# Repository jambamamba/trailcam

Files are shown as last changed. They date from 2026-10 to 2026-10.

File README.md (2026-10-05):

# Wapiti Trail Camera

Wapiti is an open-hardware cellular trail camera built for the harshest hunts: a 4K-capable IMX415 (8.4 MP) sensor on an SSC377Q SoC, an EG915U LTE Cat-1bis modem with GNSS and eSIM, and an ESP32-C6 wake supervisor that owns the heartbeat, PIR/radar wakeups and cold-start power sequencing. It runs through −40 °C on drawer batteries plus solar (with a sub-zero charge interlock), backed by a 5 F supercap that rides through radio bursts. A mitten-friendly hi-vis battery drawer swaps packs in seconds, dual 940/850 nm IR illuminators cover day and night, and an LD2410 mmWave radar confirms presence before the main SoC ever wakes up. Tree straps and a ¼-20 tripod boss mount it to any tree; BLE-gated on-demand Wi-Fi pulls photos straight to a phone at the camera — no LTE data, no coverage needed. Every photo and clip is encrypted at rest with per-device keys, so a stolen camera or SD card yields hardware, never your media. Every artifact in this repo — schematics, footprints, PCB, chassis and renders — regenerates from Python scripts.

<p align="center">
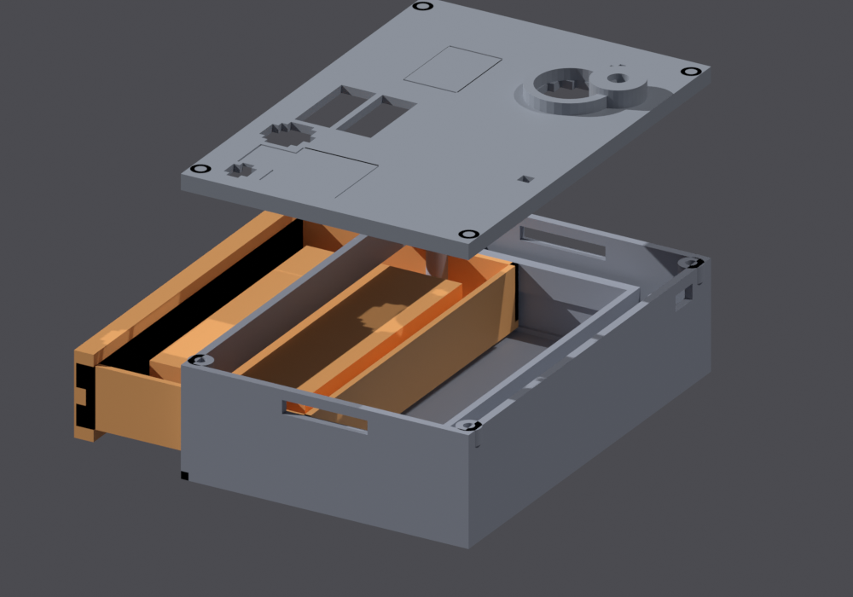
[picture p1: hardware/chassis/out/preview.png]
  
  <br><em>Exploded chassis view (lid, base, battery drawer). STLs, drawings and regeneration commands in the <a href="hardware/README.md">hardware guide</a>.</em>
</p>

## Documentation

| Document | What's inside |
| --- | --- |
| [Project plan](docs/project-plan.md) | Architecture, BOM & power budget (§4), Yocto firmware plan (meta-wapiti / yocto-cam) |
| [Test plan](docs/test-plan.md) | 301 test IDs across all subsystems, incl. YOCT-01…06 firmware bring-up |
| [Competitive analysis](docs/competitive-analysis.md) | Positioning vs Tactacam Reveal and peers; −40 °C power strategy (§4.2), mitten-swap chassis (§4.13) |
| [Tactacam Reveal research report](docs/tactacam-reveal-hunt-cameras-product-research-report.md) | Product research on the market-leading cellular trail camera |
| [Hardware guide](hardware/README.md) | Schematic/PCB/chassis artifacts, regeneration commands, PCB↔chassis mapping, Value SKU (wapiti-lite) |

## Quick facts

- **Product:** cellular trail camera, 4K / 8.4 MP, radar-confirmed instant wakeups.
- **Value SKU:** **wapiti-lite** — same board with the LD2410 radar assembled DNP.
- **Connectivity:** EG915U LTE Cat-1bis + GNSS, eSIM out of the box.
- **Power:** solar input with a <0 °C charge interlock, 5 F supercap ride-through for radio bursts.
- **Enclosure:** 108 × 74 × 33 mm chassis with 0.8 mm RF-window membranes; hi-vis mitten-swap battery drawer.
- **Firmware:** Yocto Linux — `meta-wapiti` BSP + `yocto-cam` image.
- **Reproducibility:** everything regenerates from the scripts in [`hardware/`](hardware/README.md) — no manual KiCad edits.

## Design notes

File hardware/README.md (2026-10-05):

# wapiti hardware — generated KiCad + 3D-printable chassis

Everything in this directory is **generated from Python** (no hand-edited CAD), using the same
approach as the `luggage-tracker` LT-1: emitters write KiCad s-expressions with symbols embedded
inline (lib prefix `wapiti:`), custom footprints go to `wapiti.pretty/`, and `kicad-cli` validates
the results. Hardware stays reviewable in diffs and regenerable from the BOM in
[project-plan §4–5](../docs/project-plan.md).

wapiti chassis — base, lid and hi-vis battery drawer

wapiti PCB — front copper, silkscreen, outline

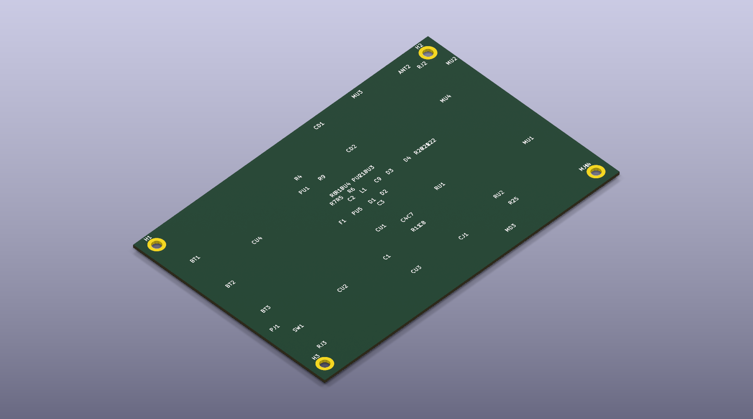
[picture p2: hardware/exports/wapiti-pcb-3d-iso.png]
wapiti PCB — 3D render (isometric)


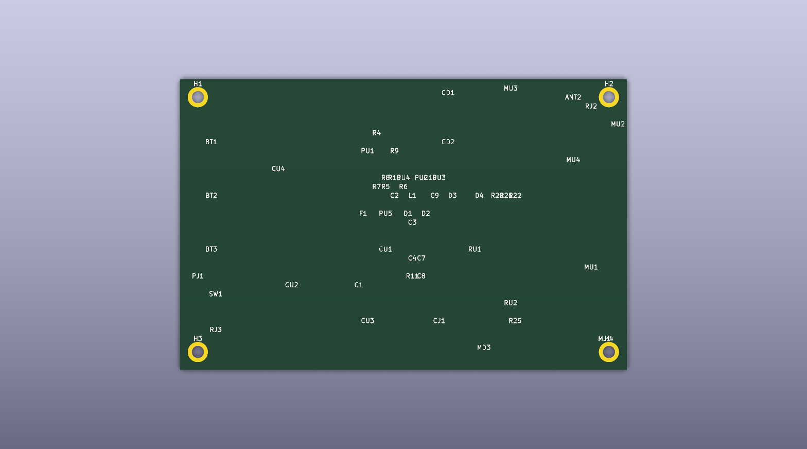
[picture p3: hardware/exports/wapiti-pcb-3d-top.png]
wapiti PCB — 3D render (top)


## Artifacts

| Artifact | Produced by | What it is |
|---|---|---|
| `wapiti.kicad_sch` | `gen_schematic.py` | Root sheet with 4 child sheets (power / radio / cam / mcu) |
| `power.kicad_sch` | `gen_schematic.py` | BT1 smart 2S pack (Pack_Conn_5p: pack-ID + BQ27441 + thermistor), BT2 12×AA Li-FeS₂ tray, BT3 CR2032 anti-theft reserve, C1 5 F supercap ride-through (mitten swap), F1/F2 PTCs, D1/D3/D4 SS54 OR-ing, D2 TVS, J1 solar + U4 interlock (SOLAR_OK < 0 °C = PWR-08), U1 buck → V_SYS 3.8 V, U2/U3 load switches (EN_CAM/EN_MODEM from the C6), U5 gauge |
| `radio.kicad_sch` | `gen_schematic.py` | U1 EG915U LTE Cat-1bis + GNSS, U2 eSIM, J2 user-replaceable SMA (CAM-14), ANT2 GNSS patch under the lid RF membrane, J3 USB-C service |
| `cam.kicad_sch` | `gen_schematic.py` | U1 SSC377Q SoC, U2 IMX415 8.4 MP module, U3 eMMC + J1 microSD overflow, U4 2.0″ SPI LCD, D1/D2 IR arrays (940 nm no-glow / 850 nm low-glow) on Q1/Q2 low-side MOSFETs with 100 k gate pulldowns (dark through boot) |
| `mcu.kicad_sch` | `gen_schematic.py` | U1 ESP32-C6-WROOM-1 wake supervisor (owns the heartbeat HB-01..08), U2 LIS2DW12 (ACCEL_INT tamper wake), U3 AS312 PIR, U4 LD2410 radar (**value-SKU DNP candidate**), R25 + D3 status LED, SW1, J1 2×03 factory-programming header, J2 USB-C |
| `verify_schematic.py` | — | Union-find net verifier over the generated sheets (headless, no KiCad needed) |
| `wapiti.pretty/*.kicad_mod` | `gen_footprints.py` | 30 footprints (Pack_Conn_5p, EG915U, ESP32-C6-WROOM-1, SSC377Q_QFN, IMX415_Module, eMMC_153, microSD_Push, LCD_2in_FPC, IR_Array_30x10, PIR_Dome, Radar_LD2410, Diode_SMA for the SS54s, …) |
| `wapiti.kicad_pcb` | `gen_pcb.py` | 100 × 65 mm board, 58 placed footprints + 4 mounting holes, F.Cu zone, F.Fab front-panel-optics + antenna keep-outs |
| `wapiti.kicad_pro`, `fp-lib-table` | `gen_pcb.py` | Project file + footprint-lib registration via `${KIPRJMOD}` |
| `exports/` | `validate.sh` | `wapiti-pcb.svg`, per-sheet PDFs, `wapiti.step` (PCB 3D) |
| `exports/wapiti-pcb-3d-{top,iso}.png` | `kicad-cli pcb render` | PCB 3D screenshot, top + isometric (quality `high`) |
| `chassis/out/wapiti-{base,lid,tray}.{stl,obj}` | `chassis/gen_chassis_stl.py` | 3D-printable chassis + battery drawer; side-wall strap slots + lid ¼-20 boss (constructive geometry, no booleans) |
| `chassis/out/preview.svg`, `preview-plan.svg` | `chassis/gen_preview_svg.py` | Isometric (lid +45 z, drawer pulled −Y) and top-down interior previews |
| `chassis/gen_chassis.py` | — | Blender batch **renderer**: imports the verified STLs → `out/preview.png` (exploded), `out/preview-assembled.png`, `out/preview-top.png` |

## Regenerate

```bash
cd hardware
python3 gen_schematic.py       # 5 schematic files (root + power/radio/cam/mcu)
python3 verify_schematic.py    # -> "All schematic net checks passed"
python3 gen_footprints.py      # wapiti.pretty/ (30 footprints)
python3 gen_pcb.py             # wapiti.kicad_pcb + .kicad_pro + fp-lib-table
bash validate.sh               # kicad-cli export -> exports/  (needs KiCad AppImage)
# PCB 3D screenshot (KiCad 10):
kicad-cli pcb render --output exports/wapiti-pcb-3d-top.png --side top \
  --background opaque --quality high wapiti.kicad_pcb
kicad-cli pcb render --output exports/wapiti-pcb-3d-iso.png --rotate "-45,0,45" \
  --background opaque --quality high wapiti.kicad_pcb

cd chassis
python3 gen_chassis_stl.py     # out/wapiti-{base,lid,tray}.{stl,obj}
python3 gen_preview_svg.py     # out/preview.svg out/preview-plan.svg
~/Downloads/blender-5.2.0-linux-x64/blender -b -P gen_chassis.py   # out/preview*.png
```

Current status: schematic net verification passes; `validate.sh` was run and `exports/` contains
the SVG/PDF/STEP outputs; the chassis STLs parse cleanly (binary STL, exactly `84 + 50·n` bytes)
and Blender 5.2 rendered all three PNG previews headlessly on CPU (~10–15 s/frame; never call
`cycles.preferences.get_devices()` — GPU enumeration segfaults inside libsycl on this machine).

## Value SKU (wapiti-lite)

The Pro reference generated here populates everything. The cost-down is a two-line edit, then
regenerate: set `DNP_REFS = {("U4", "RADAR")}` in `gen_schematic.py` and `DNP_REFS = {"MU4"}` in
`gen_pcb.py` — the LD2410 mmWave radar drops off the BOM and its lid window keeps its 0.8 mm
membrane (weathering is unchanged).

## PCB ↔ chassis coordinate mapping

The chassis is **centered on the board**: PCB coordinates from `gen_pcb.py` are `0..100 × 0..65`,
chassis coordinates are `x = px − 50`, `y = py − 32.5`, with `z = 0` at the floor bottom.
Outer chassis: 108 × 74 × 33 mm (2 mm walls; the paddle lever stands 3 mm proud of the −Y face).
Board bottom sits at z = 19.5 on 17.5 mm bosses, above the battery drawer bay.

| Feature | PCB (px, py) | Chassis | Notes |
|---|---|---|---|
| Battery drawer bay | BT1/BT2/BT3 area | bay x −48..48, y −35..21, z 2..18.8 | 2S smart-pack insert; slides out the **−Y wall** on side rails |
| Paddle lever (§4.13) | — | full drawer width, y −40..−35.5, z 3..18.5 | One-motion pull; grip groove 8.5..12.5 z; hi-vis interior (renders orange) |
| Drawer rails / guides | — | rails x ±47..48 (z 2..3.2), guides z 12..18.8 | Lead-in steps at the mouth self-align the drawer (wedge) |
| USB-C service (RJ3) | (8, 60) | (−42, 27.5), cutout in **+Y** wall | 7.5 × 4.0 mm at z 21..25 |
| Button (SW1) | (8, 52) | (−42, 19.5) | Ø4.6 mm hole through the lid |
| Status LED (MD3) | (68, 64) | (18, 31.5) | Light pipe through the lid |
| IMX415 lens (CU2) | (25, 50) | (−25, 17.5) | Ø16 mm lid port + 3 mm seat boss |
| IR arrays (CD1/CD2) | (60, 7), (60, 18) | (10, −25.5), (10, −14.5) | Lid windows x −4..17 |
| PIR dome (MU3) | (74, 6) | (24, −26.5) | Ø11.5 mm hole |
| Radar patch (MU4) | (88, 22) | (38, −10.5) | Under the lid 0.8 mm membrane (DNP on lite) |
| SMA LTE antenna (RJ2) | (96, 6) | (46, −26.5) | Ø7 mm bulkhead through the lid — user-replaceable (CAM-14) |
| GNSS patch (ANT2) | (88, 8) | (38, −24.5) | Under the lid **0.8 mm RF membrane**, x 32..42 |
| PCB bosses / lid posts | holes (4/96, 4/61) | bosses (±46, ±28.5), posts (±49.5, ±34.5) | M2.5-class self-tap drills |
| Strap slots (tree webbing) | — | both ±X walls, y −11..11, z 22..25.5 | 22 × 3.5 mm slot, 2 in webbing; wraps the tree vertically, PQT-08 |
| ¼-20 tripod boss | — | lid (−30, 27), Ø13 mm, 4.5 mm tall | Standard camera-screw mount for tripod arms/brackets (§5.3) |

### RF window rationale

The lid carries a **0.8 mm plastic-only membrane** over the GNSS patch (x 32..42, y −29..−20) and
the radar window (x 28..48, y −20..−1), directly above ANT2 and the LD2410 patch. Any thicker a
dielectric stack — or a metal fastener over either antenna — costs dB exactly where the
Cat-1bis/GNSS link budget has none to spare. The lid infill is a 1.5 mm grid **with holes** (not a
solid plate) so it cannot act as a ground plane over the antennas; keep-outs are also marked on
F.Fab in `wapiti.kicad_pcb`.

### Mitten-swap wedge (§4.13)

The battery drawer is the one-motion swap: pull the full-width hi-vis paddle (3 mm proud, grip
groove at mitten height) and the drawer rides out on side rails with lead-in steps that
self-align reinsertion. The 5 F supercap on V_SYS keeps the C6 heartbeat and RTC alive through
the swap (PWR-07), and the pack's ID/thermistor pins on `Pack_Conn_5p` are read before the buck
re-enables. ≥20 mm clear grip geometry, no tools, gloved hands (HT-xx cases in the test plan).
The 12×AA Li-FeS₂ tray and Arctic LTO wedge are alternate inserts for the same rails.

### Tree mount (strap + ¼-20)

Two horizontal **strap slots** pierce both side walls (y −11..11, z 22..25.5 — above the drawer
bay, below the lid), sized for 2 in (50 mm-class) webbing straps: the strap wraps the tree
vertically through both slots, cinches flat against the back, and the slot lips carry the load
(no hook hardware). The paddle's under-flange doubles as a hang hook on the strap. On the lid, a
**1/4-20 UNC tripod boss** (Ø13 mm × 4.5 mm, printed solid with a Ø5 pilot to drill/tap, or a
heat-set brass nut) takes any standard camera bracket. Pull/torque evidence: **PQT-08** in the
test plan.

### Schematic net discipline (for future edits)

`gen_schematic.py` emits every wire endpoint from a pin tip via `tip()` helpers — never hand-typed
coordinates — and uses net labels at pin tips for nets crossing symbol bodies. After any change
run `python3 verify_schematic.py` (union-find over pin positions): it fails loudly on floating
pins, with `ALLOWED_NC` whitelisting the deliberate no-connects (eSIM VPP, USB CC/VBUS pins).
Cross-sheet nets (UART_RX/TX, EN_CAM, PERST, SOLAR_OK, …) are label-matched by name.

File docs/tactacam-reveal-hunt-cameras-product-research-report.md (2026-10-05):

# Tactacam REVEAL Hunt Cameras — Product Research Report

**Company:** Tactacam LLC · Decorah, Iowa, USA · tactacam.com
**Report date:** October 3, 2026
**Scope:** Study of https://www.tactacam.com/hunt-cameras (the REVEAL cellular trail camera lineup): company context, deep-dive specs of the current models, pros/cons, third-party reputation, and a head-to-head comparison against the 2026 cellular trail camera field (price, data plans, trigger speed, flash, power, and anti-theft features).

---

## 1. Executive Summary

Tactacam (founded 2013, Decorah, Iowa) is a U.S.-based outdoor-tech maker that pivoted from point-of-view hunting cameras into **cellular trail cameras**, launching the **REVEAL** brand in 2020. The company has grown to **500+ employees**, **1.5 million customers** running **over 2 million cameras** (Inc. Regionals: Midwest #25, April 2025), and claims the **#1 trail camera app**. Its portfolio now spans REVEAL (cellular trail cams), **Defend** (4G security cams), and **FeatherSnap** (bird-feeder cams).

The page studied — **tactacam.com/hunt-cameras** — is the REVEAL storefront, currently listing 12 items built around the **July 2026 "4.0" generation** (X 4.0 at $129.99 and Pro 4.0 at $159.99, plus a Pro 4.0 Solar bundle at ~$200) with the older 3.0 models and the $199 REVEAL Ultra either sold out or being phased out. All REVEAL cameras are multi-carrier LTE devices with built-in GPS, 4K photo / 1080p video, 8 GB internal storage (SD optional), and a brand-new modular **FlexPack™ power system** (12×AA tray, or rechargeable R5 5,000 mAh / R10 10,000 mAh packs, plus solar). Service runs **$5–$13/month per camera** — among the cheapest plans in the industry — with Live View and on-demand video gated behind an add-on subscription.

**Verdict in one line:** REVEAL is the value-to-feature leader of the 2026 cellular trail camera market — Outdoor Life named the Pro 4.0 Solar **Best Overall** and Field & Stream named the Ultra **Best Overall of 2025** — with the industry's cheapest data plans, best-in-class anti-theft GPS (Ultra), and a genuinely modular power system; the trade-offs are short 1-year warranty, battery life that depends heavily on settings, feature paywalls, and a thin Trustpilot footprint (2.1/5, 9 reviews).

---

## 2. Company & Product Context (studied from tactacam.com)

### 2.1 The company
| Fact | Detail |
|---|---|
| Founded | 2013 (first product: Tactacam point-of-view hunting camera) |
| HQ | Decorah, Iowa, USA — 1668 Jordan West (footer of tactacam.com) |
| People | Jeff Peel, co-founder / CEO; 500+ employees (2025) |
| Scale | 1.5M customers; 2M+ cameras globally (Apr 2025); servers sized for 10M+ photos/day |
| Growth honors | Inc. 5000 (2024); Inc. Best in Business (2024); Inc. Regionals Midwest **#25** (2025); Fast Company "Top 100 Workplaces for Innovators" (Oct 2025) |
| Customer support | U.S.-based team, 1-year warranty from activation, "Tactacam Recaptured" refurb/recall program |
| Ecosystem | REVEAL app (iOS/Android) + web portal (account.revealcellcam.com); OTA firmware updates; machine-learning photo features |

### 2.2 Product family timeline & the current lineup
| Year | Release |
|---|---|
| 2013 | Original Tactacam POV hunting camera |
| 2020 | **REVEAL** cellular trail camera launched (flagship brand) |
| 2021 | REVEAL XB, SK |
| 2022 | REVEAL X 2.0, X Pro |
| 2023–24 | REVEAL X 3.0, Pro 3.0, X-Pro 3.0 |
| Jun 2025 | **REVEAL Ultra** ($199): live video streaming, Active-GPS anti-theft, switchable low/no-glow flash; Folding Solar Panel ($99.99) and Battery Belt ($119.99, 14,700 mAh) accessories |
| Jul 2026 | **4.0 generation**: X 4.0, Pro 4.0 (+ Solar bundle), FlexPack R5/R10 power system, R5 solar bundle; Pro 3.0/X 3.0/2-packs/REVEAL Ultra listed **out of stock** on the studied page |
| Other brands | **Defend** (4G security cameras), **FeatherSnap** (smart bird-feeder camera) |

> **Why REVEAL is "the" product line:** it is Tactacam's flagship and best-seller, it anchors the subscription business (the recurring-revenue engine), and the 4.0 refresh in July 2026 is the company's most significant hardware/platform update — dual image sensors, FlexPack modular power, side-facing LCD, and app-gated Live View.

---

## 3. Product Deep-Dive: The REVEAL Hunt Camera Lineup

### 3.1 What they are
> "Scout smarter, not harder. Tactacam REVEAL cellular trail cameras … deliver optimized real-time wildlife monitoring right to your phone." — tactacam.com/hunt-cameras

Cellular trail cameras: motion-triggered, weatherproof cameras that send photos (and, with subscriptions, video/live streams) over LTE to the REVEAL app from anywhere. The pitch replaces the "SD-card camera walk" — no more weekly trips to pull cards. All models: built-in GPS, multi-carrier auto-select LTE ("Major Cellular Networks"), integrated SIM, 8 GB internal storage + optional SD slot, 4K photo / 1080p video, 12×AA or FlexPack power, 12 V DC external input, 1-year warranty.

### 3.2 Model-by-model (current page + recent)

**REVEAL X 4.0 — $129.99** ("the reliable workhorse")
- 4K photo (UHD) / 2.5K (WQHD) / 1080p video; low-glow IR, 96′ flash range
- Simultaneous photo + video on one trigger; on-demand video* and Live View* (subscription add-ons)
- Built-in GPS, auto-carrier selection, wireless connectivity to REVEAL accessories
- FlexPack power: 12×AA tray or R5 (5,000 mAh) / R10 (10,000 mAh) rechargeable packs; DC 12 V-2A input
- No LCD screen (app-based setup)

**REVEAL Pro 4.0 — $159.99** ("our most advanced REVEAL ever") — 4.5★/198 on its Tactacam page
- Everything in X 4.0, plus: **dual image sensors** (silent capture, better day/night), **selectable no-glow (80′) or low-glow (96′) flash**, **side-facing 2″ LCD screen** for setup/aiming, burst mode 3 photos
- 4K (UHD) / 2.5K (WQHD) photos, 1080p video, built-in GPS, auto-carrier selection
- Same FlexPack power system; Solar bundle (~$200) adds R5 pack + solar panel

**REVEAL Ultra — $199 (Jun 2025; out of stock as of Oct 2026)**
- Everything in Pro 3.0 plus: **on-demand live video streaming** (up to 4 min of 1080p per session), **Active GPS anti-theft** (internal reserve battery keeps pinging coordinates every 6 h if moved >½ mile — even after main power dies; Tactacam says "weeks," GearJunkie assumes ~72 h), **switchable low-glow (96′)/no-glow (80′) flash**, proprietary camo pattern, LCD screen
- GearJunkie scored it **8.9/10** (setup 9.8, app 8.9, battery 7.5)

**Legacy 3.0 generation (studied page shows out of stock; still widely sold via retailers)**
- **X 3.0 (~$99.99):** 4K photo/1080p video, low-glow 96′, 3-shot burst, no LCD. Trailcampro scored it **84/100** (picture 89, detection 78, design 80): trigger 0.36 s / recovery 22.1 s, detection 60 ft @ 34.1°, 6.8 months battery on lithium AAs at 30 pics/day (much less in instant-send mode). Made in Vietnam.
- **Pro 3.0 (~$129.99):** X 3.0 + LCD screen, no-glow option, dual sensors; Popular Mechanics' preferred pick over X 3.0.
- **X-Pro 3.0 (~$149.99–$250):** higher-end variant; oneoutdoors.org ranked it Best Overall in its 2026 guide.

* ( asterisk per Tactacam: "Additional subscription required" )

### 3.3 Subscriptions & ecosystem (the real business model)

| Plan | Monthly | Yearly | Photos/mo | Notes |
|---|---|---|---|---|
| Starter | $5 | $55/yr | 250 | Photo pooling across cameras; overage $5/250 photos |
| Intermediate | $8 | $85/yr | 500 | Overage protection available |
| Pro | $13 | $120/yr | Unlimited | Unlimited HD photo & video requests |
| Additional cameras | $5–12/mo (yr 1) | $55–96/yr | — | Multi-camera discounts |
| **Xtra add-on** | $4 (1 cam) / $7 (2) / $9 (3+) | — | — | Unlimited HD photos, on-demand photo requests, enhanced mapping |
| Live View mode | ~$6/mo per camera (per Outdoor Life) | — | — | Live/on-demand video gating |

- **Photo pooling:** allowances are shared account-wide (3 cameras on Starter = 750-photo pool).
- **Accessories:** FlexPack R5 $59.99 / R10 $99.99; R5+Solar bundle $109.99; Folding Solar Panel $99.99 (7.2 W, 2.2 lb); Battery Belt $119.99 (14,700 mAh, IPX66); lockable security box $29.99; V2 solar panel; wind sensor; tree mount.
- **App:** Battery Center (usage summary, solar/external pack performance, battery-saver presets), live aiming via Wi-Fi during setup, OTA firmware, camera sharing, ML species filters.

### 3.4 How it works day-to-day
1. Scan QR code → REVEAL app walks through activation and plan selection ("dummy-proof" — GearJunkie).
2. Camera auto-connects to the strongest cellular network (multi-carrier); photos arrive in the app (standard definition by default; HD on request/Pro).
3. Photo+video simultaneous mode captures stills and clips on the same trigger; Live View (subscription) streams up to 4 min of 1080p on demand.
4. GPS + Battery Center manage camera location and power; solar/FlexPack extend deployments; Ultra continues anti-theft pings even when the main battery dies.

---

## 4. Pros and Cons

### Pros
1. **Cheapest data plans among the majors** — $5/mo Starter and $13/mo unlimited Pro undercut Moultrie ($9.99/$16.99), Spypoint premium tiers, and Spartan ($15.99); GearJunkie: "its subscriptions are among the cheapest on the market."
2. **"Industry's best battery life" claim backed by a real power system** — FlexPack R5/R10 rechargeable packs, solar panel, and Battery Belt (14,700 mAh) form the most complete modular power ecosystem in the category; Trailcampro measured 6.8 months on lithium AAs (moderate settings) for X 3.0.
3. **Best-in-class anti-theft (Ultra)** — the only camera that keeps GPS-pinging after power loss (internal reserve battery, 6-h updates after >½-mile movement). GearJunkie: "the most significant leap in trail camera technology in a decade."
4. **Strong press validation** — Outdoor Life **Best Overall 2026** (Pro 4.0 Solar); Field & Stream **Best Overall Cellular Trail Camera 2025** (Ultra); TechGearLab "best cellular trail camera for most people" (X 3.0); 100% trigger reliability at 10/60 ft in Outdoor Life's walkthrough test (day and night).
5. **Simultaneous photo + video** — zero-delay stills and clips on one trigger; a genuine scouting differentiator in timber.
6. **Selectable no-glow/low-glow flash from the app** (Pro/Ultra) — rare remote-switchable stealth control; rivals force a fixed flash type.
7. **Excellent UX** — LCD screens (Pro/Ultra) for aim-and-verify without Bluetooth fiddling, QR-code onboarding, live aiming, OTA updates, Battery Center, photo pooling, plan pausing in the offseason.
8. **Scale + US-based support** — 2M+ cameras in the field, #1-rated trail camera app, U.S. customer service and warranty operation.

### Cons
1. **Everything premium is behind subscription add-ons** — Live View, on-demand video, HD photos (beyond Pro plan) all cost extra; Xtra adds $4–9/mo more. GearJunkie: "have to pay extra to unlock all features."
2. **1-year warranty from activation** — the category's floor; Trailcampro (which adds its own second year) and Spypoint/Moultrie (2–3 yr on some models) beat it.
3. **Battery life is settings-dependent** — instant-send mode drains fast (Trailcampro: "In Instant mode, battery life is poor"); GearJunkie's weakest score for Ultra (7.5/10); solar/FlexPack are additional purchases.
4. **Product-line churn and availability gaps** — the studied page shows most SKUs out of stock (3.0s, Ultra, 2-packs); TrailCamLab reports the Ultra 3.0 was discontinued alongside the 4.0 launch; Ultra's Active-GPS battery-life docs are inconsistent ("weeks" vs 72 h).
5. **Legacy-model quirks** — X 3.0: sporadic cellular transmission, 22 s photo recovery, no settings from web portal, near-irreplaceable antenna, 16–32 GB U3 SD only, cellular-only use (Trailcampro).
6. **Thin/uneven review footprint** — Trustpilot **2.1/5 (9 reviews)**; older XB failure anecdote (DFW Urban Wildlife); app Store reviews wish for shared-camera notifications; website store ratings are curated (4.5–4.8★, small n).
7. **No free plan** — Spypoint's free 100-photos tier is the entry point Tactacam lacks; the "as low as $5/mo" floor is real but not free.
8. **Compatibility breaks** — Outdoor Life: Pro 4.0 is "not compatible with previous lithium cartridge models" (new FlexPack system); accessory investment resets with each generation.

---

## 5. Reputation & Customer Feedback (third-party sources)

| Source | Signal |
|---|---|
| **Outdoor Life (Sep 2026 test)** | **Best Overall: REVEAL Pro 4.0 Solar** — "$290 package for $200," 100% trigger reliability at 10/60 ft day+night, even IR flash that doesn't blow out close-ups, R5 lasting ~1 month with instant-send + hundreds of photos/week |
| **Field & Stream (Sep 2025)** | **REVEAL Ultra = Best Overall Cellular Trail Camera of 2025** |
| **GearJunkie (Jan 2026)** | Ultra **8.9/10** — "most significant leap in a decade" for anti-theft; cons: battery life, price, feature paywalls, app behind Moultrie's |
| **Popular Mechanics (2026)** | Pro 4.0 tested at $160 (4K photo/1080p video/LTE/12 AA); Pro 3.0 review liked the screen ("if you want to save $30, the X 3.0 ditches the display") |
| **TechGearLab (Aug 2026)** | X 3.0: "the best cellular trail camera for most people" — easy to use, high-quality photos |
| **Trailcampro (lab data)** | X 3.0 **84/100**; 0.36 s trigger; 60 ft/34.1° detection; 6.8 months battery (hybrid, lithium); sporadic transmission; instant-mode battery drain |
| **Tactacam's own store ratings** | Pro 4.0 **4.5★ (198)**; X 3.0 **4.8★ (125)** — curated first-party data |
| **Retail** | Tractor Supply X 3.0 4.5★ (66); Walmart Ultra-variant 4.2★ (45); Amazon X 3.0 ~4.4–4.6★ (100–300 ratings across US/UK/AU/jp marketplaces); "1K+ bought in past month" on Amazon US X 3.0 |
| **Trustpilot** | **2.1/5, 9 reviews** ("Poor") — small sample, but the worst footprint among majors in this study |
| **Forums (Reddit r/trailcam, Rokslide, Crossbow Nation, Facebook groups)** | Generally positive on image quality/signal; recurring themes: durability over multi-year ownership ("Reveal X Pro still working going on year three"), but complaints about battery in instant mode and customer-service wait times; ArcheryTalk positions Tactacam as "a good middle ground between a SpyPoint and a Reconyx" |
| **Press/company honors** | Inc. 5000 + Best in Business (2024), Midwest Regionals #25 (2025), Fast Company Top 100 Workplaces for Innovators (2025) |

**Takeaway:** Professional reviewers are emphatically positive (two consecutive "Best Overall" titles from major outlets, strong lab scores), retail ratings are solid 4.2–4.8★, and the installed base is huge; the negative signals cluster in the subscription-paywall experience, instant-mode battery drain, warranty length, and a small but poor Trustpilot sample.

---

## 6. Competitor Comparison

### 6.1 Like-for-like: cellular trail cameras (2026)

| Product | Hardware price | Plans from | Trigger | Night flash | Power | Notable |
|---|---|---|---|---|---|---|
| **Tactacam REVEAL Pro 4.0 / Solar** | **$159.99** (Solar bundle ~$200 w/ R5+panel) | **$5/mo** ($13 unlimited) | 0.4 s | Low-glow or **no-glow (app-selectable)** | 12×AA / **FlexPack R5/R10** / solar; DC 12 V | Dual sensors, LCD, GPS, Live View*, Outdoor Life **Best Overall 2026** |
| **Tactacam REVEAL X 4.0** | **$129.99** | $5/mo | 0.4 s | Low-glow 96′ | 12×AA / FlexPack / solar | No LCD; value workhorse |
| **Tactacam REVEAL Ultra** | $199 | $5/mo | 0.4 s | Switchable low/no-glow | 12×AA / FlexPack / solar; **anti-theft GPS w/ reserve battery** | Live streaming*; F&S Best Overall 2025; now OOS |
| **Stealth Cam Fusion Max 3** | $150/2-pack ($80 each) | $5/mo (Standard: 600 photos!) | <0.4 s | Low-glow | 16×AA or lithium cartridge | Outdoor Life **Best Value 2026**; species-filter app |
| **Stealth Cam Deceptor Max 3** | $120 | $5/mo | **<0.3 s** (best tested) | No-glow | 16×AA / lithium / solar | Triggered at 110 ft in walkthrough test |
| **Moultrie Edge 4 Solar** | $170 | $9.99/mo ($12.99 unlimited) | 0.4 s | Low-glow | **Built-in solar + rechargeable pack** | 40 MP, all-HD delivery, best-in-class app; battery-latch QC gripe |
| **Spypoint Flex-M2** | $100/2-pack ($50–80 each) | **Free (100 photos)**; $5–15/mo | 0.4 s | Low-glow | 8×AA or pack | Only true free tier; 2-yr warranty; transmit delays, mediocre battery |
| **Spartan GoLive 2** | $190 | $15.99/mo | 0.4 s | No-glow | 12×AA / 12 V / solar; internal Li | True 30 FPS live stream; exposure/blur issues; 2-yr warranty |
| **Browning Defender Pro Scout** | ~$300 | n/a | — | — | — | Premium image quality pick (oneoutdoors.org) |
| **Reconyx (cellular)** | $$$ (premium) | carrier-dependent | class-leading | — | — | The "overbuilt" benchmark ArcheryTalk measures everyone against |

### 6.2 Data-plan economics (per-camera, monthly)

| Brand | Cheapest | Mid | Unlimited |
|---|---|---|---|
| **Tactacam REVEAL** | **$5** (250 photos) | $8 (500) | **$13** (+ Xtra $4–9; Live View ~$6) |
| Spypoint | **Free** (100) | $10 (1,000; Insider $8) | $15 (Insider $12) |
| Stealth Cam | $5 (600) | $8 (1,200) | $20 (multi-cam discounts to $8) |
| Moultrie | $9.99 (1,000 + 10 videos) | — | $16.99 (unlimited + 50 videos); Pro Series $34.99 first cam then $7.99 each |
| Spartan | $15.99 shared (up to 3 cams) | prepaid $64.99–199.99 | — |

**Read-through:** Tactacam wins the low end ($5) and is near the top for unlimited value ($13 with unlimited HD/VD requests on Pro, vs Moultrie $16.99 with video caps and Stealth Cam $20). Spypoint's free tier is the only $0 entry. Multi-camera economics favor Stealth Cam's deep discounts; Moultrie's Pro Series flips cheap for 4+ camera camps.

### 6.3 Where REVEAL wins and loses head-to-head
- **Wins:** price-per-feature (Outdoor Life: "$290 package for $200"), subscription pricing, power-accessory ecosystem, simultaneous photo+video, app-switchable flash, anti-theft GPS (Ultra, unique).
- **Loses:** Stealth Cam on trigger speed and included-plan generosity ($5 = 600 photos vs Tactacam's 250); Spypoint on free-tier entry, 2-yr warranty, and per-unit price; Moultrie on app depth and integrated-solar simplicity; Spartan on true-live-stream quality; Reconyx on overkill durability.

---

## 7. Comparison Verdicts

- **Best overall for most hunters (2026):** **REVEAL Pro 4.0 Solar** — the bundle math (camera + R5 + solar at $200) plus $5–13 plans make it the default recommendation; Outdoor Life and TechGearLab agree with the calculus.
- **Best budget cell cam:** **Stealth Cam Fusion Max 3** 2-pack ($75/camera, 600 photos on $5) or **Spypoint Flex-M2** ($50/camera in bulk, free tier).
- **Best for public-land/theft-prone spots:** **REVEAL Ultra** — the reserve-battery Active GPS is unmatched; buy while stock lasts (it's being superseded).
- **Best app/night-image package:** **Moultrie Edge 4 Solar** — pay $4–5/mo more per camera for HD-everything and the deepest app.
- **Best live-video streamer:** **Spartan GoLive 2** — but $16/mo plans and exposure quirks; Tactacam's Live View add-on is the value alternative.
- **Premium/no-compromise:** Reconyx — when "buy once, cry once" outweighs the plan math.

---

## 8. Key Sources

- **Tactacam.com (primary, Oct 3, 2026):** /hunt-cameras (lineup page + comparison chart), /reveal-pro-4-0, /reveal-x-4-0, /our-story (company highlights/vision), /newsroom/post/reveal-ultra-cellular-trail-camera-launch (Jun 12, 2025 — Ultra specs, solar panel, battery belt), /newsroom/post/inc-story (Apr 1, 2025 — 500 employees, 1.5M customers, 2M+ cameras), homepage (Pro 4.0 price), /reveal-x-3 (X 3.0 rating)
- **Tactacam help center:** "Understanding REVEAL Cellular Data Plans and Xtra Add-Ons" — plan tables, pooling, overage, Xtra pricing
- **Outdoor Life — "The Best Cellular Trail Cameras" (Sep 25, 2026):** 2026 test, walkthrough data, plans comparison table, Pro 4.0 Solar Best Overall
- **GearJunkie — Tactacam Reveal Ultra review (Jan 14, 2026):** 8.9/10, Active GPS mechanics (½-mile trigger, 6-h updates, 72 h–weeks), setup score 9.8
- **Trailcampro — Reveal X 3.0 lab review:** 84/100, 0.36 s trigger, 60 ft detection, 6.8-month battery math, power consumption, cons list; Pro 4.0 Solar combo review
- **Field & Stream (Sep 10, 2025 / Pro 3.0 review):** Ultra Best Overall 2025; Pro 3.0 verdict
- **Popular Mechanics (Aug 11, 2026 / May 1, 2026):** Pro 4.0 and Pro 3.0 test summaries
- **TechGearLab (Aug 18, 2026):** X 3.0 "best for most people"; 2026 trail camera rankings
- **Press/wire:** Bowhunter.com and Game&Fish (Jul 16, 2026, 4.0 launch + FlexPack R5 $59.99/R10 $99.99 MSRPs), OutdoorWire (Sep 3, 2026, Pro 4.0 Solar availability)
- **TrailCamLab (Aug 25, 2026):** REVEAL Ultra 3.0 discontinued with 4.0 launch
- **Retail ratings:** Tractor Supply (4.5★/66, X 3.0), Walmart (4.2★/45, Ultra variant), Amazon US/UK/AU/JP (4.4–4.6★, 134–312 ratings, X 3.0)
- **Trustpilot:** tactacam.com 2.1/5 (9 reviews); community: Reddit r/trailcam, Rokslide, Crossbow Nation, ArcheryTalk, Facebook REVEAL groups
- **oneoutdoors.org (2026 guide):** X-Pro 3 Best Overall ($250), Spypoint Flex M Best Value, Browning premium pick

*Note on numbers: Tactacam's own store ratings (4.5–4.8★) are first-party and curated; third-party retail ratings (4.2–4.6★, larger n) and Trustpilot (2.1/5, n=9) are included for balance. The Ultra's Active-GPS reserve-battery duration is inconsistently documented by Tactacam itself ("weeks" on one page, 72 h elsewhere — GearJunkie flagged this); both figures are reported. 3.0-generation prices (~$99.99/$129.99) reflect retailer listings since the studied page shows them out of stock without prices.*

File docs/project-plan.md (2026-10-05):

# PROJECT.md — Trail Camera

Working name: **wapiti** (repo: `trailcam`). A cellular trail camera product built around a **4K low-power camera SoC + LTE Cat-1bis + BLE/Wi-Fi co-processor**, a **−40 °C-rated, mitten-swappable power system**, a **Laravel + MongoDB** web application with **WebAuthn passkey** login, an **MCP server** exposing cameras to AI agents, and **iOS/Android apps (Expo React Native)** + PWA. The product wedge is **verifiable reliability**: heartbeat + dead-camera detection, honest battery math, delivery-latency honesty, and support as a feature (`competitive-analysis.md` §4).

Modeled on:
- The five-sprint program shape, work-item numbering, domain-model conventions, and MCP layer of **luggage-tracker** (`/repos/www/luggage-tracker/docs/project-plan.md`) — our closest sibling (battery-powered LTE device + Laravel cloud + MCP).
- The camera-hardware lessons of **wificam** (`/repos/www/wificam/docs/project-plan.md`): ESP32-CAM class hardware caps at 2 MP/OV2640 — a 4K parity product needs a real camera SoC.
- The **Yocto platform pattern** of **wificam §2.2** (`meta-wificam` product layer on a hardened substrate, SWUpdate A/B, read-only rootfs): reused here via a `meta-wapiti` layer. The Jetson substrate itself is not reusable (L4T/CUDA-specific), so the trailcam gets its own machine-agnostic `yocto-cam` substrate + BSP layer.
- The Laravel/MongoDB + nginx + WebAuthn + Docker service-group stack of **blip.io / wificam / luggage-tracker**.

**Product basis.** `tactacam-reveal-hunt-cameras-product-research-report.md` (parity spec + competitor pricing) and `competitive-analysis.md` Rev B (pain points → solutions; −40 °C power system §4.2; mitten-swap chassis §4.13).

---

## Table of Contents

1. [Goals & non-goals](#1-goals--non-goals)
2. [Competitive feature matrix — copy, match, and leapfrog](#2-competitive-feature-matrix)
3. [High-level architecture](#3-high-level-architecture)
4. [Hardware inventory & bill of materials](#4-hardware-inventory--bill-of-materials)
5. [Power architecture (−40 °C) & chassis design](#5-power-architecture--40-c--chassis-design) — incl. §5.4 BLE-gated local download
6. [Domain model & first-class objects](#6-domain-model--first-class-objects)
7. [Tiers, RBAC & sharing](#7-tiers-rbac--sharing)
8. [Data & control flows](#8-data--control-flows)
9. [Server stack (Laravel + MongoDB + nginx)](#9-server-stack)
10. [Authentication (WebAuthn)](#10-authentication-webauthn)
11. [AI & MCP layer — the differentiator](#11-ai--mcp-layer)
12. [Sprint plan (S1 → S5)](#12-sprint-plan)
13. [Certifications & compliance](#13-certifications--compliance)
14. [API surface](#14-api-surface)
15. [Security posture](#15-security-posture)
16. [Testing plan (summary)](#16-testing-plan-summary)
17. [Deployment & operations](#17-deployment--operations)
18. [Directory layout](#18-directory-layout)
19. [Risks & open questions](#19-risks--open-questions)

---

## Implementation Status

Not started; planning docs complete. Status legend: `[x]` done · `[~]` in progress · `[ ]` not started.

| Component | Status | Notes |
|---|---|---|
| Research + competitive analysis | `[x]` Done | `tactacam-reveal-…-report.md`, `competitive-analysis.md` (Rev B) |
| project-plan / test-plan | `[x]` Done | This file + `test-plan.md` |
| Device firmware (camera SoC + C6) | `[ ]` | Yocto Linux (`meta-wapiti` on `yocto-cam` substrate) + Zephyr on C6; bring-up S2 |
| Device simulator (`sim/`) | `[ ]` | Photo/report simulator for cloud work without hardware |
| Laravel scaffold + WebAuthn (AUTH) | `[ ]` | Reuse wificam/lugtrax WebAuthn contract verbatim |
| MongoDB schema + migrations | `[ ]` | 13 collections (§6) |
| nginx site + service group | `[ ]` | `trailcam-server` case, port **4440** |
| Ingest API (`/device/v1/*`) | `[ ]` | Device bearer auth, config/commands piggyback |
| Heartbeat + dead-camera engine (the wedge) | `[ ]` | S3 — firmware critical path |
| MCP server (`/mcp`) | `[ ]` | Official Laravel MCP package, S3 |
| OTA campaigns | `[ ]` | Signed A/B firmware, staged rollout |
| Mobile apps (Expo) | `[ ]` | S4; PWA ships first (S3) |
| Certification program (§13) | `[ ]` | Kick off S1 — radio lead times 6–9 months |

---

## 1. Goals & non-goals

### Goals
- **Parity or better on the 2026 spec floor** (`competitive-analysis.md` §2): 4K photos / 1080p video, simultaneous photo+video on one trigger, app-selectable no-glow (80′)/low-glow (96′) IR, multi-carrier LTE with auto-carrier selection, 8 GB internal + microSD, GPS, LCD aiming screen, QR onboarding ≤ 5 min.
- **−40 °C operation, published and tested.** Full function (boot, PIR wake, capture, upload) at −40 °C; battery forecast derates on weather. Charging interlocks below 0 °C. Nobody in the category publishes a tested minimum (§2, "Cold rating" row).
- **Mitten-swappable battery** (`competitive-analysis.md` §4.13): one-motion slide rail + full-width paddle ejection; bench gate = **one-hand gloved swap < 20 s at −40 °C**, printed on the box. Supercap ride-through preserves RTC/settings/heartbeat during swap.
- **The wedge — heartbeat + dead-camera detection:** every camera checks in on schedule (daily minimum, hourly default); a missed check-in pushes an app/email alert the same day with battery + last-photo context; camera status `healthy / at-risk / silent`.
- **Honest battery:** weather-adjusted weeks-remaining forecast in the app; instant-send trade shown live; chemistry auto-detect via smart-pack ID (NiMH warns, alkaline advises).
- **False-trigger discipline:** PIR + radar fusion and on-device AI classify (deer/turkey/human/vehicle/empty) *before* upload; empty frames never consume plan photos.
- **Honest delivery:** store-and-forward with per-camera latency status ("usually < 60 s; degraded — tower congestion"); median delivery SLA displayed in the app.
- **Honest economics:** Free-forever tier (1 check-in/day + 50 photos/mo, never bricks), one clean paid tier $7.99/mo with **all** camera features included (Live View, on-demand video, HD — no add-on ladder), pause anytime, opt-in capped overage.
- **Support as a feature:** 3-year warranty, advance replacement, published SLAs, diagnostics auto-attached to support chats.
- **AI-native:** MCP server at `/mcp` so agents can ask *"which cameras are at-risk and what walked past Camera 3 last night?"* and *act* (arm, reconfigure cadence). No trail-cam competitor ships this.
- **Accessory stability:** one connector standard; 5-year cross-generation compatibility pledge, published.

### Non-goals (v1)
- **No ESP32 as the camera.** ESP32-CAM-class silicon is 2 MP (OV2640) and cannot meet the 4K parity floor (wificam §3 lesson). ESP32-C6 is our **co-processor** (BLE + Wi-Fi), never the imager.
- **No continuous 30 FPS live streaming** (Spartan-class); Live View = Ultra-style on-demand bursts (≤ 4 min of 1080p).
- **No Wi-Fi-only or 5G SKU.** The buyer is rural; cellular is the product. 5G costs watts we don't have.
- **No megapixel marketing games.** Honest 4K (8.4 MP sensor); no "50 MP interpolated" copy.
- **No multi-brand sprawl** (defend/feeder cams); one excellent camera and one app.
- **No crowdsourced finding network, no two-way audio, no PTZ.**
- **No proprietary lock-in tricks:** no abandoned battery form factors, no carrier-locked SKUs, no features gated behind a second app.

---

## 2. Competitive feature matrix — copy, match, and leapfrog

Condensed from `competitive-analysis.md`; legend ✅ v1 · 🟡 stretch · ❌ not in v1.

| # | Feature (source) | Competitor state | Our plan | Status |
|---|---|---|---|---|
| 1 | 4K photo + 1080p video + simultaneous capture (REVEAL 4.0) | Table stakes | 8.4 MP sensor, real 4K stills + 1080p60, photo+video one trigger | ✅ |
| 2 | App-selectable no-glow/low-glow IR (Pro/Ultra) | Pro-tier only | Both LED arrays, switchable in app | ✅ |
| 3 | Multi-carrier LTE, auto-select (all majors) | Standard | Cat-1bis module, multi-IMSI eSIM bundled, no carrier lock | ✅ |
| 4 | Built-in GPS + move alert (X 4.0/Ultra) | Standard; reserve-battery GPS = Ultra only | GNSS + move alert; **reserve-battery anti-theft GPS** (½-mile trigger, 6 h pings after power loss) | ✅ |
| 5 | Modular power (FlexPack R5/R10) | Tactacam-only, cartridge reset per generation | Smart pack + AA tray + solar, one connector, 5-yr pledge | ✅ |
| 6 | Tested cold rating | **Nobody publishes one** (users ask for −20 °C) | **−40 °C tested, published on box** | ✅ |
| 7 | Glove-operable swap | Nobody designs for it (zip-tie stories) | Paddle-lever slide rail; < 20 s gloved swap gate | ✅ |
| 8 | Heartbeat / dead-camera alert | Nobody (manual "last connection date" policing) | **Our headline feature** | ✅ |
| 9 | Weather-adjusted battery forecast | Nobody (trailcampro publishes lab data, vendors don't) | Forecast + chemistry auto-detect | ✅ |
| 10 | Delivery-latency honesty | Nobody | Per-camera latency status + store-and-forward | ✅ |
| 11 | On-device AI discard of false triggers | Cloud-only filters (Moultrie/Spypoint "Buck Tracker") | Edge classify before upload; empties don't bill | 🟡 (rules S3, ML S4) |
| 12 | Free tier | Spypoint only (100 photos) | Free-forever: 1 check-in/day + 50 photos/mo | ✅ |
| 13 | All-features-included plan | Nobody (Tactacam: 3 tiers + 2 add-ons + Live View fee) | One $7.99 tier, everything on | ✅ |
| 14 | 3-year warranty + advance replacement | Category floor is 1 year | On the box; loaner program for outfitters | ✅ |
| 15 | Signal diagnostics (RSRP, towers, latency) | Nobody (weather shows the *phone's* location) | Diagnostics page + placement coach | ✅ |
| 16 | Replaceable antenna | Nobody (Trailcampro: "about impossible") | SMA external | ✅ |
| 17 | MCP / AI-agent access | Fleet SaaS only, no trail cam | First-class `/mcp` | ✅ |
| 18 | Live video streaming (Ultra 4-min, Spartan 30 FPS) | Pro-tier features | On-demand 1080p bursts ≤ 4 min in base plan | ✅ |
| 19 | Compliance map / public-land mode | Nobody | Legal-layer roadmap item | 🟡 (S6) |
| 20 | Solar SKU (Folding Solar $99.99, Edge 4 built-in) | Standard accessory | 7 W folding panel + charge-temp interlock | ✅ |
| 21 | Crowdsourced/AirTag-style finding | Out of category | — | ❌ |
| 22 | 5G / continuous streaming | Spartan-class | Bandwidth/battery-hostile | ❌ |
| 23 | **Local download to a nearby phone (BLE-gated on-demand AP)** | **Nobody** — media path is LTE-only or card-pull | §5.4: on-demand session, per-session WPA2 key, works with zero coverage, doesn't touch plan data | 🟡 (S4) |
| 24 | **Encrypted-at-rest media (stolen camera ≠ stolen photos)** | **Nobody** — any $12 card reader reads every competitor card | §15.1: per-device AES-256 at rest (eMMC + microSD), theft-revocable keys, paired phone decrypts offline | 🟡 (S3/S4) |

**One-line strategy** (from `competitive-analysis.md`): *everyone sells cameras; nobody sells reliability you can verify — heartbeat, honest battery, −40 °C, mitten swap, one clean plan, 3-year warranty.*

---

## 3. High-level architecture

```mermaid
flowchart LR
    subgraph DEV["Device — wapiti cam"]
        direction TB
        SoC["Camera SoC<br/>Linux · Yocto<br/>capture + AI + upload"]
        Sensor["8.4 MP sensor<br/>+ IR LED arrays"]
        Modem["LTE Cat-1bis<br/>+ GNSS"]
        Coproc["ESP32-C6<br/>BLE + Wi-Fi 2.4G"]
        Pir["PIR + mmWave radar"]
        BAT["Smart pack or<br/>12xAA Li-FeS2"]
    end

    subgraph CLD["Cloud — Laravel + MongoDB"]
        direction TB
        Nginx["nginx<br/>trailcam-server :4440"]
        Laravel["Laravel app"]
        Mongo[("MongoDB<br/>cameras, photos,<br/>detections, alerts")]
        Jobs["Queue workers<br/>heartbeat, alerts, forecast"]
        Mcp["MCP server /mcp"]
        Ota[/"OTA artifacts<br/>signed A-B"/]
    end

    subgraph CLI["Clients"]
        direction TB
        PWA["Browser PWA<br/>React + WebAuthn"]
        App["iOS / Android<br/>Expo RN"]
        Agent["AI agents<br/>MCP clients"]
    end

    Pir -->|"wake"| SoC
    SoC --> Sensor
    SoC --> Coproc
    SoC --> Modem
    BAT --> SoC
    SoC -->|"HTTPS photo + telemetry"| Nginx
    Nginx --> Laravel
    Laravel --> Mongo
    Laravel --> Jobs
    Nginx --> Mcp
    Mcp --> Laravel
    Ota -->|"staged rollout"| Modem
    PWA --> Nginx
    App -->|"BLE pairing + Wi-Fi live aim"| Coproc
    App --> Nginx
    Agent --> Mcp

    classDef device fill:#1b4332,stroke:#40916c,color:#b7e4c7
    classDef power fill:#5c470a,stroke:#d4a017,color:#ffe066
    classDef cloud fill:#0f2a43,stroke:#4d94d0,color:#a8d5ff
    classDef clients fill:#4a2c0f,stroke:#d98e32,color:#ffd9a0
    classDef security fill:#3b1f4e,stroke:#9b59b6,color:#e0c3fc

    class SoC,Sensor,Modem,Coproc,Pir device
    class BAT power
    class Nginx,Laravel,Mongo,Jobs cloud
    class Mcp,Ota security
    class PWA,App,Agent clients

    style DEV fill:#12291a,stroke:#40916c,color:#d8f3dc
    style CLD fill:#0d1f30,stroke:#4d94d0,color:#d0e7ff
    style CLI fill:#2b1c0d,stroke:#d98e32,color:#ffe3c2
```

*Color key: green = device plane · yellow = power · blue = cloud · purple = security surfaces (MCP, OTA) · amber = clients.*

Three planes, lugtrax conventions:
- **Device → cloud:** HTTPS POST of photos + telemetry on PIR trigger, schedule, or check-in; modem in PSM between events; no persistent socket. **The server never wakes the camera** — commands piggyback on the next report response; SMS reserved for urgent anti-theft.
- **Cloud → device:** config deltas, command acks, OTA manifests on report responses; staged OTA pulls.
- **Clients → cloud:** PWA/App via HTTPS sessions (WebAuthn); agents via MCP (streamable HTTP, scoped API keys).

### 3.1 Containerized builds (no compilation on the host)

| Container | Image | Ports | Purpose |
|---|---|---|---|
| `trailcam-server` | `nginx:v5` | **4440** | Laravel + nginx + MCP |
| `trailcam-builder` | `trailcam-builder:v1` | — | One-shot builds; Yocto image build in CI (kas/bitbake → `wapiti-image.swu`) + Zephyr SDK for the C6 |
| `trailcam-test` | `trailcam-test:v1` | — | One-shot Python API suite |
| `trailcam-sim` | `trailcam-sim:v1` | — | Fleet of simulated cameras posting photos/telemetry (test only) |

---

## 4. Hardware inventory & bill of materials

### 4.1 Compute / imaging decision

| Option | Verdict | Why |
|---|---|---|
| **SigmaStar SSC377Q + Sony IMX415 (8.4 MP)** | **Chosen** | 4K@30 H.265 encode, ISP with strong low-light, sub-second wake-to-capture, industry-standard in battery 4K cams; Linux via **Yocto** (`meta-wapiti` on the house platform pattern — §19 R9 covers the vendor-BSP wrap); ~$6–8 SoC + ~$9–12 sensor |
| Ingenic T41 + IMX415 | Alternate | Comparable; Ingenic night ISP is excellent; second-source candidate — **design the carrier so either drops in** |
| Ambarella CV25/S6LM | Rejected v1 | Best AI-ISP class but ~$25–40 and long lead; overkill for v1 edge AI (radar+PIR rules first) |
| ESP32-S3 + OV5640 | **Rejected** | 2 MP-class ceiling — fails 4K parity (wificam evidence); keep ESP32 as co-processor only |

### 4.2 BOM (target ≤ $65 @ 10k units)

| Item | Model / spec | Qty | Est. @10k | Notes |
|---|---|---|---|---|
| Camera SoC | SigmaStar SSC377Q (Ingenic T41 second source) | 1 | $7 | Linux, H.265, fast boot |
| Image sensor | Sony IMX415 (8.4 MP, 4K30, STARVIS low-light) | 1 | $11 | Real 4K (3840×2160) |
| Lens | 6 mm F1.6 IR-corrected, dual IR-cut filter switch | 1 | $3.5 | Day/night true color |
| IR illumination | 940 nm no-glow array (80′) + 850 nm low-glow array (96′), independently switched | 2 | $2.5 | App-selectable = parity + §2 row 2 |
| PIR + Fresnel | AS312-class digital PIR, dual element | 1 | $0.9 | Wake source |
| mmWave radar | 24 GHz motion radar (LD2410-class), optional populate | 1 | $3 | PIR+radar fusion kills false triggers (P5); DNP on cost-down SKUs |
| Co-processor | ESP32-C6 (BLE 5 + Wi-Fi 6 2.4 GHz) | 1 | $2 | BLE pairing, Wi-Fi live-aim/preview, AP-scan diagnostics, watchdog |
| Cellular | Quectel **EG915U** LTE Cat-1bis **+ GNSS combo** (or SimCom A7672SA) | 1 | $11 | Photo-class uplink (5 M UL) vs LTE-M's 375 k; multi-carrier; GNSS on-module saves BOM |
| eSIM | Multi-IMSI consumer eSIM, carrier profiles staged by us | 1 | $2 | Bundled connectivity (lugtrax §6.1.1 pattern) |
| Accel | LIS2DW12 ultra-low-power 3-axis | 1 | $1 | Move alert / theft GPS trigger |
| Fuel gauge + pack ID | BQ27441-class gauge; SHT3x temp/humidity; pack-ID EEPROM | 1 | $2 | Smart-pack telemetry, chemistry auto-detect |
| RTC + supercaps | Low-power RTC + supercap ride-through bank | 1 | $2.5 | Swap without losing time/settings/heartbeat |
| Storage | 8 GB eMMC + microSD slot (UHS-I, no U3-only quirk) | 1 | $4.5 | Internal-first, SD optional |
| PMIC / power tree | Buck/boost, camera rail switches, solar input with **< 0 °C charge interlock** | 1 | $4 | §5 |
| Reserve battery | Small Li primary cell on secondary rail (GPS + RTC only) | 1 | $1.5 | Ultra-style anti-theft ping after main power loss |
| PCB + passives | 4-layer main board + antenna keep-outs | 1 | $8 | SMA antenna connector (§2 row 16) |
| Enclosure | IP67 ABS-PC + TPE overmold, gasket, slide-rail bay, paddle latch, insulated battery bay, hi-vis interior | 1 | $9 | §5 chassis spec |
| Display | 2.0″ side-facing LCD (aim/preview) | 1 | $4 | Parity row |
| Assembly/test/pack | ICT + calibration + box | — | $8 | QR onboarding card, strap, mount |

**BOM ≈ $62–65 @ 10k** → supports **$149 camera** retail; **$199 solar bundle** (camera + 7 W folding panel + standard pack). Accessories: smart pack $49 (5 Ah NMC), Arctic pack $89 (LTO), AA tray $19, security box $29, tree mount $19.

### 4.3 Bench/dev hardware

| Item | Qty | Purpose |
|---|---|---|
| SSC377Q + IMX415 EVK, EG915U EVB, ESP32-C6 devkit | 1 ea | Firmware bring-up before PCBs |
| Cold chamber (or rental slot) + mitten rig | 1 | §5/§13 gates; PQT-COLD suite |
| Power analyzer (µA-class, e.g. Otii/Joulescope) | 1 | Power-budget validation (PWR suite) |
| PIR/radar test rig + range course | 1 | PIR false-trigger regression |

---

## 5. Power architecture (−40 °C) & chassis design

Grounded in `competitive-analysis.md` §4.2/§4.13 (hard requirement: **−40 °C operation; mitten-operable swap**).

### 5.1 Power family

| Option | Role | −40 °C behavior | Notes |
|---|---|---|---|
| **12×AA tray, Li-FeS₂ primary** | Universal fallback, zero-charger | Natively **−40 °C**, 10-yr shelf | Guaranteed-cold path; Trailcampro's 6.8-month basis |
| **Smart pack — standard (low-temp NMC 5 Ah)** | Primary ecosystem pack | Discharge to **−40 °C** (published ~60–70% derate); **charge-locked < 0 °C** with in-app advisory | Fuel-gauge + pack-ID on-pack; USB-C on the pack (camera stays sealed); solar interlock |
| **Smart pack — Arctic (LTO)** | Outfitters / far-north / always-solar | Charges −30 °C, discharges −40 °C flat, 10k+ cycles | ~2× weight for same Wh — sold as a choice |
| NiMH AA | Supported, warned | Voltage sag → early shutoff | Pack-ID/profile derates forecast + warns |
| Alkaline | Discouraged | Cold cliff + leak risk | Advisory on install |
| Sealed built-in · LiFePO₄ · LiSoCl₂ main | Rejected | — | Disposable camera; cold-charge limits; venting |

### 5.2 Power budget (targets, validated by PWR suite)

| State | Target |
|---|---|
| Sleep (PIR + RTC + accel armed) | ≤ 120 µA average |
| Wake-to-capture | ≤ 1.5 s (suspend-to-RAM resume; cold boot is not the hot path) |
| Energy per standard cycle (capture 2.5K JPEG + telemetry + upload) | ≤ 1.1 Wh |
| Energy per 4K cycle (4K still + 1080p10 clip + upload) | ≤ 2.2 Wh |
| Runtime on 12×AA Li-FeS₂ (54 Wh) | ≥ 6 months @ 30 photos/day hybrid; instant-send trade shown in app |
| Runtime on standard 5 Ah pack | ≥ 4 months same profile; solar rig = indefinite |

Heavy-usage planning (per-event Ah, profile table, chemistry prices, Blink/Energizer field findings) lives in `competitive-analysis.md` §4.2; **BAT-01..06 field trials** (test-plan §21.6) replace those estimates with measured burn-down once prototypes run.

### 5.3 Chassis spec (the §4.13 hardware wedge)

- **One-motion slide rail, gravity-assisted:** chamfered lead-in rails, positive click on insert; ejection = **full-width paddle lever** pushable with mitten palm/elbow/numb fingers. No pinch-tabs, no screws, no door-fully-open extraction.
- **Glove geometry:** ≥ 20 mm finger clearance, full-width recessed pull tab, TPE overmold. **Bench gate before design freeze: one-hand gloved swap < 20 s at −40 °C.**
- **Anti-ice:** silicone gasket (won't freeze shut), drip channel, latch breaks ice seal on open, frost-proof chamfered rails, hi-vis orange interior + tactile ridges.
- **Swap survival:** supercap ride-through keeps RTC/settings/heartbeat alive across the ~25 mm slide-out.
- **Spec'd, not hoped:** 500-cycle cold-chamber latch test at −40 °C with simulated mittens; Moultrie's zip-tie story never happens here.
- **Serviceability:** SMA antenna, security-box + python-lock provisions, tree mount ¼-20 + strap.
- **Tree mount as shipped (Rev C):** two strap slots in both side walls (2 in webbing wraps the tree vertically; slot lips carry the load) + a 1/4-20 UNC tripod boss on the lid. Pull/torque evidence: **PQT-08**. Geometry in `hardware/chassis/gen_chassis_stl.py`; see `hardware/README.md` → "Tree mount".
- **Local media download — BLE-gated on-demand AP mode (Rev C, §5.4):** pull 4K photos/clips straight to a phone at the camera — no LTE data, no subscription metering. Detailed plan below.

### 5.4 Local media download — BLE-gated on-demand AP mode

The C6 already carries Wi-Fi 6 for pairing and live-aim; this feature reuses it as a **secure, on-demand file bridge** so a user standing at the camera can pull full-resolution media to their phone in minutes — no LTE data burned, no plan photos consumed, works with zero cellular coverage (deep-canyon sites, plane mode for the flight home).

**Why AP mode, and why it is safe here.** Project posture says "no LAN services on the camera" (§15). AP mode does not violate that if the network **exists only on demand**: never advertises by default, requires BLE proximity to enable, shuts down automatically, and serves one authenticated purpose. The attack surface is a radio that is off 99.9 % of the time and is gated by physical presence.

**Flow (mirrors §8.3 pairing):**
1. User opens the app at the camera → **"Download media"** → app scans BLE → C6 advertises `WAPITI-DL-<device_id>` only while the session window is open.
2. App ↔ C6 BLE handshake: session token `DLT-xxxx-xxxx` (10 min TTL, single use) + media filter request (`from/until/class`).
3. C6 instructs the SoC to start the download service, then enables the AP: SSID derived per session (`wapiti-dl-<short-id>`), **WPA2-PSK key generated per session** (delivered over the encrypted BLE channel — never displayed, never static).
4. Phone joins the AP; the app talks HTTPS to `https://192.168.77.1` with the session token (device-local TLS: the SoC's self-signed cert is pinned via the session token transcript — MITM-safe without a CA).
5. Media streams via `/device/v1/local/media` manifest + chunked range GETs from eMMC/microSD; thumbnails first, then full res on demand.
6. Session ends on completion, user cancel, BLE disconnect + 60 s, or **hard 10-minute cap** — whichever comes first. AP off, service off, radio back to PSM.

**Security gates (all mandatory):** BLE gate (session only creatable over authenticated BLE, which requires the pairing bond from §8.3) · per-session SSID + WPA2 key · TLS with token-pinned self-signed cert · scope = media only (no config writes, no cloud creds on that service) · audit row `local_download` written and synced with the next check-in · rate limit 1 session / 5 min · AP never starts outside a session.

**Power profile:** the C6 AP + SoC file service cost ≈ 1.5–2.5 W for the session; a 5 Ah pack sustains ~10 h of aggregate session time per month — budgeted as `local_dl_s` telemetry and shown honestly in the battery forecast (PWR family).

**Range reality (honesty is the brand):** 2.4 GHz on a sealed box ≈ 15–30 m line-of-sight — this is a "standing next to the camera" feature, not a village-wide file server. Use it at the truck or at the tree.

**Implementation slices:**
- C6 (Zephyr): `dl_session` service — BLE characteristic pair, AP bring-up/teardown, watchdog enforce (hard cap regardless of host state).
- SoC (Yocto): `wapiti-local-dl` systemd socket service — TLS listener on 192.168.77.1:443 (fixed service subnet, never routes to LTE), manifest + range GET handlers, eMMC/SD file access through the normal media store, audit + telemetry emission.
- App: BLE-proximity entry point, progress UI, photo picker filter, post-download gallery import.
- Server: ingest `local_download` audit events + telemetry field; no other cloud dependency (feature works fully offline).

- **Encryption interplay:** the AP serves media as ciphertext only; the paired phone decrypts locally with the cached per-device media key (§15.1) — zero-coverage decrypt works because the phone holds the key, not because the camera exposes one.

**Verification:** `LDL-01..12` in `test-plan.md` §11bis; security review item in §15 checklist; battery accounting covered by PWR telemetry tests.

---

## 6. Domain model & first-class objects

MongoDB, collection per class, ObjectId refs (house convention).

```mermaid
erDiagram
    USERS ||--o{ CREDENTIALS : "has passkeys"
    USERS ||--o{ CAMERAS : "owns"
    USERS ||--o{ SITES : "owns"
    SITES ||--o{ CAMERAS : "groups"
    CAMERAS ||--o{ PHOTOS : "captures"
    CAMERAS ||--o{ HEARTBEATS : "checks in"
    CAMERAS ||--o{ DETECTIONS : "produces"
    CAMERAS ||--o{ ALERT_RULES : "configured by"
    ALERT_RULES ||--o{ ALERTS : "fires"
    CAMERAS ||--o{ SHARE_LINKS : "shared via"
    CAMERAS ||--o{ PAIR_TOKENS : "claimed via"
```

### 6.1 Collections

**`users`** — `{_id, handle, email, role: admin|user, tier: free|pro|outfitter, push_tokens[], created_at, last_seen_at}`

**`credentials`** — WebAuthn; verbatim wificam/lugtrax shape (`credential_id, public_key, sign_count, aaguid, nickname, transports, timestamps`).

**`sites`** (the property/hunting land — lugtrax "item" analog)
| Field | Type | Notes |
|---|---|---|
| `_id, owner_id` | ObjectId | |
| `name` | string | "North 40" |
| `location` | `{lat, lon}` | Weather lookup anchor (battery forecast, forecast derates) |
| `notes` | string | Markdown |

**`cameras`** (the device)
| Field | Type | Notes |
|---|---|---|
| `_id, owner_id, site_id?` | ObjectId | |
| `device_id` | string | Factory-provisioned, QR-printed, immutable |
| `claimed_at` | datetime? | Null = stock |
| `fw_version / hw_version` | string | Every report |
| `power` | object | `{source: aa_tray|smart_pack|arctic_pack, chemistry, gauge_pct, voltage_mv, temp_c, forecast_days, pack_id}` |
| `signal` | object | `{rsrp_dbm, rsrq_dbm, band, carrier, latency_ms_p50, last_towers[]}` |
| `mode` | enum | `normal | theft | suspended` |
| `status` | enum | `healthy | at_risk | silent` — **the wedge state** |
| `capture_config` | object | `{photo_res: 4k|2.5k, video: off|1080p10, simultaneous: bool, ir: no_glow|low_glow|auto, interval_s, quiet_hours, instant_send: bool}` |
| `last_seen_at / last_photo_at` | datetime | |
| `created_at` | datetime | |

**`photos`** — `{_id, camera_id, owner_id, site_id, kind: photo|video|live_burst, res, bytes, storage_key, thumb_key, ai_class, ai_confidence, transmitted: bool, capture_at, created_at}` (indexed `{owner_id, capture_at}`, `{camera_id, capture_at}`)

**`detections`** — `{_id, camera_id, owner_id, class: deer|turkey|human|vehicle|empty|other, confidence, photo_id, on_device_decided: bool, billed: bool, capture_at}` — `empty` rows keep the audit trail without billing.

**`heartbeats`** — `{_id, camera_id, at, battery_snapshot, signal_snapshot, expected_next_at, transport}` — TTL-indexed rolling window; the engine evaluates `status`.

**`pair_tokens`** — `{token: PRT-xxxx-xxxx, device_id, issued_by, expires_at (15 min, TTL), consumed_at}`.

**`alert_rules` / `alerts`** — rules: `{camera_id, class: silent|battery_low|move_alert|human|vehicle|delivery_slow, min_confidence, quiet_hours, channels[]}`; alerts: `{rule_id, camera_id, payload, notified, created_at}` — SSE feed `/api/alerts/stream`.

**`share_links`** — `{token, camera_id, scope: live|recent_24h, expires_at (≤ 7 d), revoked_at, created_by}` — public staff-viewer page, rate-limited, audited (lugtrax partner-mode pattern).

**`subscriptions`, `ota_campaigns`, `audit_log`** — lugtrax §5.10 shapes verbatim.

---

## 7. Tiers, RBAC & sharing

### 7.1 Plans (published, no contracts; connectivity bundled)

| Tier | Cameras | Check-in floor | Photos/mo | History | Members | Price |
|---|---|---|---|---|---|---|
| **Free** | 1 | 1/day | 50 | 7 days | 1 | **$0 forever** |
| **Pro** | 10 | 1/hour | Unlimited | 1 year | 5 | **$7.99/mo** ($79/yr) — **all camera features included** |
| **Outfitter** | 50 | 1/hour | Unlimited | 2 years | Unlimited + API + MCP | **$24.99/mo** |

- **No add-on ladder:** Live View, on-demand video, HD requests, species filters — all in Pro (anti-Tactacam posture; `competitive-analysis.md` §4.3).
- **Pause anytime** in-app (offseason = $0); **opt-in capped overage only**; lapsed → Free tier (never a brick).
- Hardware: **$149** camera; **$199** solar bundle; packs $49/$89.

### 7.2 RBAC

| Role | Rights |
|---|---|
| **admin** | Users, tiers, OTA campaigns, settings |
| **owner** | Full camera control (config, theft arm, sharing, delete) |
| **member** | Live view + history per site; cannot arm/config |
| **link** | Anonymous share-link: scoped, expiring, read-only |

---

## 8. Data & control flows

### 8.1 Heartbeat + dead-camera detection (the wedge)

```mermaid
sequenceDiagram
    autonumber
    participant C as Camera
    participant L as Laravel API
    participant H as Heartbeat worker
    participant U as User app

    rect rgb(215, 226, 213)
        C->>L: report — photo / telemetry / check-in
        L->>H: append heartbeats — expected_next_at = now + interval
        H->>H: missed expected_next_at + grace → retry cadence
    end
    rect rgb(230, 224, 205)
        H->>U: at_risk — Camera 3 missed its check-in — battery 61%, last photo 11:04
    end
    rect rgb(232, 214, 211)
        H->>U: silent — Camera 3 is SILENT, plan a visit
    end
    Note over C,U: server never wakes the camera —<br/>reconnect backfills status transition
```

*Color key: green = ingest path · amber = at-risk push · red = silent-death push.*

### 8.2 Capture → classify → deliver

```mermaid
flowchart TD
    W["PIR / radar / timer wake"] --> B["SoC boot ≤1.5 s"]
    B --> P{"Edge classify<br/>PIR + radar + AI v0"}
    P -->|"empty"| S["Store on camera, count, no upload<br/>does not bill"]
    P -->|"animal / human / vehicle"| C["Capture 2.5K / 4K + optional 1080p10"]
    C --> U["LTE upload, instant-send"]
    U -->|"ok"| D["Delivered; latency recorded"]
    U -->|"fail"| Q["Store-and-forward ring buffer<br/>retry with backoff"]
    Q -->|"coverage"| D
    D --> A["Alerts: human / vehicle push<br/>species digest"]

    classDef wake fill:#1b4332,stroke:#40916c,color:#b7e4c7
    classDef decide fill:#4a2c0f,stroke:#d98e32,color:#ffd9a0
    classDef local fill:#5c470a,stroke:#d4a017,color:#ffe066
    classDef net fill:#0f2a43,stroke:#4d94d0,color:#a8d5ff
    classDef retry fill:#4a1414,stroke:#e57373,color:#ffc9c9
    classDef alert fill:#3b1f4e,stroke:#9b59b6,color:#e0c3fc

    class W,B wake
    class P decide
    class S local
    class C,U net
    class Q retry
    class D,A alert
```

### 8.3 Pairing (lugtrax §7.2 pattern, BLE via C6)

Scan QR → app scans BLE → `PRT-xxxx-xxxx` pair token (15 min) → camera posts `/device/v1/pair` with factory secret → `device_token` issued → Wi-Fi credentials optionally handed to C6 for live-aim/preview at setup.

### 8.4 Theft mode + anti-theft GPS

Move-alert (accel) or human/vehicle detection arms theft mode (auto-rule or manual/MCP): burst telemetry + photos at 3–10 s cadence, GPS breadcrumbs, reserve-battery pings every 6 h after main power loss/removal (½-mile trigger), SMS fallback for urgent commands, audit-logged arm/disarm. Media captured before the theft stays unreadable to whoever takes it — per-device encryption at rest with theft-revocable keys (§15.1).

### 8.5 OTA

Signed A/B firmware (ECDSA P-256), staged `canary → 10% → 100%`, boot-failure rollback counters; `rollback_of` audit linkage. Camera SoC (Linux rootfs) and C6 firmware are separate artifacts.

### 8.6 Cellular link discipline — retries, idempotency, fleet protection

Method note distilled from `interview-questions/interview_cellular_retries_qa.md` (cellular retry-engineering briefing): software must behave correctly when the radio lies — tower handoffs eat acks, coverage holes are normal, and a naive retry loop that works in the lab hammers the backend in the field and burns the pack.

**Per-class retry policy** (configurable, never a fixed count):

| Message class | Attempts | Backoff | Deadline / budget |
|---|---|---|---|
| Photo/telemetry upload (trigger-driven) | 6 | `min(cap 120 s, base 2 s · 2^n)` + **full jitter** (`random(0, window)`) | then store-and-forward (§8.2) |
| Heartbeat check-in | 3 | base 30 s, cap 10 min, full jitter | miss → HB engine handles (§8.1) |
| OTA pull | 5 | base 60 s, cap 1 h | battery-gated: abort below 20% (BMS rule) |
| SMS fallback | 1 | — | never retried (cost); next report carries state |

- **Transient vs permanent:** retry 5xx, timeouts, connection resets; **never retry 4xx** (400/401/422 will never succeed — retrying burns battery and poisons metrics).
- **Idempotency:** every device POST carries a stable `Idempotency-Key` (UUID per report / photo batch, persisted before first TX). At-least-once delivery over the radio is the only realistic default; exactly-once *effects* come from ingest-side dedup (unique index → replay original response). A lost ack in a tower handoff must never produce a duplicate photo row or double-counted heartbeat.
- **Outbox durability:** the §8.2 ring buffer is an outbox — rows written to eMMC before TX, marked synced only on server ack, drained in order after reboot. Work never lives only in RAM; the OS will not be alive when the network returns.
- **Modem circuit breaker:** N consecutive transport failures → modem cooldown (PSM until next scheduled wake). The battery is the breaker: no self-imposed TX storms.
- **Signal gating:** read RSRP/SINR before deciding *now vs defer*. Collapsing signal → defer to next wake, never accelerate. Retrying while the modem is between RRC states forces an expensive ACTIVE transition — "should I even send this now" is a modem-state question.
- **Fleet retry budget:** ingest caps fleet-wide retries (~10% of request volume); over budget → `429` + jittered `Retry-After`, which clients honor. A degraded backend stops being amplified by the fleet.
- **Staggered reconnect:** after a long outage, reconnect windows are spread over several minutes, seeded by `device_id` (server directive piggybacked on reports). Devices that all lost service at 02:00 must not all return at 02:01.
- **Instrumentation:** DNS failures counted separately from TCP failures (resolver faults masquerade as network down); correlation IDs + client/server timestamps on every attempt; modem state, RSRP and RTT captured **at failure time**, not just in aggregates.

---

## 9. Server stack

| Layer | Tech | Notes |
|---|---|---|
| Reverse proxy | nginx (`nginx:v5`) | `trailcam-server` case, host port **4440** |
| App | Laravel 12 (PHP 8.5-fpm) | House stack |
| DB | MongoDB (shared `database-server`, db `wapiti`) | 13 collections |
| Cache/queue | Redis (predis) | SSE fanout, queues, rate limits |
| AuthN | `web-auth/webauthn-lib` | Contract reused verbatim |
| MCP | Official Laravel MCP package at `/mcp` | §11 |
| Push | VAPID web push; FCM/APNs via Expo | |
| SMS | Provider HTTP API (theft urgent path) | |
| Object storage | Local `objects/` v1 → S3-compatible later | Photos, thumbs |
| Frontend | React + Bootstrap 5 PWA | House style |

nginx site `default.wapiti.cam`: `/api/`, `/auth/`, `/device/`, `/admin/api/`, `/mcp` → Laravel :8003; `client_max_body_size 25M` (4K photos + video bursts); block `.env`, `storage/`, `vendor/`.

---

## 10. Authentication (WebAuthn)

- The proven 10-endpoint contract from wificam/lugtrax (`register/begin|complete`, `add-passkey/*`, `login/begin|complete`, `logout`, `status`, `DELETE /auth/passkeys/{id}`, `POST /auth/recovery`).
- RP_ID per environment (`wapiti.cam` prod, `localhost` dev); never from Host header.
- Admin bootstrap: `php artisan wapiti:bootstrap-admin` (one-time enrollment URL).
- **Device auth separate:** per-camera `device_token` (32-byte random, rotate-able, hashed) as Bearer on `/device/v1/*`; SMS ingest authenticated by SMSC origin checks.

---

## 11. AI & MCP layer — the differentiator

### 11.1 MCP server (S3)

| Tool | Input | Effect |
|---|---|---|
| `list_cameras` | site_id? | Cameras + status (`healthy/at_risk/silent`) + battery + signal |
| `get_camera` | camera_id | Config, power forecast, last photos |
| `get_photos` | camera_id, from, to, class? | Filtered detections/photos |
| `get_status` | camera_id | Heartbeat state, latency, forecast, signal diagnostics |
| `set_capture_config` | camera_id, config | Tier-checked config update |
| `arm_theft` / `disarm_theft` | camera_id | High-risk: `theft:write` scope, audited, rate-limited |
| `get_alerts` | camera_id?, since | Recent alerts |
| `set_ir_mode` | camera_id, no_glow\|low_glow | Remote stealth switch |

Non-negotiables (lugtrax §10.1.1 hardened list): session cookies rejected at `/mcp`; revoked keys fail clean JSON-RPC; no scope minting; no LLM recursion; every call audited with secrets redacted; row caps enforced.

### 11.2 Edge + backend intelligence

- **Edge v0 (S3):** PIR + radar fusion rules + simple frame heuristics (empty-frame discard, day/night exposure sanity) — no billing on empties.
- **Edge v1 (S4):** lightweight NN classifier (deer/turkey/human/vehicle/empty) on SoC NPU — feasibility spike first (`competitive-analysis.md` §7 #7).
- **Backend (S4):** per-site species/activity digests; battery-forecast model (usage × weather); delivery-latency baselines per camera.

---

## 12. Sprint plan (S1 → S5)

2-week sprints, ~10 weeks + buffer; certification (§13) parallel 6–9 months, submissions start S1/S2.

```mermaid
gantt
    title wapiti trail camera — 5-sprint plan + certification track
    dateFormat YYYY-MM-DD
    axisFormat %m-%d

    section S1 Foundations
    Server scaffold + WebAuthn       :s1a, 2026-10-06, 6d
    Mongo schema + migrations        :s1b, 2026-10-06, 5d
    Ingest API + camera simulator    :s1c, after s1b, 6d
    EVK orders + cert kickoff        :s1d, 2026-10-06, 8d

    section S2 Device
    SoC bring-up + capture pipeline  :s2a, 2026-10-20, 8d
    PIR/radar wake + power budget    :s2b, after s2a, 6d
    LTE upload + pairing BLE/WiFi   :s2c, after s2b, 6d
    Battery telemetry + ring buffer  :s2d, after s2b, 4d

    section S3 Value features
    Heartbeat + dead-camera engine   :s3a, 2026-11-03, 6d
    Signal + battery forecast        :s3b, after s3a, 5d
    Edge v0 discard + alerts         :s3c, after s3a, 6d
    MCP server + PWA                 :s3d, 2026-11-03, 7d
    OTA pipeline                     :s3e, after s2d, 5d

    section S4 Apps + commerce
    Expo apps + push                 :s4a, 2026-11-17, 8d
    Subscriptions + sharing          :s4b, after s4a, 5d
    Edge v1 classifier spike→impl   :s4c, after s3c, 8d
    Solar rig + accessory SKUs       :s4d, after s4b, 5d

    section S5 Hardening + launch
    PQT incl -40C mitten-swap gate   :s5a, 2026-12-01, 10d
    Cert closures FCC/PTCRB/RED     :s5b, after s1d, 20d
    Store + quotas + docs            :s5c, 2026-12-01, 6d
    30-day field soak + E2E green    :s5d, after s5a, 6d
```

| Sprint | Must satisfy test IDs |
|---|---|
| S1 — Foundations | `AUTH-01..18`, `SRV/SVC/PHP/MIG/BLD`, `SIM-01..06`, `ING-01..10` |
| S2 — Device | `CAM-DEV-01..14`, `YOCT-01..03`, `PIR-01..04`, `PWR-01..05`, `NET-01..05`, `PR-01..08` |
| S3 — Value | `HB-01..08`, `YOCT-04..06`, `PIR-05..08`, `PWR-06..10`, `NET-06..14`, `IMG-01..08`, `ALR-01..10`, `MCP-01..20`, `OTA-01..08`, `BROWSER-01..04`, `ENC-01..08` |
| S4 — Apps + commerce | `SUB-01..08`, `SHR-01..06`, `ADM-01..08`, E2E chains |
| S5 — Hardening | `COLD-01..08`, `PQT-01..14`, `GAP-01..20`, `BAT-01..06`, `NET-15..18`, full E2E, security review |

### Work items

**S1 — Foundations (WI-101 → WI-107)** `[ ]`
- **WI-101** Laravel + WebAuthn scaffold (reuse contract; Pest `AUTH-01..18`).
- **WI-102** Mongo schema + migrations (13 collections, indexes; `MIG-01..05`).
- **WI-103** nginx site + service group (:4440; builder/test/sim one-shots; `SVC-01..04`).
- **WI-104** Device ingest API (`/device/v1/*`): bearer auth, photo multipart, config piggyback, rate limits (`ING-01..10`).
- **WI-105** Camera simulator: N cameras, cadence/offline/latency/photo-inject profiles (`SIM-01..06`).
- **WI-106** Procurement + cert kickoff: SoC/sensor/modem EVKs, cold-chamber slot, PTCRB lab, Bluetooth SIG QDL, UN 38.3 booking.
- **WI-107** IP gate: external **FTO search on the reserve-battery GPS** (§13.1) commissioned, 1-day internal prior-art skim of §5.4 AP download, §4.11 wording discipline (capability, not competitor implementation); findings due before the S2-exit decision gate.

**S2 — Device (WI-201 → WI-206)** `[ ]`
- **WI-201** SSC377Q bring-up: Yocto BSP layer (`meta-sigmastar` wrapping the vendor kernel/u-boot/ISP blobs), sensor driver, ISP tuning baseline; first 4K still on bench; `YOCT-01..03` green.
- **WI-202** Capture pipeline: photo+video simultaneous, IR array switching, LCD aim preview, microSD.
- **WI-203** Wake chain: PIR + radar fusion, ≤ 1.5 s wake-to-capture, µA sleep budget (power analyzer evidence).
- **WI-204** LTE: EG915U bring-up, multi-IMSI eSIM attach, instant-send upload, PSM between events (`NET-01..10`).
- **WI-205** C6 co-processor: BLE pairing, Wi-Fi live aim, AP-scan diagnostics, watchdog.
- **WI-206** Power telemetry: fuel gauge, pack-ID detect, temp sensors, ring buffer + store-and-forward.

**S3 — Value features (WI-301 → WI-308)** `[ ]`
- **WI-301** Heartbeat + dead-camera engine: expected-next tracking, grace/retry, status transitions, push+email (`HB-01..08`) — **the wedge, firmware critical path**.
- **WI-302** Battery forecast service (weather-adjusted) + signal diagnostics page (`PWR-09..10`, `IMG-07..08`).
- **WI-303** Edge v0 discard + alert rules + SSE (`PIR-05..08`, `ALR-01..10`).
- **WI-304** MCP server (8 tools, auth, audit; `MCP-01..20`).
- **WI-305** PWA (gallery, live status grid, settings, WebAuthn; `BROWSER-01..04`).
- **WI-306** OTA pipeline (signed A/B for SoC rootfs + C6 fw; `OTA-01..08`).
- **WI-307** Theft mode + reserve-battery GPS + SMS fallback.
- **WI-308** Encrypted-at-rest media: per-device KEK (C6 eFuse wrap), fscrypt media store (eMMC + microSD), cloud escrow with WebAuthn-gated release, phone keystore cache, theft-revocation hook (§15.1; `ENC-01..08`).

**S4 — Apps + commerce (WI-401 → WI-405)** `[ ]`
- **WI-401** Expo apps + push (BLE proximity + setup flow; UWB-free parity) + **local-download UI (§5.4, `LDL-01..12`)**.
- **WI-402** Subscriptions + tier enforcement + pause/caps (`SUB-01..08`).
- **WI-403** Share links + member RBAC (`SHR-01..06`).
- **WI-404** Edge v1 classifier (feasibility → train → deploy; `IMG-05..06`).
- **WI-405** Solar rig + accessory SKUs + packaging (compatibility pledge printed).

**S5 — Hardening + launch (WI-501 → WI-506)** `[ ]`
- **WI-501** PQT at lab: `PQT-01..14` **including COLD-05 (gloved swap < 20 s @ −40 °C) and COLD-06 (500-cycle latch)**.
- **WI-502** Certification closures (§13).
- **WI-503** Store, quotas, GDPR export/erase, docs.
- **WI-504** 30-day field soak, 20 cameras mixed sites; burn-down vs forecast ±15%; carries the **BAT-01..06 battery trials** (incl. heavy-usage profile) and files measured Ah/day into the test-plan §21.6 results log.
- **WI-505** Security review (threat model, ETSI EN 303 645 / UK PSTI / EU CRA checklist, Trivy).
- **WI-506** Launch checklist: full `E2E-01..16` + `GAP-01..20` green on staging.

---

## 13. Certifications & compliance

Strategy identical to lugtrax §12: buy pre-certified silicon (EG915U module grants; eSIM), certify the final product for the remainder. Budget $200–400k, 6–9 months, parallel from S1. Owner named per row before S2 exits.

| Area | Items | When |
|---|---|---|
| **Radio/telecom** | FCC Part 15B/15C (TCB), ISED Canada, **PTCRB + carrier acceptance** (Verizon Open Dev / AT&T IoT / T-Mobile), CE RED (Notified Body), UKCA, GCF (optional), Bluetooth SIG QDL | S1 kickoff; filings S2–S4 |
| **Safety/EMC** | IEC/EN 62368-1 + CISPR 32/35 (bundled w/ RED), UL 62368-1 for US retail | S3–S4 |
| **Battery/transport** | UN 38.3 (device-level + packs), IEC 62133-2 cells, IATA PI 967 program, UL 2054 for rechargeable packs | S1 cell sourcing → S5 |
| **Environmental** | RoHS, REACH, EU Battery Regulation 2023/1542 (removability — our design already complies), WEEE, Prop 65 | S4–S5 |
| **Cyber/data** | ETSI EN 303 645, UK PSTI, EU CRA readiness, GDPR (EU SKU) | S4–S5 |
| **Open-source / IP** | SPDX manifest per build (`YOCTO-06`), license texts + corresponding-source offer shipped with OTA artifacts (GPL-2.0 kernel/busybox, Apache-2.0 Zephyr, MIT Yocto layers); **FTO gate per §13.1** | FTO finding S1; license compliance S2 → S5 |
| **Ingress/mech** | IP67 (IEC 60529), −40 °C operation claims backed by lab reports (PQT/COLD evidence files) | S5 |

### 13.1 Intellectual property — findings (Oct 5, 2026) & FTO gate

Engineering-level IP screen of the wapiti design and docs; **not legal advice** — the final call sits with IP counsel.

**Patents.**
- **Primary exposure — reserve-battery anti-theft GPS** (§2 matrix row 4, BOM "Reserve battery", theft mode, WI-307): the design deliberately mirrors REVEAL Ultra's marketed Active GPS (½-mile trigger, 6 h pings after main-power loss on an internal reserve). The *capability* has deep prior art in asset tracking (our own lugtrax program proves it), but patents cover claim scope, not concepts. Public record shows Tactacam does file (e.g., a "Trail Camera with Modular Fresnel Lenses" assignment), and NPEs litigate this category (SurvMatic LLC v. Spypoint, wireless camera surveillance). **This is the one item needing a formal freedom-to-operate search before launch.**
- **Low risk:** BLE-gated AP download (§5.4) — plain AP mode + WPA2 + HTTPS + BLE provisioning, ubiquitous prior art (phone hotspots, Wi-Fi file transfer, card readers); PIR + mmWave fusion, mitten-swap drawer, strap slots, ¼-20 boss — sensor/mechanical commons.
- **Trademark hygiene:** REVEAL / FlexPack™ / Spypoint / Moultrie names stay inside research docs (nominative fair use); never in product names, app strings, or marketing.

**Copyright.**
- All generated artifacts (docs, `gen_*.py`, STL/OBJ, PCB, renders) are our own work; KiCad/Blender/Python tool outputs carry no back-license.
- Research docs quote short verbatim complaint excerpts with named sources and a method note (`competitive-analysis.md` §8) — ordinary internal research quotation. **Rules:** (1) those quotes and the Tactacam research report must never be reused in marketing, site, or app copy — paraphrase there; (2) never reuse competitor photos or spec-sheet tables. Root README verified clean (doc links only).

**Open-source (the real compliance workstream).**
- Shipped firmware binaries trigger GPL-2.0 obligations (Linux kernel, busybox) plus Apache-2.0/MIT attribution (Zephyr, Yocto layers): license texts + corresponding-source offer must ship with OTA artifacts. Tracked per build by **YOCTO-06** (SPDX manifest); row added to the §13 table.
- Cloud stack (Laravel MIT, Expo MIT, self-hosted MongoDB) poses no copyleft infection. Bluetooth SIG QDL already in the table (required to market "Bluetooth").

**Gate — the FTO search comes first.**
- The external **freedom-to-operate search on the reserve-battery GPS implementation is the blocking IP item: commissioned in S1 (WI-107), findings in hand before the S2-exit decision gate** (hardware freeze). Design-around room exists — reserve cell on the RTC rail, alternate trigger/ping architecture — so match / design-around / license is decided with counsel before tooling commits.
- **Wording discipline:** `competitive-analysis.md` §4.11 currently reads "Match REVEAL Ultra's … Active GPS" — reword to the user-visible capability ("anti-theft location that survives power loss") with our own implementation details; internal docs naming a competitor's implementation as the copy target feed a willfulness narrative.
- A 1-day internal prior-art skim of §5.4 AP download runs in parallel (expected clear).

---

## 14. API surface

**Auth (WebAuthn)** — `/auth/register/begin|complete`, `/auth/add-passkey/*`, `/auth/login/begin|complete`, `/auth/logout`, `/auth/status`, `/auth/recovery`, `DELETE /auth/passkeys/{id}`.

**User app** — `/api/sites`, `/api/cameras` (CRUD, claim, config `PATCH`), `/api/cameras/{id}/photos` (paginated, class filter), `/api/cameras/{id}/status` (heartbeat/forecast/signal), `/api/cameras/{id}/theft-mode`, `/api/cameras/{id}/share-links`, `/api/alerts` + `/api/alerts/stream` (SSE), `/api/subscription/*`, `/admin/api/*`.

**Device** — `/device/v1/pair`, `/device/v1/reports` (telemetry + heartbeat), `/device/v1/photos` (multipart, batch manifests), `/device/v1/events` (move alert, door open, tamper), `/device/v1/ota/ack`. Config/commands piggyback on responses. All device POSTs carry an `Idempotency-Key` header; ingest dedups on a unique index and replays the original response (§8.6). Fleet retry budget enforced with `429` + jittered `Retry-After`.

---

## 15. Security posture

- WebAuthn-only human auth; HttpOnly/Secure/Strict session cookies; RP_ID fixed per env.
- Device bearer tokens hashed at rest, rotate-able, revocable on unbind; factory secrets per-unit at CM provisioning.
- Photos: signed, expiring object URLs; owner-scoped queries everywhere (`CAMERA-16`-style isolation tests; `GAP-16` analog).
- `/mcp`: scoped API keys (`read`/`write`/`theft:write`), session-cookie rejection, full audit incl. reads, secrets redaction, row caps.
- OTA: signed artifacts, staged rollout, rollback; anti-downgrade version policy.
- Anti-stalking posture page + support reporting path (competitive-analysis §5.7 analog).
- Transport TLS everywhere; no LAN services on the camera; C6/SoC split keeps BLE surface minimal (pairing only).
- Media encrypted at rest (§15.1): a stolen camera or microSD yields hardware, not photos.

### 15.1 Encrypted-at-rest media — stolen camera ≠ stolen photos (§2 row 24)

Threat: the camera or microSD is stolen — the most common way sensitive media (property locations, game movement, outbuildings) walks off. Every competitor card is plain files readable in any $12 reader.

- **Per-file CEK:** every photo/video is encrypted with a random AES-256-GCM content key; headers/EXIF never stored in clear.
- **Per-device KEK:** minted at CM provisioning; the device copy is wrapped under **C6 eFuse key material** (read-protected HMAC/flash-encryption peripheral), the escrow copy under the **owner account's KMS key** (released only to WebAuthn-authenticated sessions of the bound account).
- **Storage:** eMMC media store + microSD volumes use `fscrypt` with the device KEK. A card moved to another camera is refused, not read (`ENC-03`).
- **Paired phone:** caches the KEK in the OS hardware keystore at pairing → offline decrypt for §5.4 local download and gallery import even with zero coverage; a non-paired phone on the same AP session sees only ciphertext.
- **Theft revocation:** arming theft mode (§8.4) revokes escrowed-key release; a flagged serial's re-claim cannot obtain keys (`ENC-06`) — a factory-reset stolen camera decrypts nothing it captured.
- **Cloud copies:** uploaded ciphertext is decrypted at the ingest boundary into a storage-side-encrypted object store — cloud features (§11 AI, share links, web gallery) keep working. **Deliberate non-goal: full end-to-end encryption** would kill the cloud-AI differentiator; we say so on the security page rather than pretend.
- **Honest limits (published):** a lab-grade attacker can extract eFuse key material; in-RAM preview buffers exist during capture; cloud-side media is readable by the operator (trust boundary documented, not hidden).
- **Cost:** no BOM change; crypto offload via the SoC crypto engine / Linux crypto API; budget < 1% of a capture burst (`ENC-08` verifies).

**Verification:** `ENC-01..08` in `test-plan.md` §11ter.

---

## 16. Testing plan (summary)

Full catalog in `test-plan.md` (**0 passed / 301 pending** at planning time), same methodology as lugtrax: Python `requests`+pytest primary suite with prefixed IDs, Pest, Playwright, infra regression runner, device suites over SSH, faraday/cold-chamber lab suites, coverage matrix, regression log with Mermaid.

| Suite | Prefix | Covers |
|---|---|---|
| Auth / pairing / ingest / simulator | AUTH, PR, ING, SIM | Cloud foundations |
| Device / platform / PIR / power / cold / net | CAM, CAM-DEV, YOCT, IMG, PIR, PWR, COLD, NET | Hardware + platform behavior incl. −40 °C gates |
| Heartbeat / alerts / photos / MCP / OTA | HB, ALR, MCP, OTA | The wedge + value features |
| Media encryption | ENC | Stolen-camera data protection (§15.1) |
| Subscriptions / sharing / admin | SUB, SHR, ADM | Commerce + RBAC |
| E2E chains / gap coverage | E2E, GAP | Product loops + review gaps |
| Infra | SRV, SVC, PHP, MIG, BLD | House conventions |
| Product qualification | PQT | Lab evidence for cert + marketing claims |

---

## 17. Deployment & operations

- Single-host Docker (house pattern) → managed k8s later; object storage abstracted for S3 move.
- Observability: ingest latency, upload success %, per-camera delivery p50/p95, heartbeat SLA burn-down — **the reliability metrics are the product**; they get dashboards first.
- Support ops: diagnostics auto-attach, advance-replacement RMA flow, loaner inventory for Outfitter tier.
- Seasonality: plan-pause campaigns in off-season; capacity sized for fall ramp (Oct–Dec peak).

---

## 18. Directory layout

```
trailcam/
  docs/                     # this plan, test-plan, research, competitive-analysis
  device/
    yocto/                  # meta-wapiti (product services) + meta-sigmastar BSP layer
    yocto/build.sh          # one-shot containerized bitbake → wapiti-image.swu
    zephyr-c6/              # ESP32-C6 co-processor firmware
    ai/                     # edge classifier (v0 rules, v1 NN)
  sim/                      # Python camera-fleet simulator
  server/                   # Laravel app (routes, models, jobs, MCP)
  pwa/                      # React + Bootstrap 5 PWA
  mobile/                   # Expo RN apps (S4)
  hardware/                 # schematics, PCB, chassis CAD + STLs (generated)
  tests/
    test.py                 # primary pytest suite (prefixed IDs)
    regression.py           # infra runner → tests/reports/test-regression.md
    reports/pqt/            # lab evidence bundles (PQT/COLD)
```

---

## 19. Risks & open questions

| # | Risk | Mitigation |
|---|---|---|
| 1 | SigmaStar/Ingenic supply or NRE friction | Dual-footprint carrier design (T41 second source); EVK order day 1 |
| 2 | LTE Cat-1bis power vs LTE-M in deep rural | PSM discipline + burst uploads; LTE-M/NB-IoT variant evaluated S6 (EU deep-rural SKU) |
| 3 | Edge-ML feasibility on SoC NPU | Spike in S3 before committing S4 (GAP-gated); radar+PIR rules carry v0 value regardless |
| 4 | −40 °C latch/gasket long-term wear | 500-cycle cold-chamber gate at design freeze; field-soak units in northern sites |
| 5 | Smart-pack BMS + fuel-gauge certification adds time | Pack as separate SKU with own UN 38.3/62133 track, parallel to camera certs |
| 6 | Free tier abuse (photo storage) | 50 photos/mo cap + 7-day retention + rate limits; storage costed at ≤ $0.25/free-cam/mo |
| 7 | Weather API dependency for forecasts | Cache + degrade gracefully (forecast shows "weather unavailable" rather than lying) |
| 8 | Carrier acceptance timelines | PTCRB/carrier submissions opened S1 (lugtrax lesson), not S5 |
| 9 | SigmaStar/Ingenic BSPs ship as Buildroot SDKs, not Yocto layers | `meta-sigmastar` BSP layer wraps the vendor kernel/u-boot/ISP blobs; S1 spike as WI-201 precondition; S2-exit decision gate may fall back to the vendor rootfs if bring-up stalls |
| 10 | Patent exposure — reserve-battery anti-theft GPS deliberately mirrors Ultra's marketed Active GPS; Tactacam files patents and NPEs are active in this category | **FTO search commissioned S1 (WI-107), findings before S2 exit — blocking**; match / design-around / license decided with counsel; §4.11 wording discipline (capability, not implementation) |
| 11 | Media-key recovery misdesign = permanent photo loss (escrow too weak → thief decrypts; too strict → owner locked out) | Escrow under account KMS + WebAuthn recovery ceremony; `ENC-05..06` cover release/revocation; recovery drill before S4 exit |
| 12 | Fleet retry storm after backend outage/deploy wakes every camera at once and amplifies the degradation | Per-class backoff + full jitter, ingest retry budget (429 + Retry-After), modem circuit breaker, staggered reconnect windows (§8.6); storm soak-tested (`NET-17..18`) |

---

*Sources: `tactacam-reveal-hunt-cameras-product-research-report.md` (parity + pricing), `competitive-analysis.md` Rev B (pains → solutions; §4.2 power, §4.13 chassis), luggage-tracker project-plan (program shape, MCP, certs), wificam project-plan (camera-hardware evidence: ESP32 class ceiling, house stack).*

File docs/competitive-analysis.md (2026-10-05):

# Competitive analysis — REVEAL 4.0 · Spypoint Flex · Moultrie Edge · Stealth Cam · and the product that beats them

**Date:** October 4, 2026 · **Scope:** Identify the parity baseline for a new cellular trail camera, then the user pain points that give us an edge. Built on `tactacam-reveal-hunt-cameras-product-research-report.md` (lineup/specs/pricing) plus a complaint sweep across Reddit (r/trailcam, r/TactacamRevealFans, r/Hunting), Trustpilot, PissedConsumer, Facebook gear groups, and 2026 press tests (Outdoor Life, GearJunkie, Popular Mechanics, TechGearLab, Trailcampro). · **Rev B (Oct 4, 2026):** adds the hard **−40 °C power requirement** and the **glove-operable battery-swap chassis design** (§2, §4.2, §4.13). · **Rev B addendum:** adds **§4bis — GPS locate + local AP download: where they win and where they don't** (tree-strap chassis adopted into §5.3; AP download = plan §5.4, tests LDL-01..12).

- [1. Executive summary](#1-executive-summary)
- [2. Parity baseline — what we must match](#2-parity-baseline--what-we-must-match)
- [3. The pain-point ledger — what users complain about](#3-the-pain-point-ledger--what-users-complain-about)
- [4. Solutions — how we fill each gap](#4-solutions--how-we-fill-each-gap)
- [4bis. GPS locate + local AP download — where they win and where they don't](#4bis-gps-locate--local-ap-download--where-they-win-and-where-they-dont)
- [5. Where we will not win (and should not try)](#5-where-we-will-not-win-and-should-not-try)
- [6. Positioning and pricing posture](#6-positioning-and-pricing-posture)
- [7. Action items](#7-action-items)
- [8. Sources](#8-sources)

---

## 1. Executive summary

The 2026 cellular trail camera market is mature on hardware and immature on **trust**. Every major brand — Tactacam, Spypoint, Moultrie, Stealth Cam — can put 4K photos on your phone. What they cannot do reliably is: **deliver the photo when it matters, keep the camera alive between visits, and keep the service honest**. The complaint sweep is remarkably consistent across brands and years:

- **"Silent death" / missed capture is the #1 fear.** Cameras check out mid-season at full battery (Moultrie: "stopped connecting a month ago with 78 percent battery"); batteries die early in instant-send mode or cold; photos transmit late (Spypoint: hours later, after the buck walked on).
- **Subscriptions generate the deepest anger** — surprise charges (Spypoint "keep charging my bank account"), photo pools running dry mid-season, paywalls on the camera's headline features (Tactacam Live View), and churn-renewal traps.
- **Support and warranty are the reputation killers** — Trustpilot 1.3–2.1 across the majors, $50 return fees, week-long diagnosis loops, 1-year warranties.
- **False triggers eat plan photos**; time-lapse and minute-by-minute modes burn batteries and plans; cold-weather performance is a known universal weakness.
- **And when the camera is stolen, the data goes with it.** Every competitor card is plain files readable in a $12 reader; the category's own theft guides (Reolink, NatureSpy, WOSports) offer locks, poles and mounting height — physical deterrence only, no data answer.

**The thesis:** a product that makes **delivery reliability and honest economics** the headline — not resolution or megapixels — wins the next generation of buyers. Our five pillars: **(1)** no-silent-death via heartbeat + dead-camera detection, **(2)** a free tier that keeps working forever, **(3)** −40 °C-rated lithium power with honest weather-adjusted battery math — and a pack swap that works with mittens on (§4.2, §4.13), **(4)** false-trigger discipline, **(5)** support as a feature (2/3-year warranty, advance replacement, no-fee repairs).

**Verdict in one line:** everyone sells cameras; nobody sells **reliability you can verify**. Make "you'll know it's working" the product.

---

## 2. Parity baseline — what we must match

The REVEAL 4.0 generation defines the 2026 spec floor. Anything below this is not competitive.

| Dimension | Parity requirement (2026) | Notes |
|---|---|---|
| **Photo/video** | 4K photos (2.5K mid option), 1080p video, **simultaneous photo+video on one trigger** | Tactacam popularized; now table stakes |
| **Night** | Selectable no-glow (80–100′) and low-glow (96–100′), switchable **from the app** | Pro/Ultra have it; expect it everywhere |
| **Connectivity** | LTE multi-carrier with **auto-carrier selection**, integrated SIM | No carrier locking, ever |
| **Storage** | 8 GB+ internal + optional SD slot | X 3.0's 16–32 GB U3-only quirk is a complaint |
| **Power** | 12×AA tray **plus** rechargeable pack option, external 12 V, solar-compatible | FlexPack R5/R10 is the pattern to match; we exceed it — see §4.2 (−40 °C chemistry) and §4.13 (glove swap) |
| **Cold rating** | Publish a *tested* operating minimum — ours: **−40 °C** discharge (Arctic pack charges to −30 °C) | No competitor publishes a tested minimum; r/trailcam users ask for −20 °C |
| **GPS** | Built-in GPS + move alert | Ultra's reserve-battery Active GPS is the stretch goal |
| **Display** | Side-facing LCD for setup/aiming | Live aiming via app at minimum |
| **App** | iOS/Android + web portal, remote settings, OTA firmware, camera sharing, live aiming | App quality decides refunds |
| **Setup** | QR-code onboarding, ≤ 10 min to first photo | GearJunkie: 9.8/10 setup on Ultra is the bar |
| **Plans** | ~$5–13/mo per camera, no activation fee, plan pause in offseason, multi-camera discounts | Category norm; pause matters to seasonal users |
| **Accessories** | Solar panel, battery pack(s), security box, tree mount | Ecosystem = lock-in + attach revenue |
| **Warranty (floor)** | 1 year | We should exceed, not match — see §4.9 |
| **Price anchors** | $100–160 camera; $200 with solar included | Pro 4.0 Solar at $200 is the value benchmark |

---

## 3. The pain-point ledger — what users complain about

Ranked by how often and how angrily the complaint appears across sources. Each pain maps to a solution in §4.

### P1. Silent death — the camera that stops without telling you
- "Stopped connecting a month ago with 78 percent battery" (r/Hunting, Moultrie Edge); "Base and Edge Pro did not check in for a few days… full battery, great reception" (r/trailcam); Edge 2 "wouldn't even fully turn on or connect" (r/trailcam).
- Tactacam: "Not taking pictures" with full battery and signal (r/TactacamRevealFans); XB failure anecdote — "Mine worked great…for about 3 months" (DFW Urban Wildlife); Facebook group: "Will not power on. Switched batteries, types and even various SD Cards."
- **Why it enrages:** the user discovers the failure when checking photos before the hunt — the entire season's data is gone, undetectable until it's too late. No competitor's app flags a dead camera proactively; Moultrie support's first step is "Check the status and last connection date" — manual policing.

### P2. Battery reality vs. marketing
- Trailcampro (X 3.0): 6.8 months in hybrid mode but "In Instant mode, battery life is poor"; GearJunkie's worst Ultra score (7.5/10) was battery; Outdoor Life measured R5 at "a little over a month" under instant-send + hundreds of photos/week.
- Cold kills: r/trailcam asks for cameras that work at −20 °C; Rokslide: "batteries weaken in the cold… lithium may work, but any cheaper [chem] no"; Meateater/Moultrie: rechargeable NiMH voltage sag makes cameras shut off early.
- Duracell chemistry changes broke cameras (Redmond hunt blog) — users blame the camera, not the battery.

### P3. The subscription squeeze
- Spypoint: "They keep charging my bank account" (r/trailcam); Trustpilot 1.3/5 (265 reviews) on the store, 1.5/5 on cameras; PissedConsumer 2.3/5 cites "billing issues" among top complaints.
- Tactacam: headline features (Live View, on-demand video, HD) are paywalled add-ons (Xtra $4–9/mo, Live View ~$6/mo) — GearJunkie con: "have to pay extra to unlock all features"; photo pools run dry (Starter = 250), then overage fees.
- Category-wide: plans are per-camera, seasonal users pay for idle months unless they remember to pause; churn-trap renewals and "prepaid SIM expires" patterns echo the luggage-tracker study.

### P4. Delivery delays and photo latency
- Spypoint Flex-M2 (Outdoor Life test): "the camera took a few hours to transmit a photo after it was triggered"; Tactacam X 3.0 (Trailcampro): "cellular transmission is sporadic" and batch-sending blocks new bursts; r/Hunting on Moultrie: cameras "did not check in for a few days."
- The value of a cellular camera collapses if the photo arrives after the buck leaves — users pay $5–15/mo precisely for *timeliness*.

### P5. False triggers eating plans and batteries
- "False triggers eat up the photos. The slightest thing can trigger a photo/video" (FB trailcam group, 1.2k likes); Spypoint Flex-S: "plenty of false triggers, no way to reset camera remotely" (Trustpilot).
- Whitetail Properties/Meateater list false triggers among top failures; every plan-limited user pays for wind-blown brush in $5 overages.

### P6. Connectivity as a black box
- "Shows weather where your PHONE is, not the camera" (Spypoint Trustpilot); no signal diagnostics — users can't tell if a miss is camera, tower, or plan; no remote reset (a $100 trip per incident); Tactacam: settings not changeable from web portal, antenna near-impossible to replace (Trailcampro).
- Reddit: "no signal after battery change" → $50/camera return fee for what is likely SIM/registration state.

### P7. Support and warranty failures
- Trustpilot: Tactacam 2.1/5 (n=9), Spypoint 1.3–1.5/5 (n=265–68); PissedConsumer Spypoint 2.3/5 (328 reviews): "poor customer service responsiveness," SIM/activation failures.
- Reddit (Tactacam): $50 per camera return fee for repair; week-long back-and-forths before RMA; 1-year warranties that expire mid-season-2; Facebook: "Tactacam Reveal XB camera fails to last, poor customer service."

### P8. Onboarding and setup friction
- QR/app flows generally good now, but Wi-Fi pairing, SD formatting rules (U3-only), battery-chem confusion (which AAs? — a whole content industry exists for this), and battery-latch QC (Outdoor Life's Moultrie Edge 4: "had to zip tie the rechargeable battery into place") still cost goodwill.

### P9. Ecosystem churn and accessory incompatibility
- Outdoor Life: Pro 4.0 "not compatible with previous lithium cartridge models" — accessory investment resets per generation; power accessories are 40–60% of a solar-rig's cost, so resets are felt as betrayal.

### P10. Legal/reputational gray zone
- "Why are states banning trail cameras?" is a PAA staple (wireless device bans on public land in several western states); hunters increasingly need **compliance information** — and cameras that can prove they're legal (or be disabled) per parcel.

---

## 4. Solutions — how we fill each gap

Ranked: the first four are the wedge; the rest are parity-plus.
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

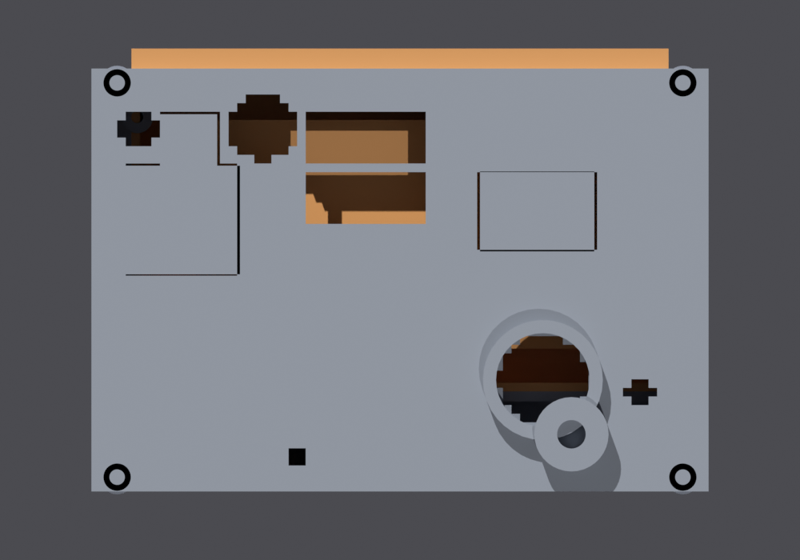
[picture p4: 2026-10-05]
hardware/chassis/out/preview-top.png

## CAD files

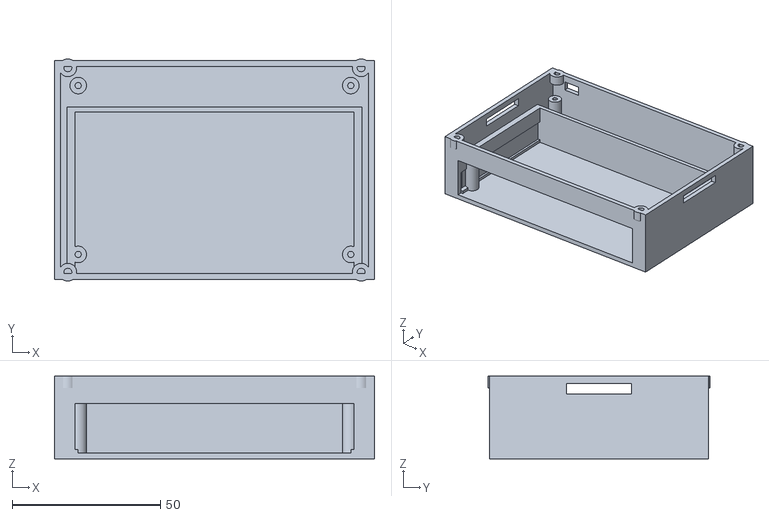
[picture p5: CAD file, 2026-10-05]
hardware/chassis/out/wapiti-base.stl
108.0 x 75.0 x 28.0

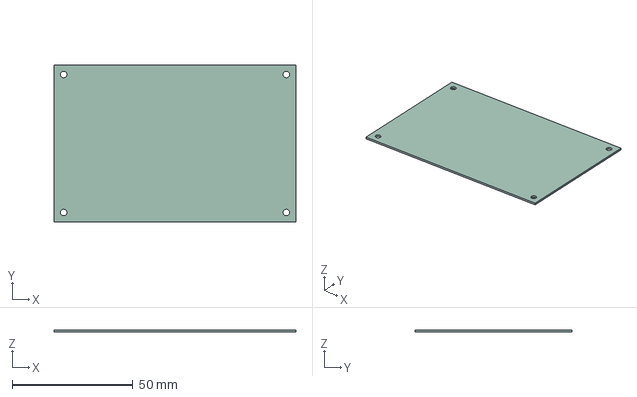
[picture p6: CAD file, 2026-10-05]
hardware/exports/wapiti.step
100.0 x 65.0 x 0.91 mm

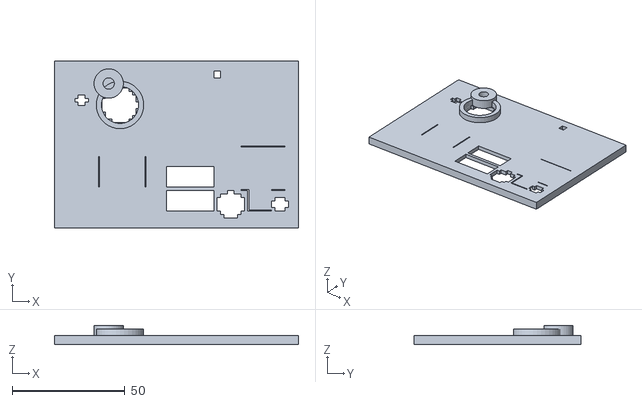
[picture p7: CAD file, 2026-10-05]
hardware/chassis/out/wapiti-lid.stl
108.0 x 74.0 x 8.50

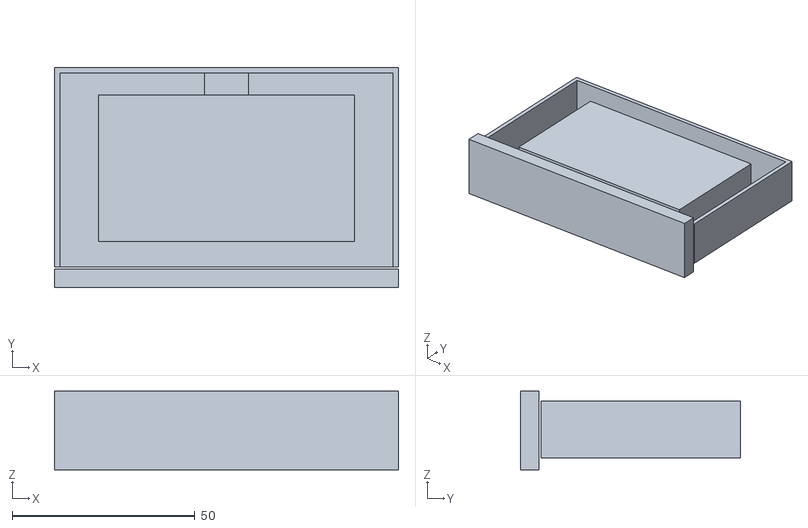
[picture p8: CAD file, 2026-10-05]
hardware/chassis/out/wapiti-tray.stl
94.0 x 60.0 x 21.5

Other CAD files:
hardware/chassis/out/wapiti-base.obj
hardware/chassis/out/wapiti-lid.obj
hardware/chassis/out/wapiti-tray.obj

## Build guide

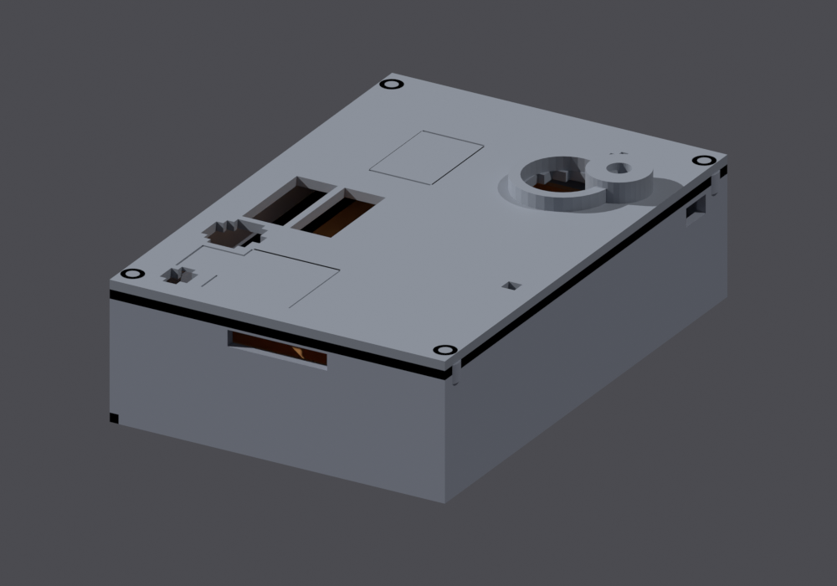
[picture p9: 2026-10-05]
hardware/chassis/out/preview-assembled.png

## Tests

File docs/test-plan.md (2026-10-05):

# Test Plan — Trail Camera (wapiti)

Modeled on the **luggage-tracker / wificam / blip.io** test-plan methodology: Python `requests` + pytest as the primary suite, prefixed test IDs, E2E chain tests, regression documentation with Mermaid flowcharts, gap coverage after code review, and markdown report generation. Device-side suites follow the lugtrax DEV/SAT pattern; **COLD** (−40 °C chamber + mitten rig) and **PQT** (product qualification) capture the certification and marketing claims defined in `competitive-analysis.md` §4.2/§4.13 and project-plan §5/§13.

## Table of Contents

1. [Test suites](#1-test-suites)
2. [Test IDs — Auth (WebAuthn)](#2-test-ids--auth-webauthn)
3. [Test IDs — Pairing](#3-test-ids--pairing)
4. [Test IDs — Ingest (device API)](#4-test-ids--ingest-device-api)
5. [Test IDs — Heartbeat & dead-camera detection (the wedge)](#5-test-ids--heartbeat--dead-camera-detection-the-wedge)
6. [Test IDs — Cameras & config](#6-test-ids--cameras--config)
7. [Test IDs — Photos & detections](#7-test-ids--photos--detections)
8. [Test IDs — PIR / edge AI / false triggers](#8-test-ids--pir--edge-ai--false-triggers)
9. [Test IDs — Power & battery honesty](#9-test-ids--power--battery-honesty)
10. [Test IDs — Networking & connectivity](#10-test-ids--networking--connectivity)
11. [Test IDs — Alerts](#11-test-ids--alerts)
11bis. [Test IDs — Local download (BLE-gated AP)](#11bis-test-ids--local-download-ble-gated-on-demand-ap-mode)
11ter. [Test IDs — Encrypted-at-rest media](#11ter-test-ids--encrypted-at-rest-media)
12. [Test IDs — MCP](#12-test-ids--mcp)
13. [Test IDs — OTA](#13-test-ids--ota)
14. [Test IDs — Subscriptions](#14-test-ids--subscriptions)
15. [Test IDs — Sharing](#15-test-ids--sharing)
16. [Test IDs — Admin](#16-test-ids--admin)
17. [Test IDs — Browser E2E (PWA)](#17-test-ids--browser-e2e-pwa)
18. [E2E chain tests](#18-e2e-chain-tests)
19. [Gap coverage tests](#19-gap-coverage-tests)
20. [Infra suites (SRV / SVC / PHP / MIG / BLD / SIM)](#20-infra-suites)
21. [Device-side suites (CAM / PWR / NET / COLD / BAT)](#21-device-side-suites)
22. [Product qualification (PQT-01..14)](#22-product-qualification-pqt-0114)
23. [Feature-to-test coverage matrix](#23-feature-to-test-coverage-matrix)
24. [Regression tests](#24-regression-tests)
25. [How to run](#25-how-to-run)

---

## 1. Test suites

| Suite | Language | Framework | Purpose | Run |
|---|---|---|---|---|
| **API tests** (primary) | Python 3 | `requests` + `pytest` | All HTTP endpoints, E2E chains, gap coverage | `python3 tests/test.py --host https://localhost:4440 -v` |
| **PHP unit/feature** | PHP 8.5 | Pest | Policies, TierGuard, heartbeat engine, battery forecast, WebAuthn ceremonies | `php artisan test` |
| **Browser E2E** | TypeScript | Playwright | PWA flows incl. WebAuthn `navigator.credentials.*` | `npx playwright test` |
| **Infra smoke** | Python 3 | stdlib (`subprocess`, `urllib`) | One-shot runner for SRV/SVC/PHP/MIG/BLD/SIM; writes markdown report | `python3 tests/regression.py` |
| **Device suites (CAM/PWR/NET)** | Python 3 | `requests` + SSH (paramiko) + serial | Bench camera: boot, capture, modem, power, radio | `python3 tests/test.py --device <ip> -k test_cam` |
| **Platform image (YOCT)** | Shell/CI + Python checks | kas/bitbake container + paramiko | Yocto image reproducibility, read-only rootfs, A/B OTA substrate, suspend-resume soak | `./device/yocto/build.sh` + `python3 tests/test.py --device <ip> -k test_yoct` |
| **Cold chamber (COLD)** | Lab protocol | Chamber + mitten rig + power analyzer | −40 °C gates: swap, latch, boot, upload, forecast derate | Per §20.4 (lab-run, results filed) |
| **Product qualification (PQT)** | Lab protocol | Lab fixtures | Drop, IP67, thermal, vibration, latch cycles — certification evidence | Per §21 (lab-run, results filed) |
| **Device fleet simulator (SIM)** | Python 3 | `trailcam-sim` container | N simulated cameras drive ingest/heartbeat/alerts without hardware | `./start-stop-services.sh --start --service=trailcam-sim` |

### 1.1 Catalog authority (sync rule)

`tests/test.py` is the single source of truth: **every ID documented here must run, and every test that runs must be documented.** Until a suite exists, its IDs are **pending** (specified + expected, not yet implemented). No ID may exist in only one place; project-plan §16 and the regression report totals move in lockstep with this file. Nothing is implemented yet — **0 passed / 301 pending**.

### 1.2 Summary (per-prefix counts)

| Category | Prefix | Count | Run-state |
|---|---|---|---|
| Auth (WebAuthn) | AUTH | 18 | pending |
| Pairing | PR | 8 | pending |
| Ingest (device API) | ING | 10 | pending |
| Heartbeat / dead-camera | HB | 8 | pending |
| Cameras & config | CAM | 16 | pending |
| On-device verify | CAM-DEV | 14 | pending |
| Platform image | YOCT | 6 | pending |
| Photos & detections | IMG | 8 | pending |
| PIR / edge AI | PIR | 8 | pending |
| Power & battery | PWR | 10 | pending |
| Networking | NET | 18 | pending |
| Alerts | ALR | 10 | pending |
| MCP | MCP | 20 | pending |
| OTA | OTA | 8 | pending |
| Local download (AP mode) | LDL | 12 | pending |
| Encrypted-at-rest media | ENC | 8 | pending |
| Field battery trials | BAT | 6 | pending (field) |
| Subscriptions | SUB | 8 | pending |
| Sharing | SHR | 6 | pending |
| Admin | ADM | 8 | pending |
| E2E chains | E2E | 16 | pending |
| Gap coverage | GAP | 20 | pending |
| Server health | SRV | 4 | pending |
| Service group | SVC | 4 | pending |
| Server boot | PHP | 5 | pending |
| MongoDB migration | MIG | 5 | pending |
| Builder smoke | BLD | 5 | pending |
| Device simulator | SIM | 6 | pending |
| Browser E2E | BROWSER | 4 | pending |
| Cold chamber | COLD | 8 | pending (lab) |
| Product qualification | PQT | 14 | pending (lab) |
| **Total** | | **301** | **0 passed / 301 pending** |

---

## 2. Test IDs — Auth (WebAuthn)

Contract reused verbatim from wificam/lugtrax (`web-auth/webauthn-lib`, RP_ID fixed per environment). Every test mints unique handles/emails per run (wificam regression #2 lesson).

| ID | Description | Endpoint | Expected |
|---|---|---|---|
| AUTH-01 | Register begin returns creation options | `POST /auth/register/begin` | 200, `publicKey.challenge` present |
| AUTH-02 | Register complete creates user + credential | `POST /auth/register/complete` | 201, session cookie set |
| AUTH-03 | Register begin rejects duplicate handle | `POST /auth/register/begin` | 409 |
| AUTH-04 | Register begin rejects duplicate email | `POST /auth/register/begin` | 409 |
| AUTH-05 | Register begin rejects short handle | `POST /auth/register/begin` | 422 |
| AUTH-06 | Register begin rejects invalid email | `POST /auth/register/begin` | 422 |
| AUTH-07 | Login begin returns request options | `POST /auth/login/begin` | 200, `publicKey.allowCredentials` present |
| AUTH-08 | Login begin rejects unknown handle | `POST /auth/login/begin` | 404 |
| AUTH-09 | Login complete verifies assertion, opens session | `POST /auth/login/complete` | 200, session cookie |
| AUTH-10 | Login complete rejects bad signature | `POST /auth/login/complete` | 401 |
| AUTH-11 | Status returns session (handle, role, tier) | `GET /auth/status` | 200 |
| AUTH-12 | Status 401 when unauthenticated | `GET /auth/status` | 401 |
| AUTH-13 | Add passkey stores second credential | `POST /auth/add-passkey/*` | 200 |
| AUTH-14 | Delete passkey blocks removing last one | `DELETE /auth/passkeys/{id}` | 409 |
| AUTH-15 | Recovery token enrolls new passkey, revokes old | `POST /auth/recovery` | 200 |
| AUTH-16 | Recovery rejects expired token | `POST /auth/recovery` | 401 |
| AUTH-17 | Logout kills session | `POST /auth/logout` | 200 |
| AUTH-18 | Session cookie flags (HttpOnly, Secure, SameSite=Strict) | (headers) | flags present |

---

## 3. Test IDs — Pairing

| ID | Description | Endpoint / surface | Expected |
|---|---|---|---|
| PR-01 | Pair token minted for known device_id | `POST /api/pair-tokens` | 201, `PRT-…`, 15-min TTL |
| PR-02 | Pair token rejected for unknown device_id | `POST /api/pair-tokens` | 404 |
| PR-03 | BLE handshake returns device_id + short code | (device BLE) | matches factory record |
| PR-04 | Pair via app writes token; camera posts `/device/v1/pair` | BLE + device API | 200, `device_token` issued |
| PR-05 | Pair token single-use | second pair attempt | 410 |
| PR-06 | Pair token expired → 410 | aged token | 410 |
| PR-07 | QR fallback: manual device_id + in-case code works | `POST /device/v1/pair` | 200 |
| PR-08 | Wi-Fi credentials handoff to C6 at setup | BLE write | C6 joins AP; live-aim stream reachable |

---

## 4. Test IDs — Ingest (device API)

| ID | Description | Endpoint | Expected |
|---|---|---|---|
| ING-01 | Device token required on `/device/v1/*` | `POST /device/v1/reports` (no auth) | 401 |
| ING-02 | Telemetry report accepted | `POST /device/v1/reports` | 202, `heartbeats` row written |
| ING-03 | Photo multipart accepted (4K JPEG, ≤ 12 MB) | `POST /device/v1/photos` | 201, `photos` row + object stored |
| ING-04 | Batch manifest (offline backlog) ingested in order | `POST /device/v1/photos` (batch) | order preserved, deduped |
| ING-05 | Config piggyback round-trip | any device call | response carries pending config delta + ack on next call |
| ING-06 | Rate limits: burst beyond N/min | hammer ingest | 429 with `retry_after` |
| ING-07 | Stale/revoked device token | old token post-unbind | 401 |
| ING-08 | Cross-user camera isolation | owner-scoped queries | 404, no leakage |
| ING-09 | Move-alert event recorded | `POST /device/v1/events` | 202, event row + rule evaluation |
| ING-10 | fw/hw versions recorded on first report | first report | `cameras.fw_version` set |

---

## 5. Test IDs — Heartbeat & dead-camera detection (the wedge)

The product's headline feature: missed check-ins must be *detected and pushed*, never discovered by the user.

| ID | Description | Surface | Expected |
|---|---|---|---|
| HB-01 | On-schedule check-in keeps status `healthy` | sim: hourly cadence | `status=healthy`, `expected_next_at` advances |
| HB-02 | Missed check-in + grace → `at_risk` | sim: skip 1 interval | transition row + push "missed check-in (battery 61%, last photo 11:04)" |
| HB-03 | 2× grace missed → `silent` | sim: skip 2 intervals | status `silent`, email + push sent |
| HB-04 | Retry cadence before alerting | sim: flaky camera | server retries at backoff; no premature alert within grace |
| HB-05 | Reconnect backfills transition | silent camera reports again | status → `healthy`, transition history preserved |
| HB-06 | Quiet hours suppress alert *delivery* (not detection) | quiet-hours rule | detection at correct time; delivery deferred |
| HB-07 | Status reflected in list + MCP `list_cameras` | API + MCP | `status` field present and consistent |
| HB-08 | Heartbeat SLA dashboard metrics | ops endpoint | missed-detection latency p50/p95 exported |

---

## 6. Test IDs — Cameras & config

| ID | Description | Endpoint | Expected |
|---|---|---|---|
| CAM-01 | Create camera (claim) binds owner | `POST /api/cameras/claim` | 201 |
| CAM-02 | Unclaimed device invisible in lists | `GET /api/cameras` | absent |
| CAM-03 | Rename + move to site | `PATCH /api/cameras/{id}` | 200 persisted |
| CAM-04 | Capture config validation (res enum, interval range, quiet hours) | `PATCH /api/cameras/{id}` | 422 out-of-range |
| CAM-05 | IR mode switch (no_glow/low_glow/auto) | `PATCH` + device piggyback | config reaches camera, acked |
| CAM-06 | Instant-send toggle | `PATCH` | forecast updates same request |
| CAM-07 | `GET /api/cameras/{id}/status` returns heartbeat + forecast + signal | status endpoint | all three blocks present |
| CAM-08 | Battery endpoint returns smart-pack telemetry | `GET …/battery` | `{gauge_pct, voltage_mv, temp_c, forecast_days, chemistry}` |
| CAM-09 | Theft-mode requires owner role | member call | 403 |
| CAM-10 | Theft-mode arm/disarm audited | `POST …/theft-mode` | `audit_log` row |
| CAM-11 | Rotate device token | `POST …/rotate-token` | old 401, new 200 |
| CAM-12 | Unbind → unclaimed, config wiped | `DELETE /api/cameras/{id}` | claim cleared |
| CAM-13 | Move-alert threshold config | `PATCH` | persisted, validated |
| CAM-14 | Signal diagnostics page data | `GET …/signal` | `{rsrp_dbm, rsrq_dbm, band, carrier, latency_ms_p50, last_towers[]}` |
| CAM-15 | Site CRUD + camera grouping | `/api/sites` | 201/200, listing grouped |
| CAM-16 | Cross-user camera access denied | `GET /api/cameras/{other}` | 404 |

---

## 7. Test IDs — Photos & detections

| ID | Description | Endpoint | Expected |
|---|---|---|---|
| IMG-01 | Photo list paginated, newest first | `GET /api/cameras/{id}/photos` | cursor pagination |
| IMG-02 | Class filter (deer/human/vehicle/empty) | `?class=deer` | only matching |
| IMG-03 | `empty` detections present but `billed=false` | DB inspection | audit trail without plan consumption |
| IMG-04 | Signed photo URLs expire | thumb fetch after TTL | 403/410 |
| IMG-05 | Edge v1 classifier classes + confidence persisted | sim inject | `ai_class`, `ai_confidence` set |
| IMG-06 | Classifier below min-confidence → class `other` | sim inject low-conf | rule not fired |
| IMG-07 | Battery forecast reflects instant-send change | toggle + report | `forecast_days` drops accordingly |
| IMG-08 | Delivery latency recorded per photo | DB | `latency_ms` p50/p95 queryable |

---

## 8. Test IDs — PIR / edge AI / false triggers

Bench + simulated; the false-trigger ledger (P5) requires empties never to bill.

| ID | Description | Surface | Expected |
|---|---|---|---|
| PIR-01 | PIR wake → capture ≤ 1.5 s | bench | measured, logged |
| PIR-02 | Radar+PIR fusion confirms real motion | bench walkthrough | capture; `detection` row |
| PIR-03 | PIR-only (no radar corroboration) on vegetation motion | fan/brush rig | suppressed or low-confidence, no upload |
| PIR-04 | Headlight/sweep test (classic false trigger) | bench | suppressed by radar rejection |
| PIR-05 | Edge v0 empty-frame discard | sim | stored on camera, counted, not uploaded |
| PIR-06 | Sensitivity wizard recommendation generated | API | suggestion after N false triggers |
| PIR-07 | Quiet-hours capture policy honored | config | no captures in window (or stored-only per config) |
| PIR-08 | Timelapse mode exists but plan-safe | config | timelapse frames count against pool, warned at enable |

---

## 9. Test IDs — Power & battery honesty

| ID | Description | Surface | Expected |
|---|---|---|---|
| PWR-01 | Sleep current ≤ 120 µA average | power analyzer | measured value logged |
| PWR-02 | Energy per 2.5K cycle ≤ 1.1 Wh | power analyzer | within budget |
| PWR-03 | Energy per 4K+video cycle ≤ 2.2 Wh | power analyzer | within budget |
| PWR-04 | Wake-to-capture ≤ 1.5 s cold | bench | measured |
| PWR-05 | Smart-pack detection (pack-ID) | insert pack | chemistry + gauge populate |
| PWR-06 | NiMH profile warns on voltage sag | insert NiMH tray | in-app warning, derated forecast |
| PWR-07 | Alkaline advisory shown | insert alkaline | advisory, not block |
| PWR-08 | Charge interlock < 0 °C | cold chamber | charging suspended + advisory (no plating) |
| PWR-09 | Weather-adjusted forecast | set site, inject weather | derate applied, "16 days at −25 °F tonight" shape |
| PWR-10 | Burn-down vs model ±15% over 72 h | bench soak | within tolerance |

---

## 10. Test IDs — Networking & connectivity

| ID | Description | Surface | Expected |
|---|---|---|---|
| NET-01 | LTE attach multi-IMSI eSIM | bench | registered, APN up |
| NET-02 | Auto-carrier selection reports carrier | telemetry | `carrier` set correctly |
| NET-03 | Instant-send upload p50 < 60 s | bench | measured, `latency_ms` recorded |
| NET-04 | Store-and-forward on outage | faraday box → restore | backlog drains in order |
| NET-05 | PSM between events (modem off) | power analyzer | current drops to sleep budget |
| NET-06 | SMS fallback (theft mode, data down) | SMSC stub | SMS ingested authenticated |
| NET-07 | GNSS fix + move alert | bench outdoors | fix + accuracy recorded |
| NET-08 | Reserve-battery anti-theft ping | main power removed + moved > ½ mi | pings every 6 h on reserve rail |
| NET-09 | Wi-Fi AP scan diagnostics | C6 | ≥ 3 MACs reported for placement coach |
| NET-10 | OTA download over LTE without photo loss | OTA + concurrent triggers | no lost captures |

**Cellular link discipline (§8.6 of project-plan; material distilled from
`interview-questions/interview_cellular_retries_qa.md`):** backoff with full jitter, idempotent
replays, outbox durability, signal gating, and fleet storm protection. Device-side tests run on the
bench with a fault-injecting proxy; fleet soak tests run against `trailcam-sim`.

| ID | Description | Surface | Expected |
|---|---|---|---|
| NET-11 | Backoff schedule deterministic with injected fake clock: exact sleeps = `min(cap, base·2^n)` + full jitter | device unit test (fake clock) | sleep sequence asserted exactly; no fixed-interval retry anywhere |
| NET-12 | Transient vs permanent: 503 retried, 400/401 never retried | fault proxy | 4xx fails fast — no retry burn, error surfaced to telemetry |
| NET-13 | Idempotent replay: same `Idempotency-Key` re-posted after lost ack | fault proxy drops response, device re-sends | original response replayed; **no duplicate photo/heartbeat rows** |
| NET-14 | Outbox survives reboot mid-upload: kill power during TX, restore | bench power-cut rig | unsynced rows re-drained in order after boot; nothing lost, nothing duplicated |
| NET-15 | Signal gating: collapsing RSRP → defer, never accelerate retries | programmable attenuator | modem parks to PSM; next attempt at next scheduled wake |
| NET-16 | Modem circuit breaker: N consecutive transport failures → cooldown, no TX storm | fault proxy | current trace shows no retry bursts; wake aligns with schedule |
| NET-17 | Fleet soak: 200 sim cameras through 30 min backend brownout (503s) | `trailcam-sim` fleet + proxy | ingest CPU/queue flat; retry volume ≤ budget; **no thundering herd on recovery** |
| NET-18 | Staggered reconnect: fleet offline 2 h (tower outage sim), backend restored | `trailcam-sim` fleet | reconnects spread over minutes (per-`device_id` windows), not a single spike |

---

## 11. Test IDs — Alerts

| ID | Description | Endpoint / surface | Expected |
|---|---|---|---|
| ALR-01 | Human/vehicle alert pushes within SLA | sim inject | push ≤ 60 s |
| ALR-02 | Species digest weekly (Pro) | job | digest email generated |
| ALR-03 | Battery-low rule fires at threshold | sim | alert + forecast link |
| ALR-04 | Delivery-slow rule fires on latency degradation | sim | honest status alert |
| ALR-05 | Move-alert (accel) fires theft candidate | bench | candidate, server decides burst |
| ALR-06 | Quiet hours respected | config | no delivery in window |
| ALR-07 | Channels per rule (push/email/sms) | config | only configured channels |
| ALR-08 | SSE stream authenticated | `/api/alerts/stream` unauth | 401 |
| ALR-09 | Alert payload includes photo thumb | inspect | thumb URL present |
| ALR-10 | Alert dedup (burst of same class) | sim | single alert per window |

---

## 11bis. Test IDs — Local download (BLE-gated on-demand AP mode)

Detailed plan: `project-plan.md` §5.4. Session = BLE handshake (pairing bond required) → per-session
SSID + WPA2 key → HTTPS on `192.168.77.1` with token-pinned self-signed cert → media manifest +
range GETs from eMMC/microSD. Bench harness: BLE central script (phone substitute) + Wi-Fi STA
client + `requests` with `verify=False` + cert-transcript pin check.

| ID | Description | Surface | Expected |
|---|---|---|---|
| LDL-01 | BLE-only session mint: `DLT-` token over authenticated BLE | C6 BLE | token, 10 min TTL, single use |
| LDL-02 | Session refused without pairing bond (fresh BLE central) | C6 BLE | rejected; no AP started |
| LDL-03 | AP SSID + WPA2 key unique per session | Wi-Fi scan | no static creds; SSID `wapiti-dl-<id>` |
| LDL-04 | Join + TLS handshake with token-pinned cert | HTTPS | app connects; wrong token rejected |
| LDL-05 | Media manifest lists correct files (filter honored) | HTTPS | `from/until/class` filter exact |
| LDL-06 | Range GET + resume across AP drop | Wi-Fi toggle | chunk resume; no corruption (hash check) |
| LDL-07 | Full-res pull throughput: 20 × 4K JPEGs < 5 min | bench | measured, logged |
| LDL-08 | Hard 10-min session cap enforced by C6 watchdog | bench timer | AP off mid-transfer; service stopped |
| LDL-09 | AP never active outside a session (idle scan) | Wi-Fi scan | SSID absent in normal operation |
| LDL-10 | Rate limit: 1 session / 5 min | repeat | second attempt refused until window |
| LDL-11 | `local_download` audit row synced on next check-in | ingest | row present server-side |
| LDL-12 | Session power cost logged as `local_dl_s` telemetry | reports | forecast derates accordingly |

---

## 11ter. Test IDs — Encrypted-at-rest media

Spec: `project-plan.md` §15.1 (§2 matrix row 24). Per-file AES-256-GCM CEKs, per-device KEK (C6 eFuse
wrap + cloud escrow under the account KMS key), `fscrypt` media store on eMMC + microSD, paired-phone
keystore cache for offline decrypt, theft-revocable key release. Harness: bench camera + generic USB
SD reader + a second camera as card-thief + API checks on escrow release/revocation.

| ID | Description | Surface | Expected |
|---|---|---|---|
| ENC-01 | Fresh capture on microSD is ciphertext: card pulled and read in a generic reader | bench + reader | no JPEG/PNG magic, no plaintext EXIF anywhere on the volume |
| ENC-02 | eMMC media store encrypted: raw dump over debug shows no plaintext media | bench | no media signatures in dump |
| ENC-03 | Card from camera A inserted into camera B | bench | refused/unreadable; camera B boots and operates normally |
| ENC-04 | Tampered wrapped-CEK is rejected; file quarantined, not served | SoC | decrypt error logged once; no retry loop |
| ENC-05 | Escrowed KEK released only to a WebAuthn-authenticated session of the bound account | API | 403 without session; bound session receives key |
| ENC-06 | Theft arm revokes key release; re-claimed flagged serial cannot obtain keys | API + E2E-14..15 chain | release refused; audit row written |
| ENC-07 | Paired phone decrypts AP-downloaded media offline with cached KEK; non-paired phone cannot | §5.4 harness | owner sees gallery with no network; stranger sees ciphertext only |
| ENC-08 | Crypto overhead measured; tamper events audit-logged and synced | SoC + ingest | < 1% of capture burst; `enc_tamper` row synced on next check-in |

---
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

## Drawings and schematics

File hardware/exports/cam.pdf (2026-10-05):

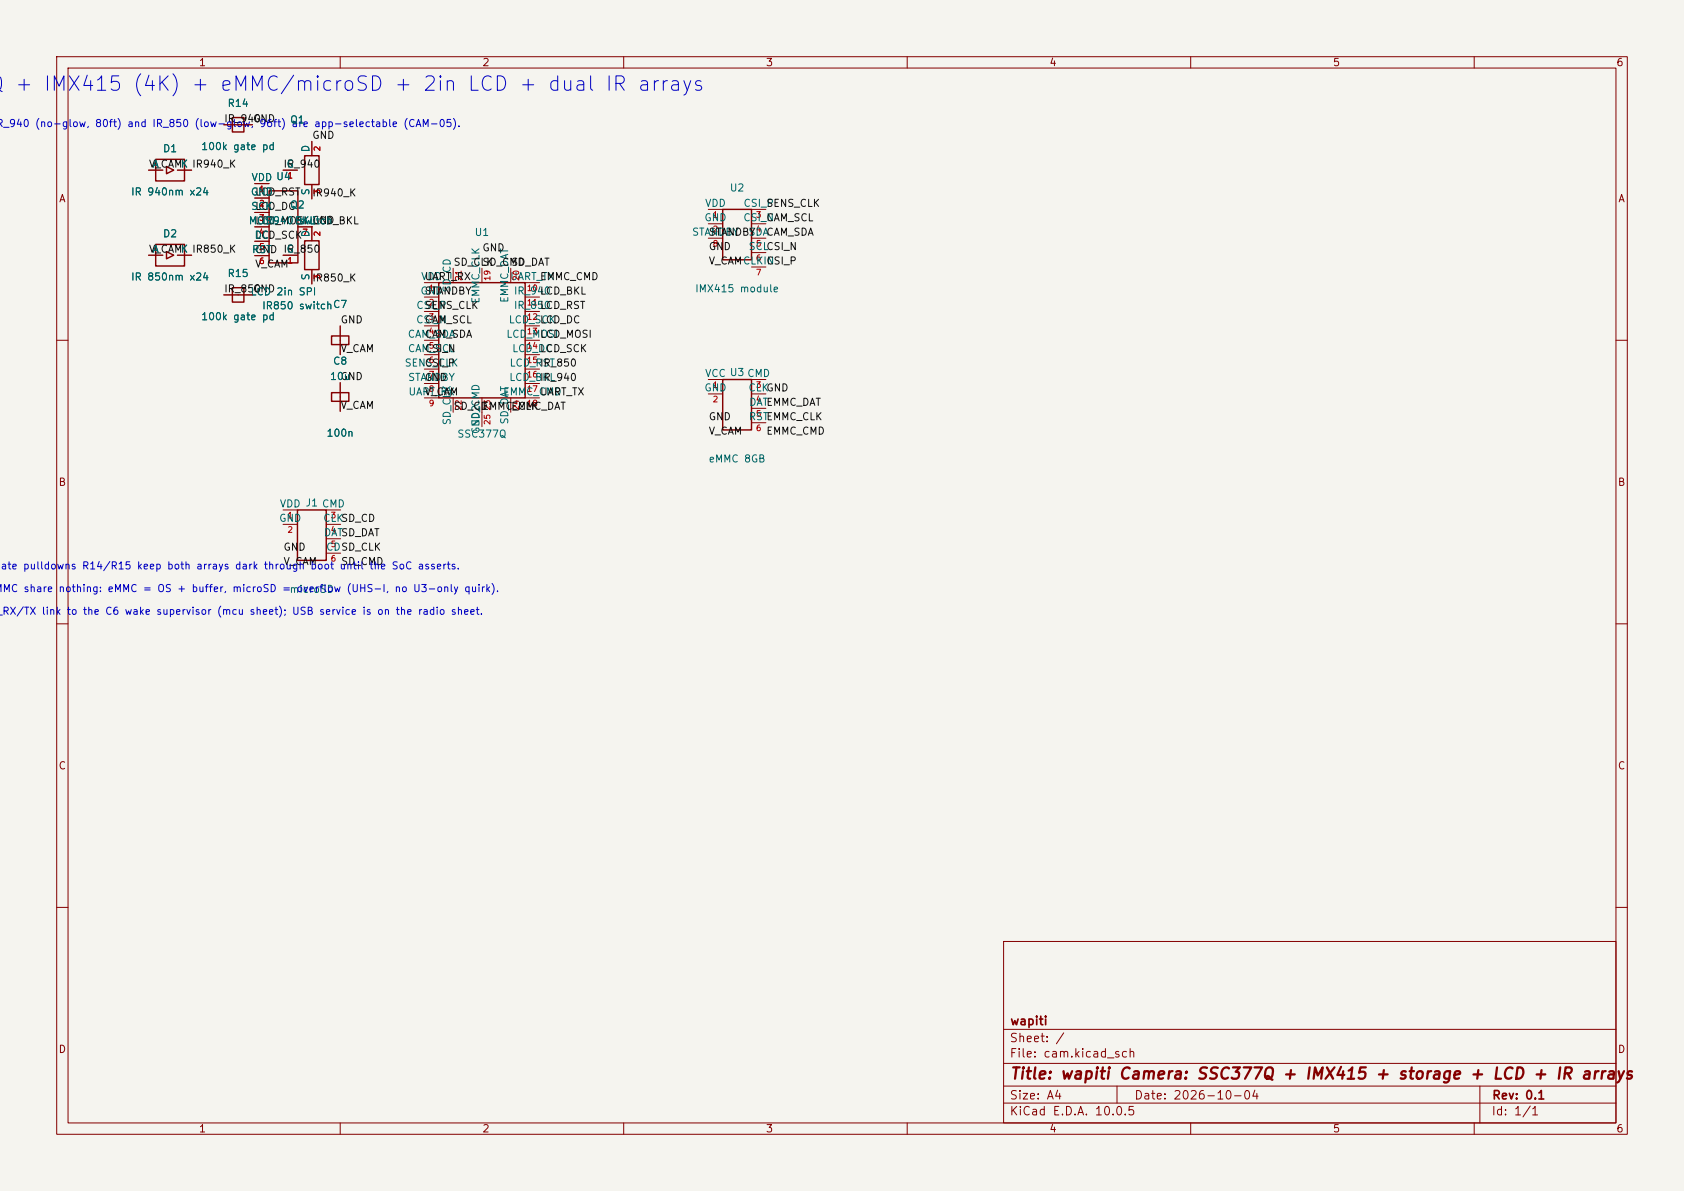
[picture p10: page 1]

UART_RX/TX link to the C6 wake supervisor (mcu sheet); USB service is on the radio sheet. SD + eMMC share nothing: eMMC = OS + buffer, microSD = overflow (UHS-I, no U3-only quirk). Gate pulldowns R14/R15 keep both arrays dark through boot until the SoC asserts. wapiti CAM - SSC377Q + IMX415 (4K) + eMMC/microSD + 2in LCD + dual IR arrays

GND IR_940 (no-glow, 80ft) and IR_850 (low-glow, 96ft) are app-selectable (CAM-05).

wapiti
Sheet: /
File: cam.kicad_sch
Title: wapiti Camera: SSC377Q + IMX415 + storage + LCD + IR arrays

Size: A4 | Rev: 0.1
KiCad E.D.A. 10.0.5 | Id: 1/1

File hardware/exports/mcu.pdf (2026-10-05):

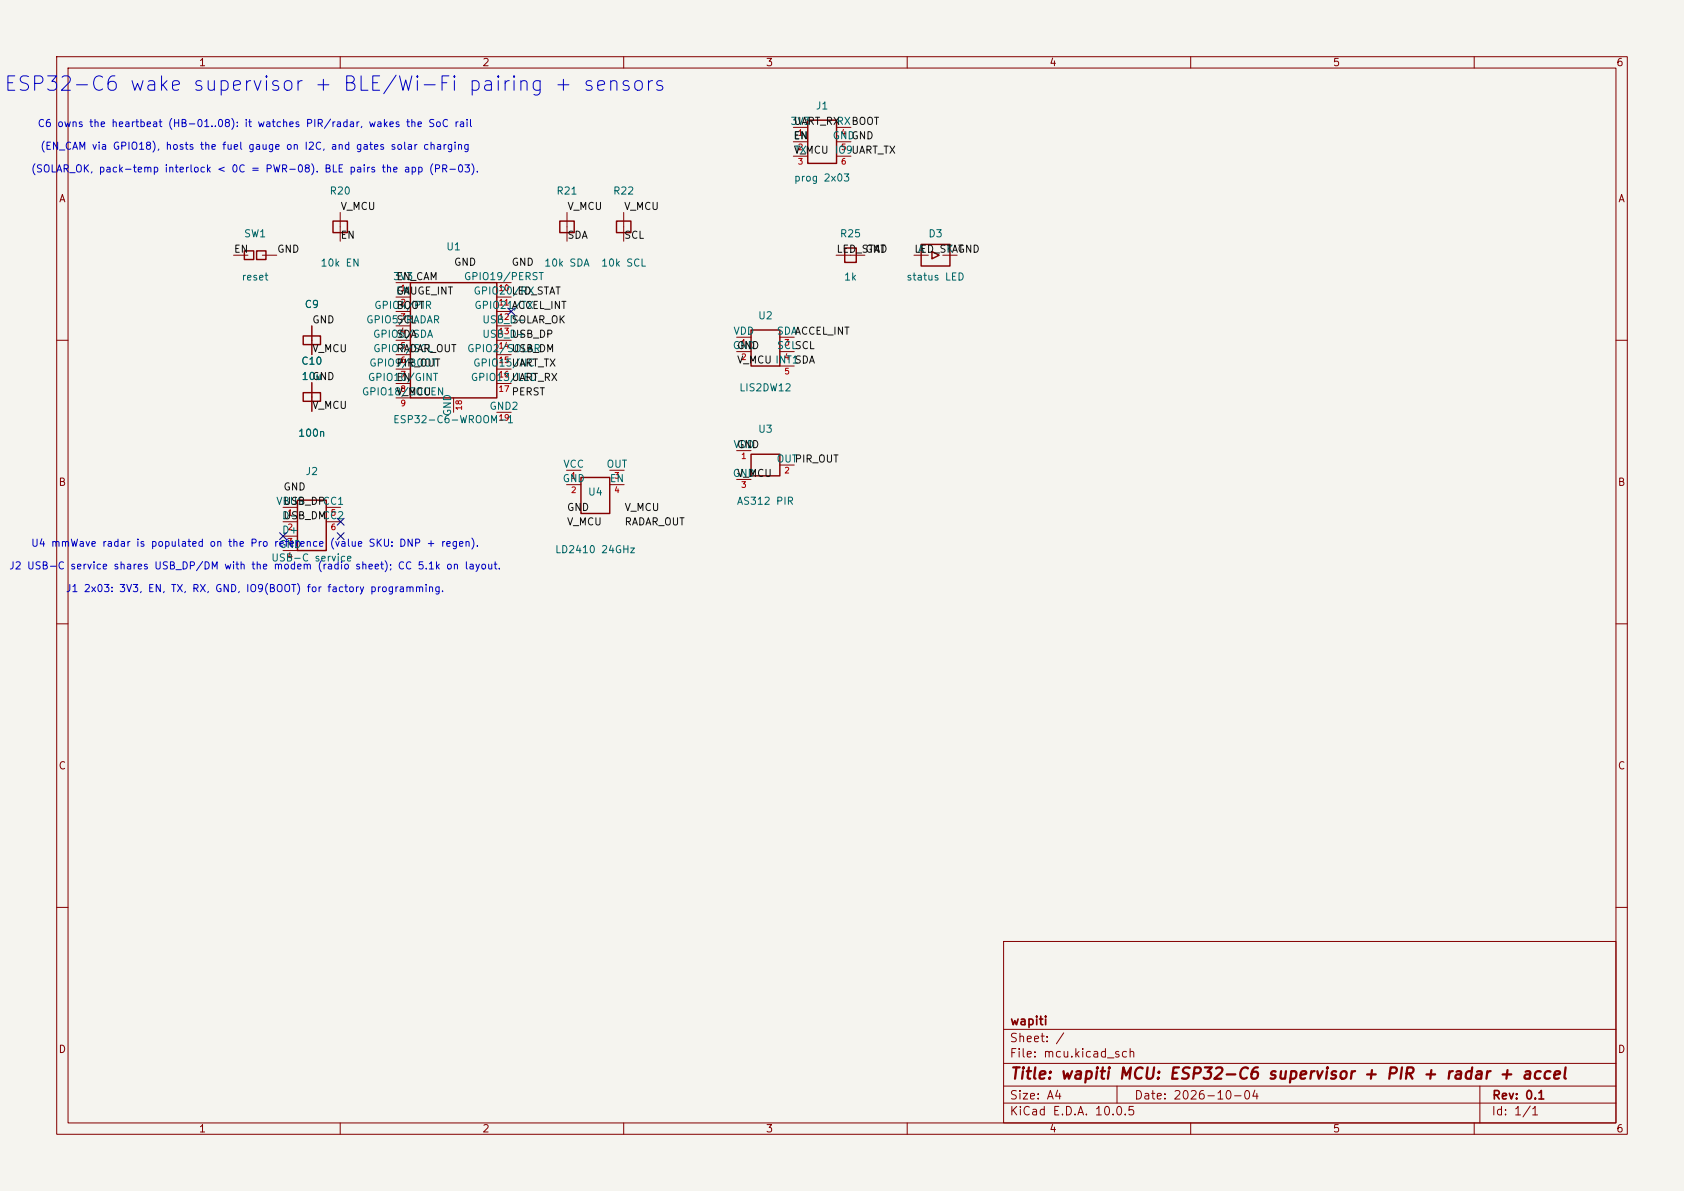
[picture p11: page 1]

wapiti MCU - ESP32-C6 wake supervisor + BLE/Wi-Fi pairing + sensors

SCL C6 owns the heartbeat (HB-01..08): it watches PIR/radar, wakes the SoC rail (EN_CAM via GPIO18), hosts the fuel gauge on I2C, and gates solar charging

wapiti
Sheet: /
File: mcu.kicad_sch
Title: wapiti MCU: ESP32-C6 supervisor + PIR + radar + accel

Size: A4 | Rev: 0.1
KiCad E.D.A. 10.0.5 | Id: 1/1

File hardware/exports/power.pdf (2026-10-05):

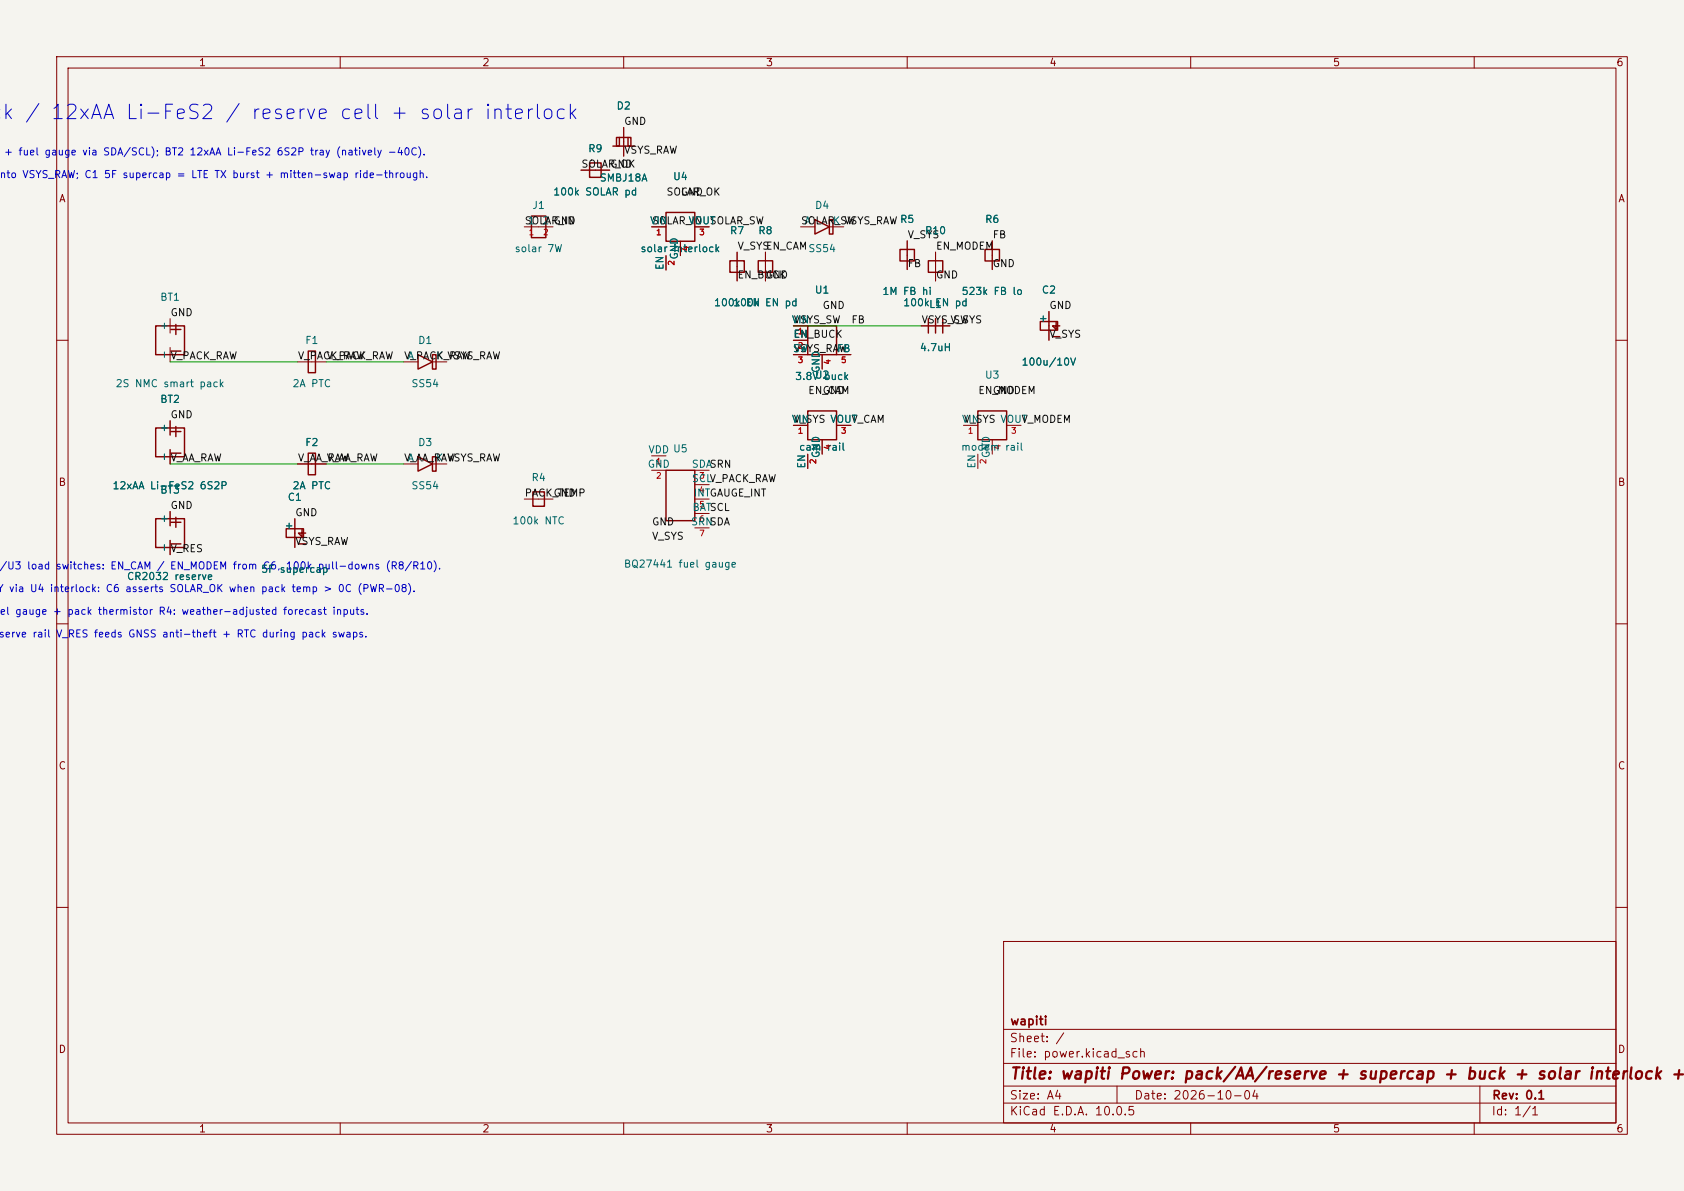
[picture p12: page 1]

wapiti POWER - smart pack / 12xAA Li-FeS2 / reserve cell + solar interlock

V_SYS U1 buck -> V_SYS 3.8V. U2/U3 load switches: EN_CAM / EN_MODEM from C6, 100k pull-downs (R8/R10). BT1 smart pack (pack-ID + fuel gauge via SDA/SCL); BT2 12xAA Li-FeS2 6S2P tray (natively -40C).

D1/D3/D4 SS54 OR-ing into VSYS_RAW; C1 5F supercap = LTE TX burst + mitten-swap ride-through.

Solar (J1) charges ONLY via U4 interlock: C6 asserts SOLAR_OK when pack temp > 0C (PWR-08). BT3 CR2032 reserve rail V_RES feeds GNSS anti-theft + RTC during pack swaps. U5 BQ27441 fuel gauge + pack thermistor R4: weather-adjusted forecast inputs. BT2

wapiti
Sheet: /
File: power.kicad_sch
Title: wapiti Power: pack/AA/reserve + supercap + buck + solar interlock + gauge

Size: A4 | Rev: 0.1
KiCad E.D.A. 10.0.5 | Id: 1/1

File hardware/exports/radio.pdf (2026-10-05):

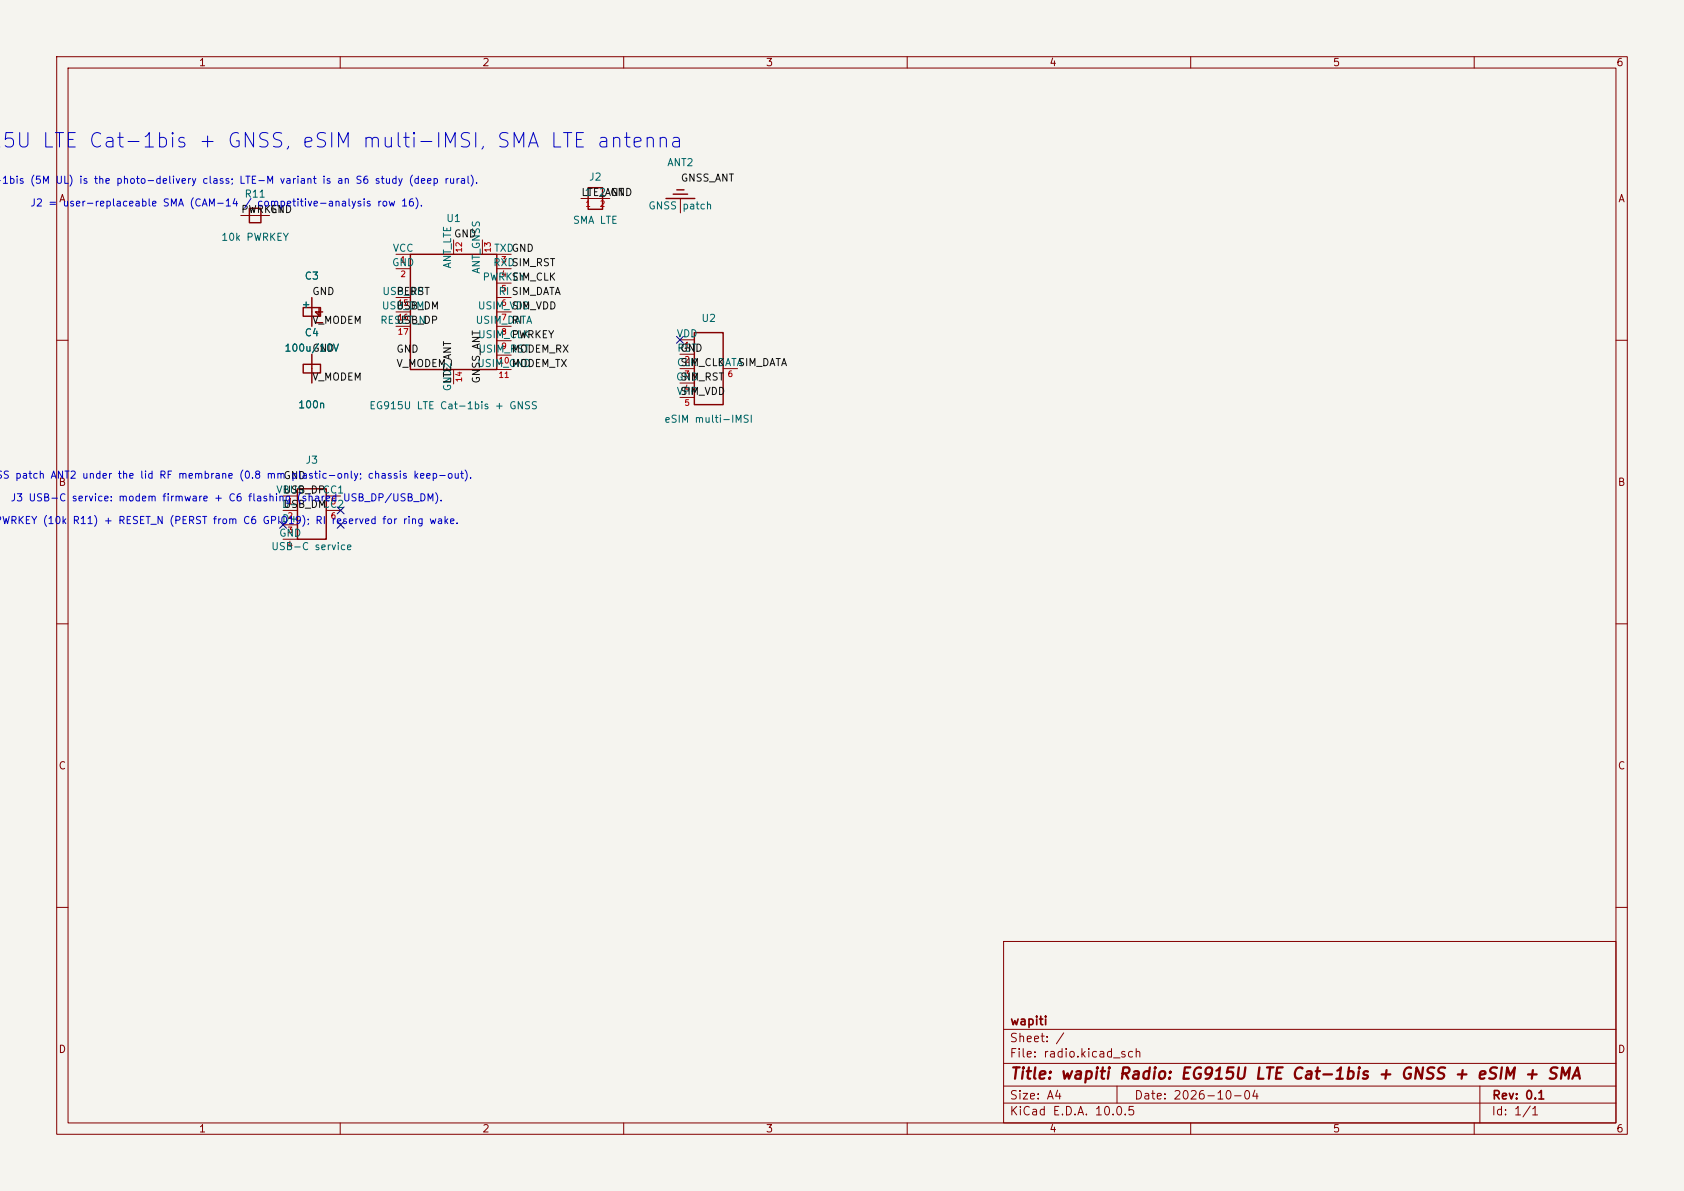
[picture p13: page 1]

Cat-1bis (5M UL) is the photo-delivery class; LTE-M variant is an S6 study (deep rural). C3

wapiti
Sheet: /
File: radio.kicad_sch
Title: wapiti Radio: EG915U LTE Cat-1bis + GNSS + eSIM + SMA

Size: A4 | Rev: 0.1
KiCad E.D.A. 10.0.5 | Id: 1/1

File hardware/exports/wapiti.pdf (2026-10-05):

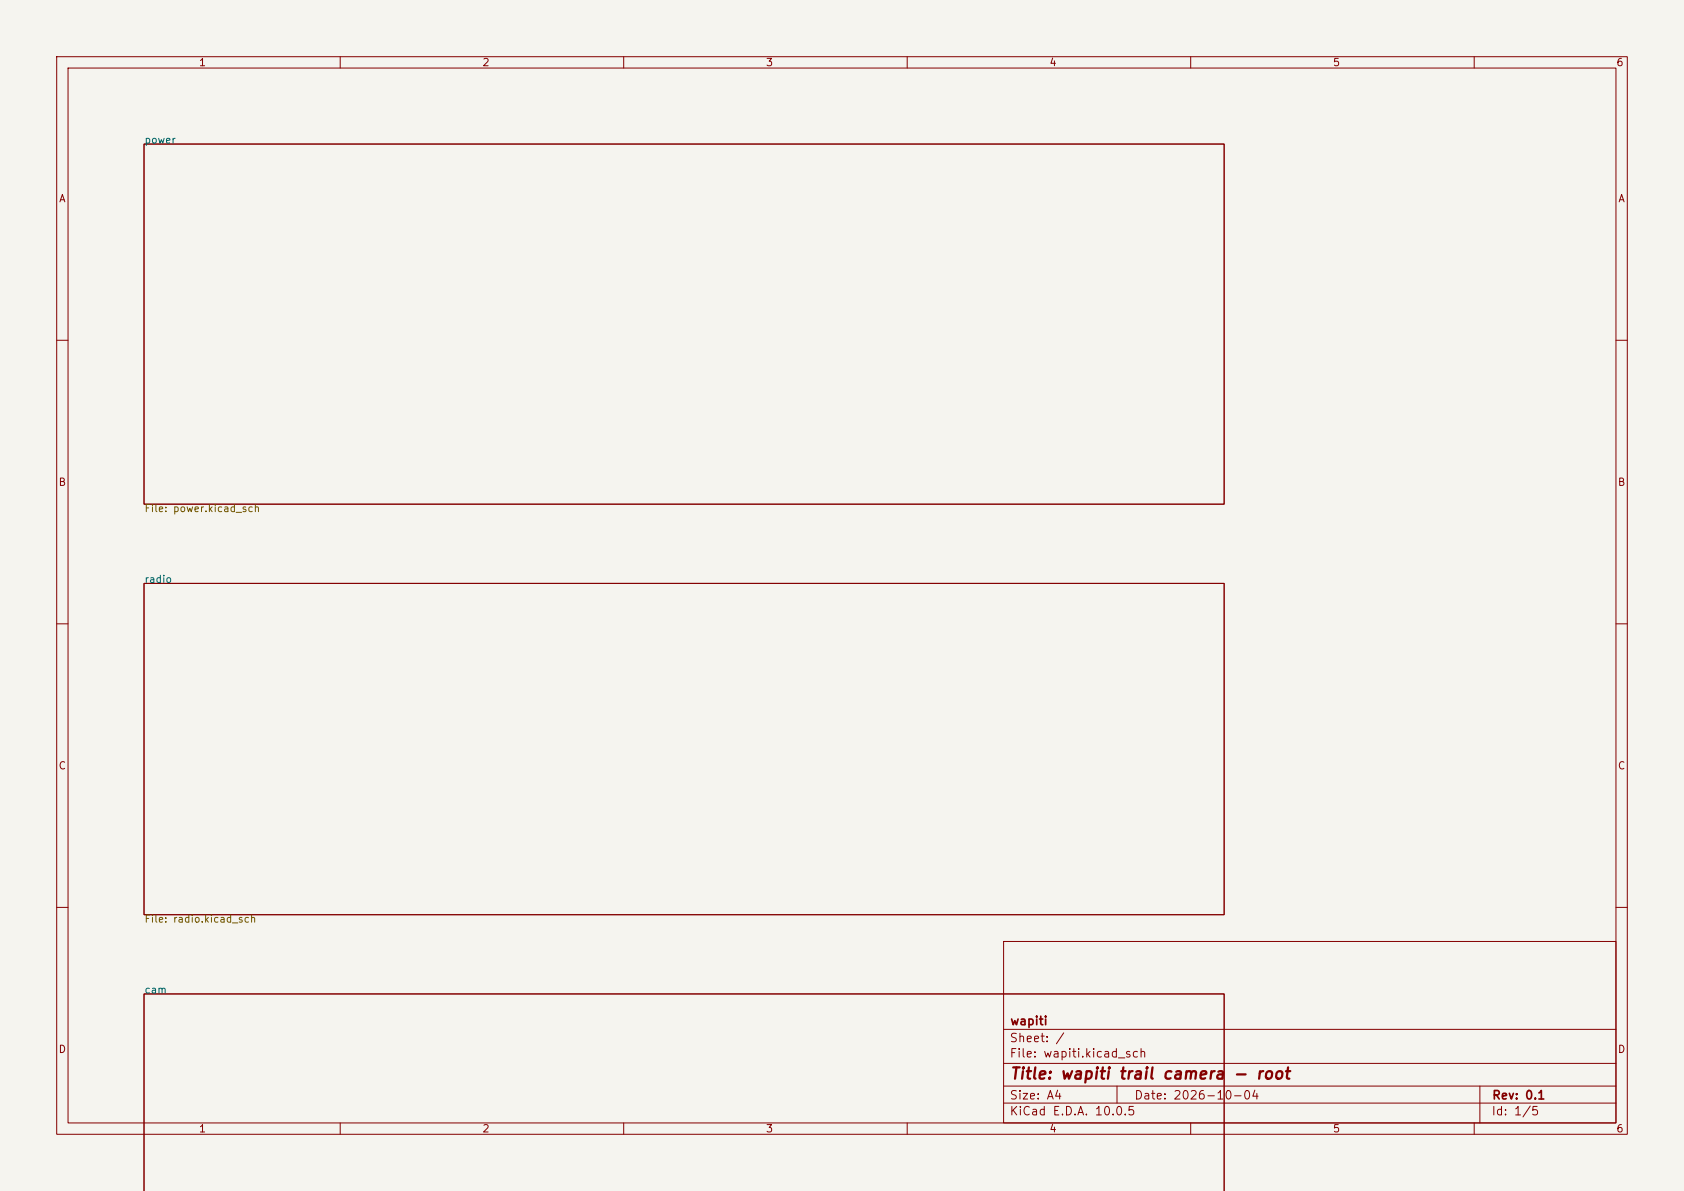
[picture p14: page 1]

wapiti
Sheet: / File: wapiti.kicad_sch | | D Date: 2026-10-04
Title: wapiti trail camera - root
Size: A4 | | | Rev: 0.1
KiCad E.D.A. 10.0.5 | | | Id: 1/5

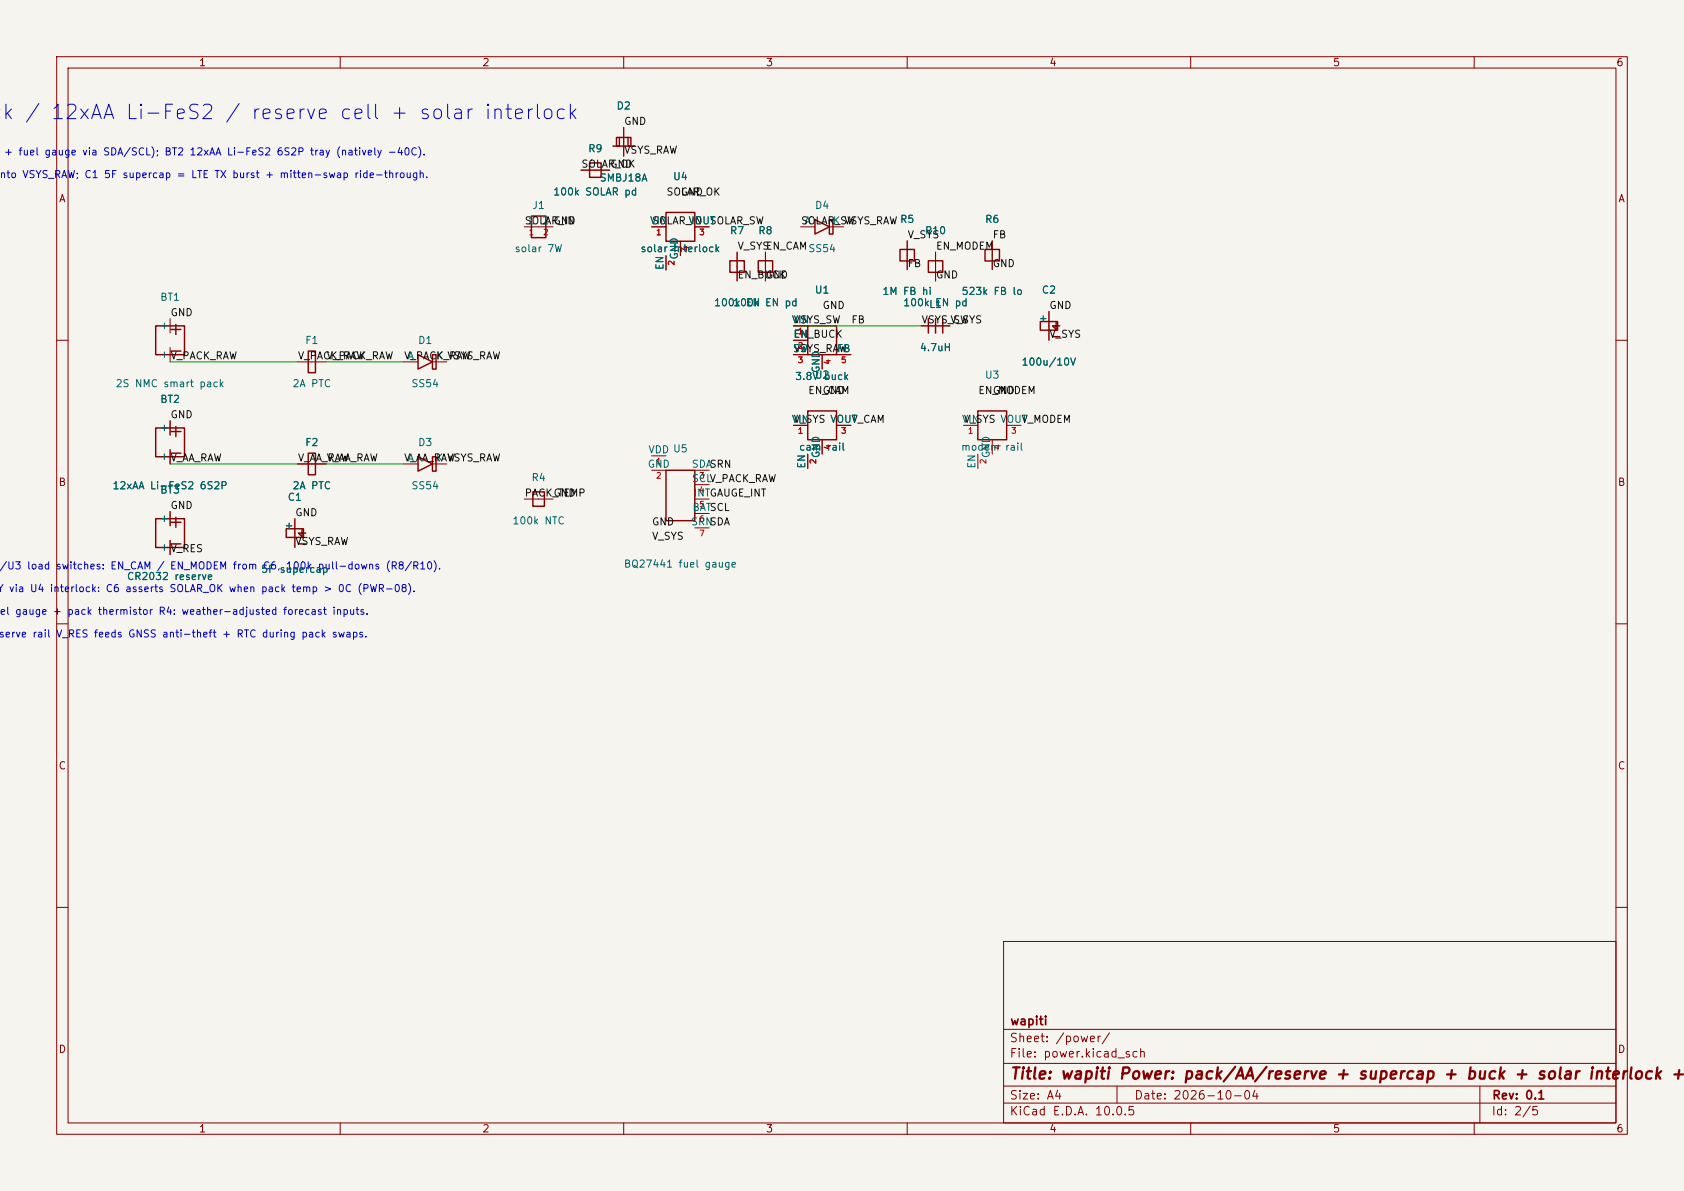
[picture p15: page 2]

wapiti POWER - smart pack / 12xAA Li-FeS2 / reserve cell + solar interlock

V_SYS U1 buck -> V_SYS 3.8V. U2/U3 load switches: EN_CAM / EN_MODEM from C6, 100k pull-downs (R8/R10). BT1 smart pack (pack-ID + fuel gauge via SDA/SCL); BT2 12xAA Li-FeS2 6S2P tray (natively -40C).

D1/D3/D4 SS54 OR-ing into VSYS_RAW; C1 5F supercap = LTE TX burst + mitten-swap ride-through.

Solar (J1) charges ONLY via U4 interlock: C6 asserts SOLAR_OK when pack temp > 0C (PWR-08). BT3 CR2032 reserve rail V_RES feeds GNSS anti-theft + RTC during pack swaps. U5 BQ27441 fuel gauge + pack thermistor R4: weather-adjusted forecast inputs. BT2

wapiti
Sheet: /power/
File: power.kicad_sch
Title: wapiti Power: pack/AA/reserve + supercap + buck + solar interlock + gauge

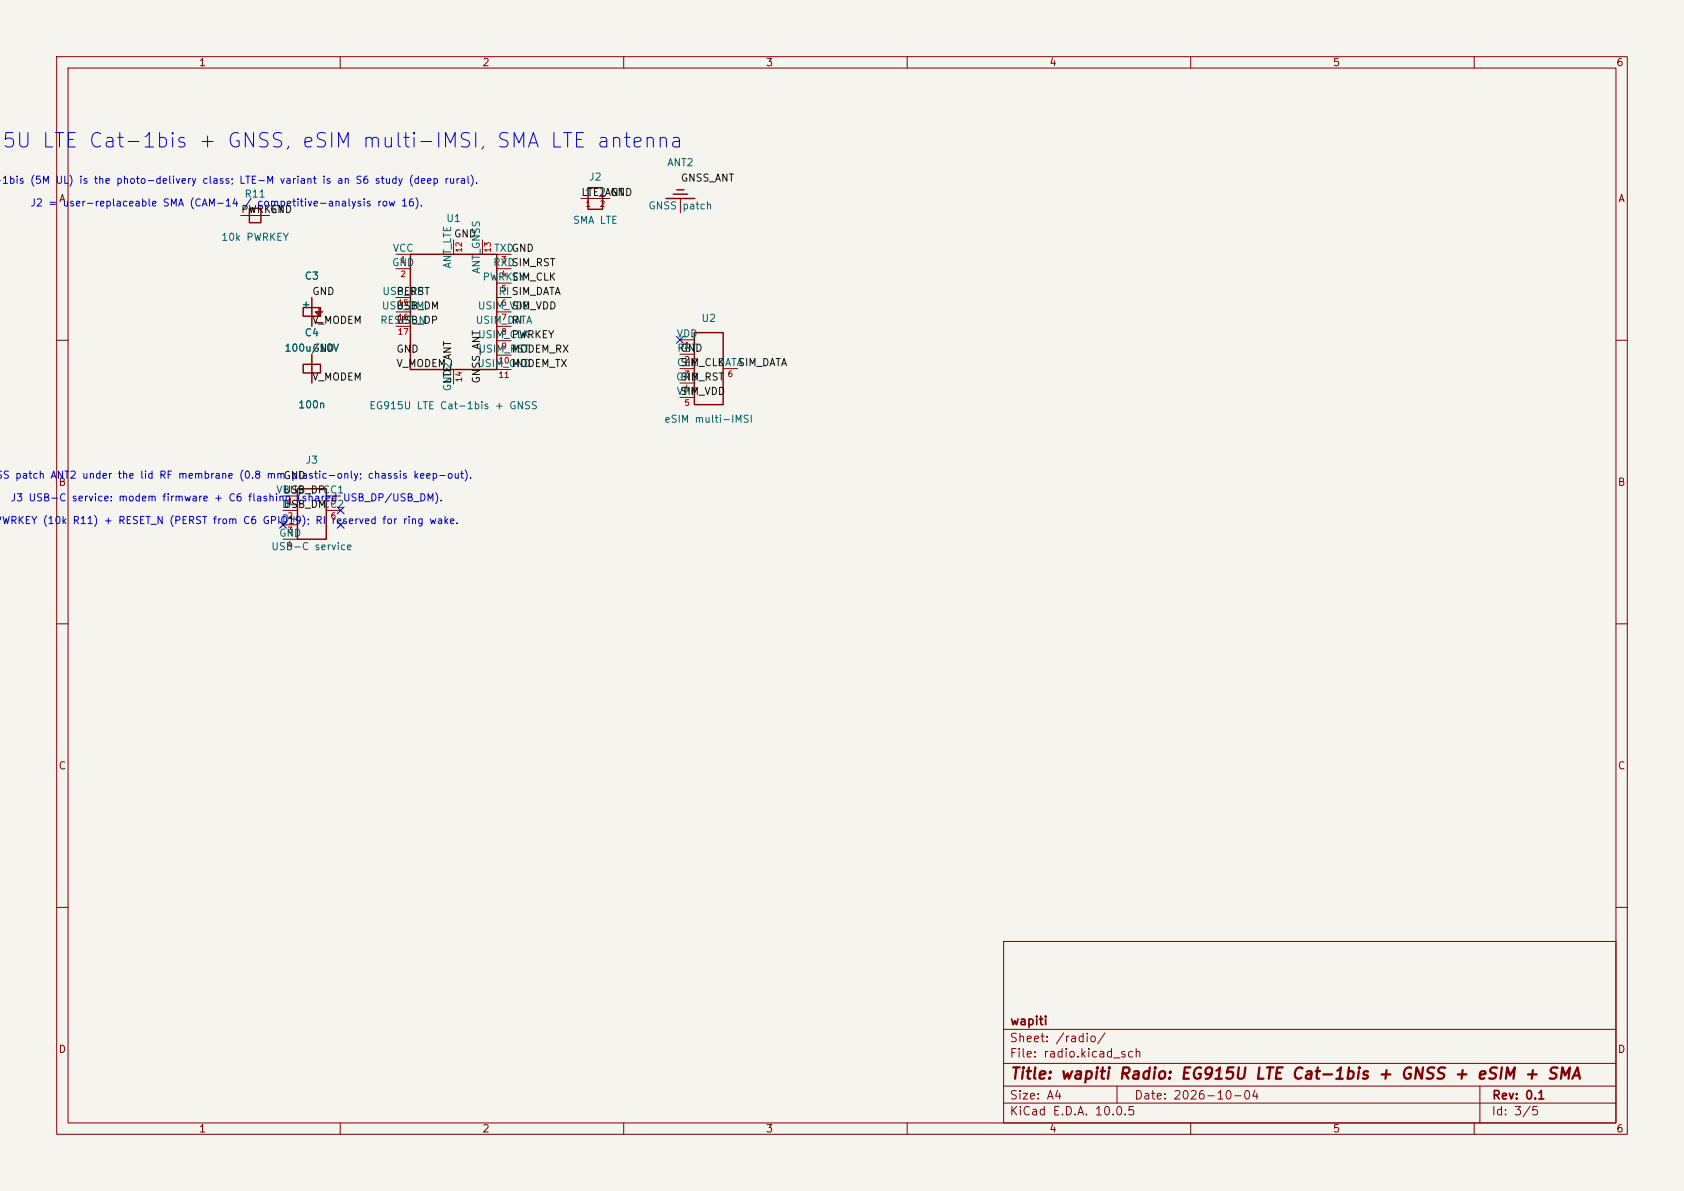
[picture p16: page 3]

Cat-1bis (5M UL) is the photo-delivery class; LTE-M variant is an S6 study (deep rural). C3

wapiti
Sheet: /radio/
File: radio.kicad_sch
Title: wapiti Radio: EG915U LTE Cat-1bis + GNSS + eSIM + SMA

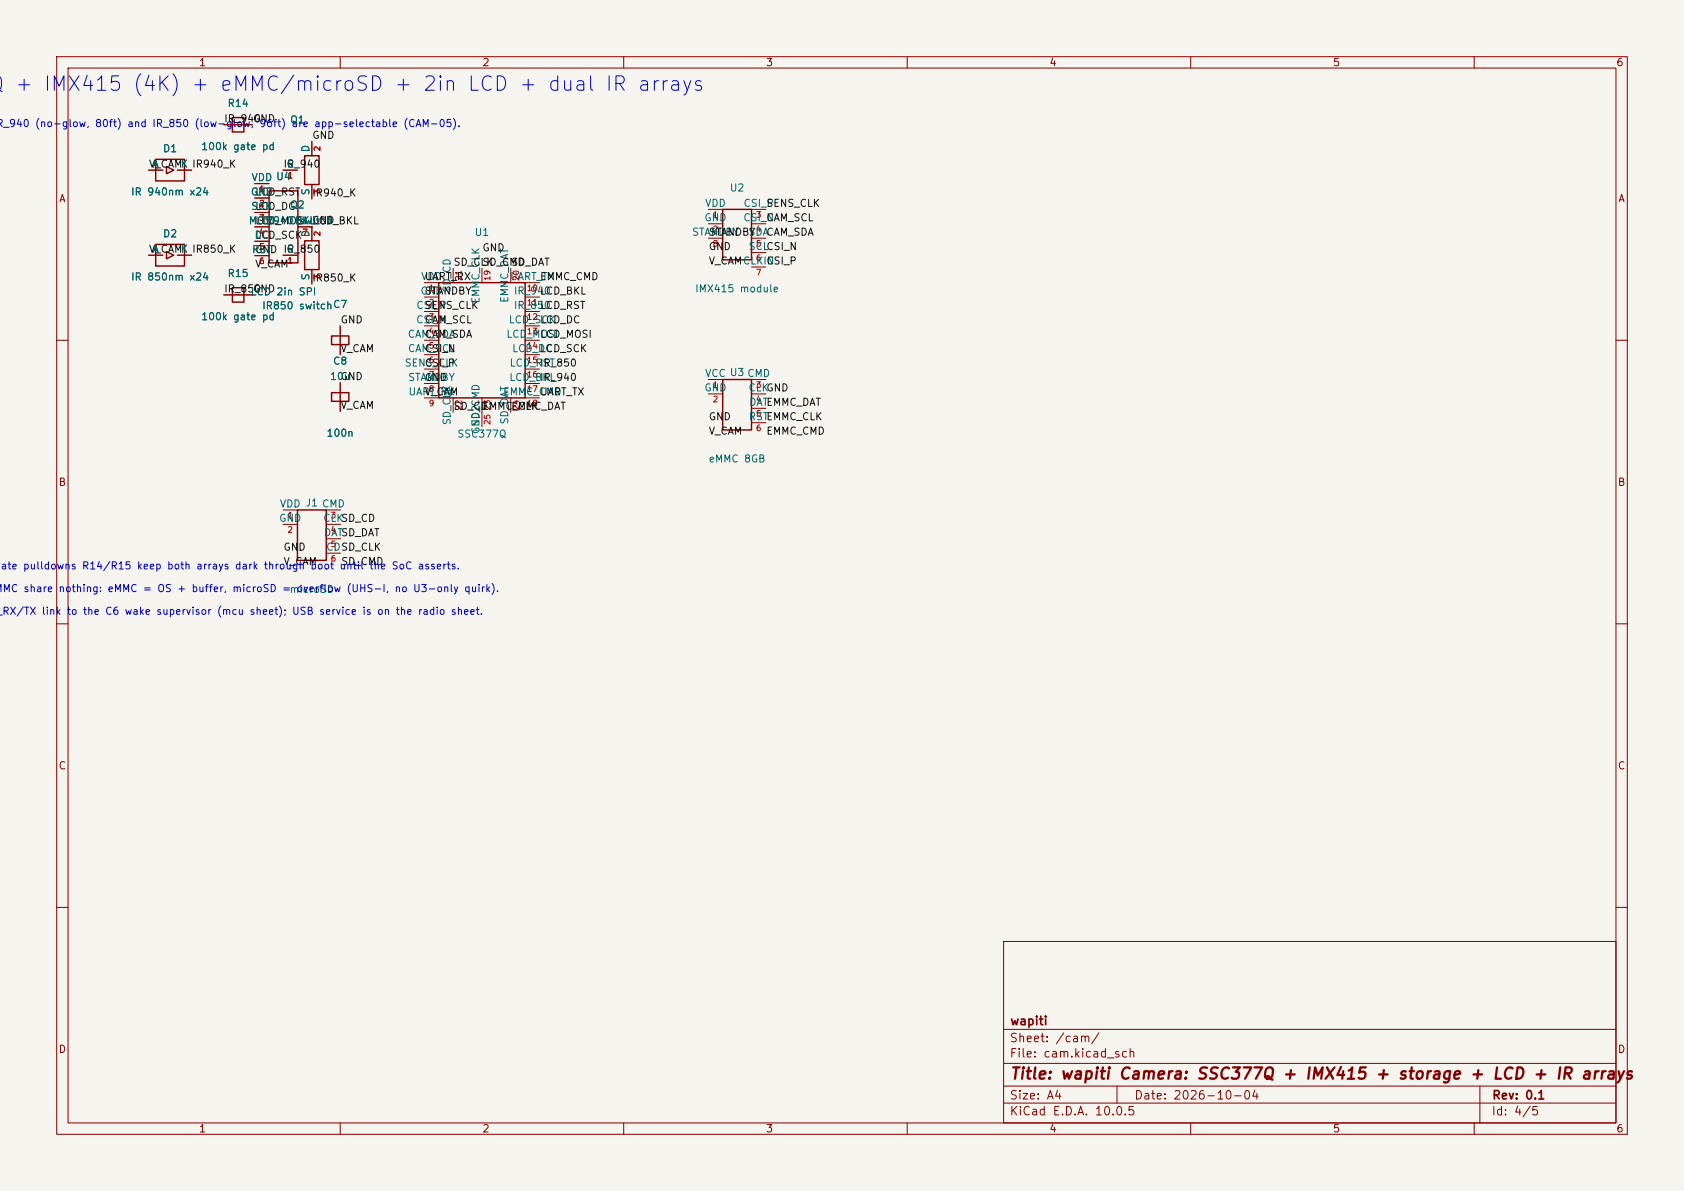
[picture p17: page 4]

UART_RX/TX link to the C6 wake supervisor (mcu sheet); USB service is on the radio sheet. SD + eMMC share nothing: eMMC = OS + buffer, microSD = overflow (UHS-I, no U3-only quirk). Gate pulldowns R14/R15 keep both arrays dark through boot until the SoC asserts. wapiti CAM - SSC377Q + IMX415 (4K) + eMMC/microSD + 2in LCD + dual IR arrays

GND IR_940 (no-glow, 80ft) and IR_850 (low-glow, 96ft) are app-selectable (CAM-05).

wapiti
Sheet: /cam/
File: cam.kicad_sch
Title: wapiti Camera: SSC377Q + IMX415 + storage + LCD + IR arrays

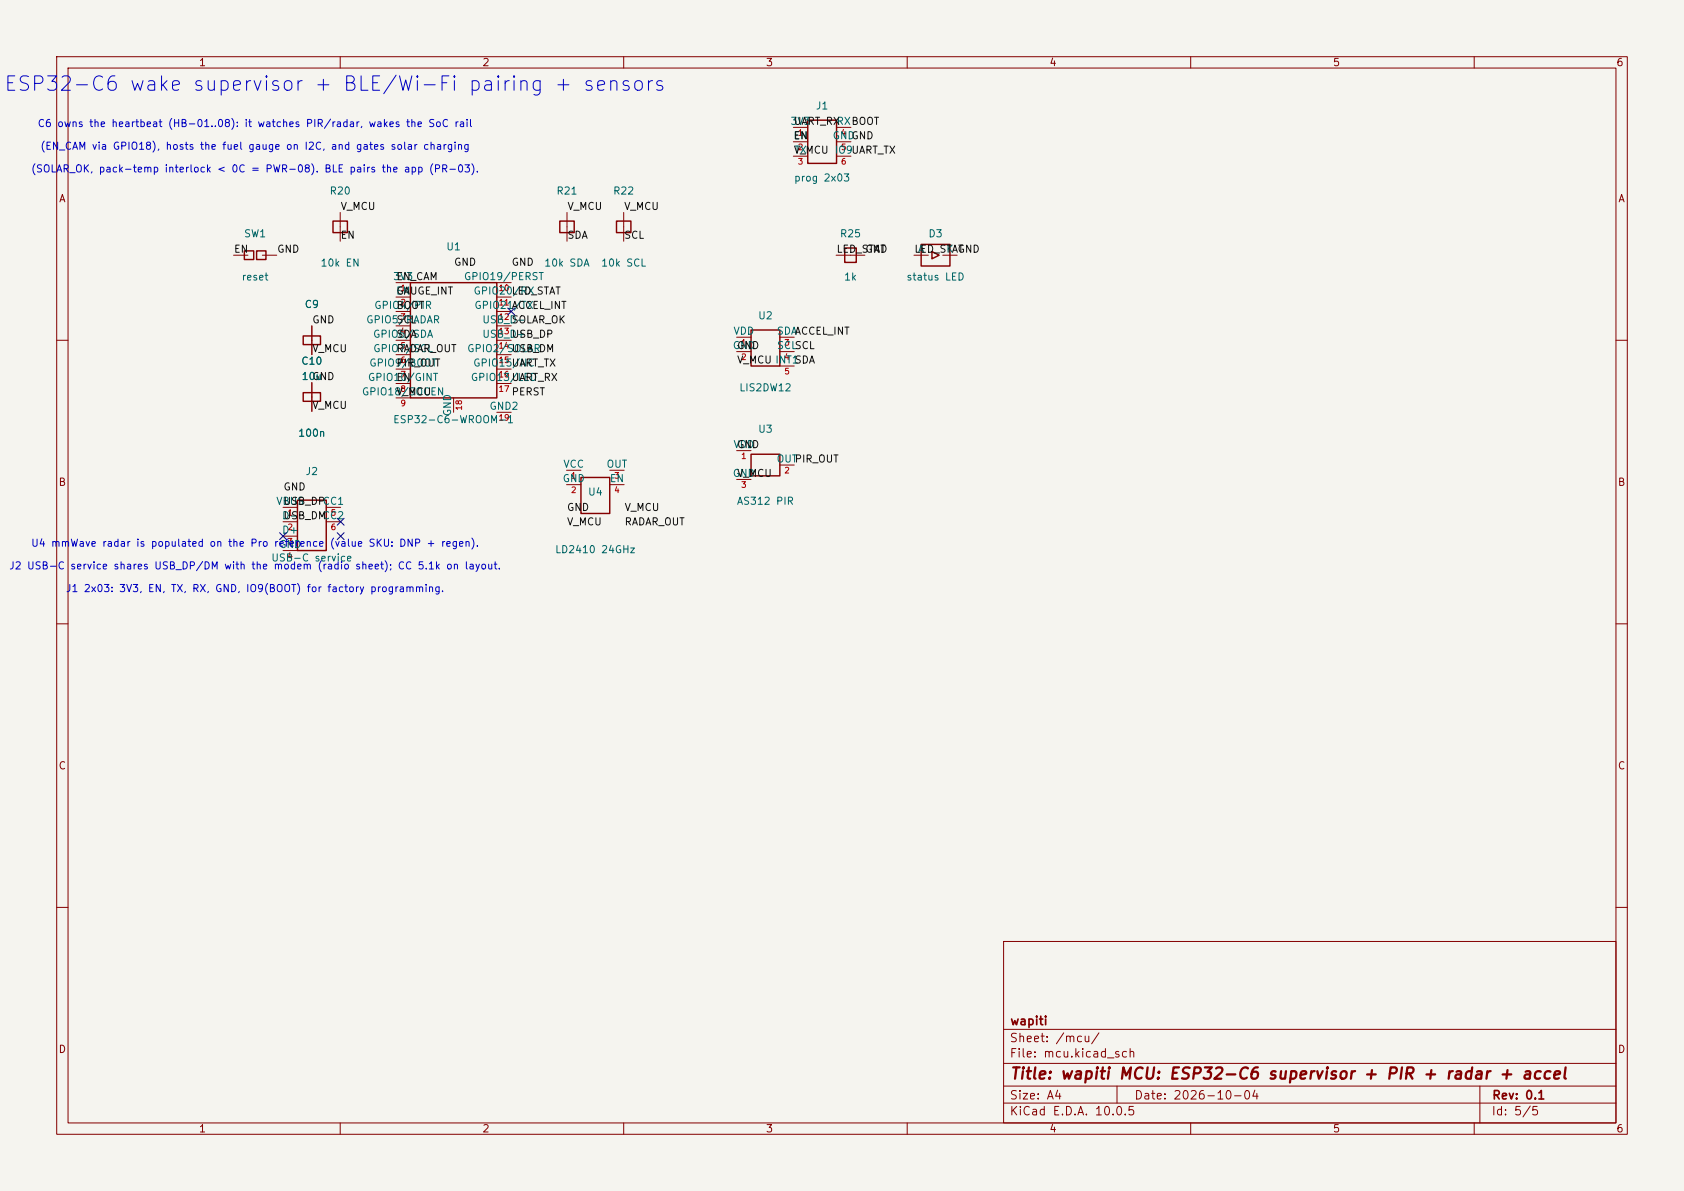
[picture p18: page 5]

wapiti MCU - ESP32-C6 wake supervisor + BLE/Wi-Fi pairing + sensors

SCL C6 owns the heartbeat (HB-01..08): it watches PIR/radar, wakes the SoC rail (EN_CAM via GPIO18), hosts the fuel gauge on I2C, and gates solar charging

wapiti
Sheet: /mcu/
File: mcu.kicad_sch
Title: wapiti MCU: ESP32-C6 supervisor + PIR + radar + accel

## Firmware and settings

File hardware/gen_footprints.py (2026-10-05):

#!/usr/bin/env python3
"""Generate the wapiti KiCad footprint library (wapiti.pretty).

Same approach as lugtrax (modeled on /repos/lora/hardware custom
footprints): through-hole module footprints with silkscreen pin names,
courtyard, and pad grids computed from the datasheet dimensions of the
wapiti BOM (project-plan §4/§5). Pad maps for multi-row LCC/BGA parts
are illustrative reductions - marked as such in each descr.

Footprints (single file each, KiCad 6+ s-expression format):
  Pack_Conn_5p           - smart-pack 5-pin connector (VPK, ID, TH, SCL, GND)
  Fuse_1206              - 1206 PTC resettable fuse (2-pad chip)
  Diode_SMA              - SS54 5 A schottky, DO-214AC (SMA) power OR-ing
  TVS_SOD-323            - SOD-323 TVS (VSYS clamp)
  R_0603 / C_0603        - 0603 chip two-pads
  L_1210                 - buck inductor 1210
  CP_Elec_6.3x7.7        - SMD electrolytic (5 F supercap ride-through)
  JST_PH_2p              - solar panel input 2-pin
  SMA_EdgeMount          - user-replaceable LTE antenna (edge SMA)
  SOT-23-5               - load switches EN_CAM / EN_MODEM / solar interlock
  SOT-23                 - IR-array MOSFET low-side switches
  SOT-23-8               - BQ27441 fuel gauge
  SOIC-8                 - 3.8 V buck
  EG915U                 - Quectel EG915U LTE Cat-1bis + GNSS LCC module
  NanoSIM_Push           - nano-SIM push-push (eSIM)
  ESP32-C6-WROOM-1       - C6 wake supervisor module, 19 castellated pads
  LGA-12_2x2mm           - LIS2DW12 accelerometer
  USB_C_Receptacle_16P   - USB-C 16-pin vertical SMD
  PinHeader_2x03_P2.54mm - 2x03 through-hole programming header
  Button_4x4mm           - 4x4 mm SMD tact switch (reset)
  Antenna_UMWiSE_1.6mm   - GNSS patch antenna pad (under lid RF membrane)
  SSC377Q_QFN            - camera SoC QFN 9x9 mm
  IMX415_Module          - 8.4 MP sensor module with lens (FPC stub)
  eMMC_153               - JEDEC 153-ball eMMC BGA 11.5x13 mm
  microSD_Push           - microSD push-push slot
  LCD_2in_FPC            - 2.0 in SPI TFT, FPC tail
  IR_Array_30x10         - IR LED array board 30x10 mm (940/850 nm)
  PIR_Dome               - AS312-class PIR with dome
  Radar_LD2410           - HLK-LD2410 24 GHz module (value SKU DNP)
"""

import os


def fp_header(name, descr, tags, attrs=("smd",)):
    return [
        '(footprint "%s" (version 20221018) (generator wapiti)' % name,
        '  (layer "F.Cu")',
        '  (descr "%s")' % descr,
        '  (tags "%s")' % tags,
        '  (attr %s)' % " ".join(attrs),
    ]


def ref_val(name, x, y):
    return [
        '  (fp_text reference "REF**" (at %s %s) (layer "F.SilkS")'
        % (x, y),
        "      (effects (font (size 1 1) (thickness 0.15)))",
        "  )",
        '  (fp_text value "%s" (at %s %s) (layer "F.Fab")' % (name, x, y + 3),
        "      (effects (font (size 1 1) (thickness 0.15)))",
        "  )",
    ]


def pad(num, shape, x, y, w, h, layers, drill=None, rot=0):
    d = " (drill %s)" % drill if drill else ""
    r = " (at %s %s %s)" % (x, y, rot) if rot else " (at %s %s)" % (x, y)
    return '  (pad "%s" %s %s (size %s %s)%s (layers %s))' % (
        num, shape, r, w, h, d, layers)


def rect_line(x1, y1, x2, y2, layer, width=0.12):
    return [
        '  (fp_line (start %s %s) (end %s %s)' % (x1, y1, x2, y2),
        "    (stroke (width %s) (type solid)) (layer %s))" % (width, layer),
    ]


def circle(center, end, layer, width=0.12):
    return [
        '  (fp_circle (center %s %s) (end %s %s)' % (center[0], center[1], end[0], end[1]),
        "    (stroke (width %s) (type solid)) (layer %s))" % (width, layer),
    ]


def fp_text_user(text, x, y, layer="F.Fab", size=0.8):
    return [
        '  (fp_text user "%s" (at %s %s) (layer "%s")' % (text, x, y, layer),
        "    (effects (font (size %s %s) (thickness 0.1))))" % (size, size),
    ]


def chip_fp(name, descr, tags, pads, body_w, body_h, pad_layers='"*.Cu" "*.Mask"'):
    """Simple 2-pad chip footprint. pads: [(num, x, y, w, h)]"""
    out = fp_header(name, descr, tags)
    out += ref_val(name, 0, -body_h / 2 - 1)
    # silk outline around the body
    out += rect_line(-body_w / 2 - 0.3, -body_h / 2 - 0.3,
                     body_w / 2 + 0.3, -body_h / 2 - 0.3, "F.SilkS")
    out += rect_line(-body_w / 2 - 0.3, body_h / 2 + 0.3,
                     body_w / 2 + 0.3, body_h / 2 + 0.3, "F.SilkS")
    # courtyard
    cx = max(abs(p[1]) + p[3] / 2 for p in pads) + 0.25
    cy = max(abs(p[2]) + p[4] / 2 for p in pads) + 0.25
    out += rect_line(-cx, -cy, cx, cy, "F.CrtYd", 0.05)
    for num, x, y, w, h in pads:
        out.append(pad(num, "rect" if num == "1" else "roundrect", x, y, w, h, pad_layers))
    out.append(")")
    return out


def gen_chip_families():
    fams = {}
    # 0603 passives
    for name, kind in (("R_0603", "Resistor"), ("C_0603", "Capacitor")):
        fams[name] = chip_fp(name, "%s 0603" % kind, kind.lower() + " 0603",
                             [("1", -0.75, 0, 0.9, 0.95), ("2", 0.75, 0, 0.9, 0.95)],
                             1.6, 0.8)
    # 1206 PTC fuse
    fams["Fuse_1206"] = chip_fp("Fuse_1206", "PTC resettable fuse 1206", "fuse ptc 1206",
                                [("1", -1.5, 0, 1.1, 1.6), ("2", 1.5, 0, 1.1, 1.6)],
                                3.2, 1.6)
    # SS54 5 A schottky, DO-214AC (SMA) - power OR-ing D1/D3/D4
    fams["Diode_SMA"] = chip_fp(
        "Diode_SMA", "SS54 5A schottky DO-214AC (SMA)", "diode schottky sma ss54",
        [("1", -1.8, 0, 1.8, 2.3), ("2", 1.8, 0, 1.8, 2.3)],
        4.3, 2.6)
    # SOD-323 TVS
    fams["TVS_SOD-323"] = chip_fp("TVS_SOD-323", "TVS diode SOD-323", "tvs diode sod323",
                                  [("1", -1.1, 0, 0.9, 1.0), ("2", 1.1, 0, 0.9, 1.0)],
                                  2.5, 1.3)
    # buck inductor 1210
    fams["L_1210"] = chip_fp("L_1210", "Power inductor 1210", "inductor 1210",
                             [("1", -1.5, 0, 1.1, 2.4), ("2", 1.5, 0, 1.1, 2.4)],
                             3.2, 2.5)
    return fams


def gen_cp_elec():
    name = "CP_Elec_6.3x7.7"
    out = fp_header(name, "SMD electrolytic 6.3x7.7mm (5F supercap ride-through)",
                    "capacitor electrolytic smd supercap")
    out += ref_val(name, 0, -6)
    out += circle((0, 0), (3.3, 0), "F.SilkS")
    out += circle((0, 0), (3.55, 0), "F.CrtYd", 0.05)
    out.append(pad("1", "rect", -2.4, 0, 1.6, 2.6, '"*.Cu" "*.Mask"'))
    out.append(pad("2", "roundrect", 2.4, 0, 1.6, 2.6, '"*.Cu" "*.Mask"'))
    out.append(")")
    return name, out


def gen_pack_conn():
    """Smart-pack 5-pin: VPK + pack-ID + thermistor + fuel-gauge SCL + GND.

    JST-PH-style 2.0 mm pitch through-hole header; keyed pin 1 = VPK.
    """
    name = "Pack_Conn_5p"
    out = fp_header(name, "Smart pack connector 5-pin 2.0mm (VPK ID TH SCL GND)",
                    "battery pack connector jst-ph 5p", attrs=("through_hole",))
    out += ref_val(name, 0, -6)
    n = 1
    for i in range(5):
        x = -4.0 + i * 2.0
        out.append(pad(str(n), "circle", x, 0, 1.4, 1.4, '"*.Cu" "*.Mask"', drill=0.7))
        n += 1
    # shroud outline
    out += rect_line(-6.2, -2.1, 6.2, 2.1, "F.SilkS")
    out += rect_line(-6.5, -2.4, 6.5, 2.4, "F.CrtYd", 0.05)
    out += fp_text_user("+", -4.0, -3.4, "F.SilkS", 1.5)
    out.append(")")
    return name, out


def gen_jst_ph_2p():
    """Solar panel input, 2-pin 2.0 mm pitch."""
    name = "JST_PH_2p"
    out = fp_header(name, "JST-PH 2-pin solar input 2.0mm", "jst ph solar 2p",
                    attrs=("through_hole",))
    out += ref_val(name, 0, -5)
    out.append(pad("1", "circle", -1.0, 0, 1.4, 1.4, '"*.Cu" "*.Mask"', drill=0.7))
    out.append(pad("2", "circle", 1.0, 0, 1.4, 1.4, '"*.Cu" "*.Mask"', drill=0.7))
    out += rect_line(-3.2, -2.1, 3.2, 2.1, "F.SilkS")
    out += rect_line(-3.5, -2.4, 3.5, 2.4, "F.CrtYd", 0.05)
    out.append(")")
    return name, out


def gen_sma_edge():
    """Edge-mount SMA receptacle: user-replaceable LTE antenna (CAM-14)."""
    name = "SMA_EdgeMount"
    out = fp_header(name, "SMA edge-mount receptacle (LTE antenna, user-replaceable)",
                    "sma antenna edge lte")
    out += ref_val(name, 0, -6)
    # center signal pad reaching the board edge
    out.append(pad("1", "rect", -1.6, 0, 3.2, 2.2, '"*.Cu" "*.Mask"'))
    # ground petals
    for y in (-3.0, 3.0):
        out.append(pad("2", "rect", -1.6, y, 3.2, 2.0, '"*.Cu" "*.Mask"'))
    out += rect_line(-4.0, -5.0, 2.6, 5.0, "F.SilkS")
    out += rect_line(-4.3, -5.3, 2.9, 5.3, "F.CrtYd", 0.05)
    out += fp_text_user("board edge ->", 4.6, 0, "F.Fab")
    out.append(")")
    return name, out

def gen_sot23_5():
    name = "SOT-23-5"
    out = fp_header(name, "SOT-23-5 load switch (EN_CAM/EN_MODEM/solar interlock)",
                    "load switch sot23-5")
    out += ref_val(name, 0, -3.5)
    xs = [-0.95, 0, 0.95]
    for i, x in enumerate(xs, 1):
        out.append(pad(str(i), "roundrect", x, 1.15, 0.6, 1.0, '"*.Cu" "*.Mask"'))
    for i, x in enumerate([-0.95, 0.95], 4):
        out.append(pad(str(i), "roundrect", x, -1.15, 0.6, 1.0, '"*.Cu" "*.Mask"'))
    out += rect_line(-1.6, -1.6, 1.6, 1.6, "F.CrtYd", 0.05)
    out += rect_line(-1.45, 1.6, 1.45, 1.6, "F.SilkS")
    out.append(")")
    return name, out


def gen_sot23():
    """SOT-23 N-MOSFET (IR-array low-side switches Q1/Q2)."""
    name = "SOT-23"
    out = fp_header(name, "SOT-23 N-MOSFET low-side IR switch", "mosfet sot23")
    out += ref_val(name, 0, -3.5)
    out.append(pad("1", "roundrect", -0.95, 1.1, 0.6, 1.0, '"*.Cu" "*.Mask"'))
    out.append(pad("2", "roundrect", 0.95, 1.1, 0.6, 1.0, '"*.Cu" "*.Mask"'))
    out.append(pad("3", "roundrect", 0, -1.1, 0.6, 1.0, '"*.Cu" "*.Mask"'))
    out += rect_line(-1.6, -1.6, 1.6, 1.6, "F.CrtYd", 0.05)
    out += rect_line(-1.45, 1.6, 1.45, 1.6, "F.SilkS")
    out.append(")")
    return name, out


def gen_sot23_8():
    """SOT-23-8 fuel gauge (BQ27441)."""
    name = "SOT-23-8"
    out = fp_header(name, "SOT-23-8 fuel gauge BQ27441", "fuel gauge bq27441 sot23-8")
    out += ref_val(name, 0, -3.5)
    for i in range(4):
        out.append(pad(str(i + 1), "roundrect", -0.975 + i * 0.65, 1.15,
                       0.45, 0.9, '"*.Cu" "*.Mask"'))
        out.append(pad(str(8 - i), "roundrect", -0.975 + i * 0.65, -1.15,
                       0.45, 0.9, '"*.Cu" "*.Mask"'))
    out += rect_line(-1.7, -1.7, 1.7, 1.7, "F.CrtYd", 0.05)
    out += rect_line(-1.5, 1.7, 1.5, 1.7, "F.SilkS")
    out.append(")")
    return name, out


def gen_soic8():
    """SOIC-8 buck (3.8 V V_SYS)."""
    name = "SOIC-8"
    out = fp_header(name, "SOIC-8 buck converter", "buck regulator soic8")
    out += ref_val(name, 0, -4.5)
    # pads along left/right edges, 1.27 pitch
    for i in range(4):
        out.append(pad(str(i + 1), "roundrect", -1.905, 2.7 - i * 1.27,
                       1.5, 0.6, '"*.Cu" "*.Mask"'))
        out.append(pad(str(8 - i), "roundrect", 1.905, 2.7 - i * 1.27,
                       1.5, 0.6, '"*.Cu" "*.Mask"'))
    out += rect_line(-2.95, -2.75, 2.95, 2.75, "F.CrtYd", 0.05)
    out += rect_line(-1.95, 3.4, 1.95, 3.4, "F.SilkS")
    out += rect_line(-1.95, -3.4, 1.95, -3.4, "F.SilkS")
    out += circle((-2.4, 3.2), (-2.0, 3.2), "F.SilkS")
    out.append(")")
    return name, out


def gen_eg915u():
    """Quectel EG915U LTE Cat-1bis + GNSS LCC module ~17.7 x 16.9 mm.
    Castellated edge pads, illustrative numbering (datasheet pin map at layout).
    """
    name = "EG915U"
    W, H = 17.7, 16.9
    pw, ph = 1.6, 2.0
    out = fp_header(name, "Quectel EG915U LTE Cat-1bis + GNSS LCC 17.7x16.9mm (illustrative)",
                    "quectel eg915 lte cat1bis gnss lcc")
    out += ref_val(name, 0, -H / 2 - 2)
    n = 1
    for i in range(11):  # left column
        y = H / 2 - 1.0 - i * (H - 2.0) / 10
        out.append(pad(str(n), "rect", -W / 2 + 0.8, y, pw, 1.0, '"*.Cu"'))
        n += 1
    for i in range(8):   # bottom row
        x = -W / 2 + 2.5 + i * (W - 5.0) / 7
        out.append(pad(str(n), "rect", x, -H / 2 + 0.8, 1.0, pw, '"*.Cu"'))
        n += 1
    for i in range(11):  # right column
        y = -H / 2 + 1.0 + i * (H - 2.0) / 10
        out.append(pad(str(n), "rect", W / 2 - 0.8, y, pw, 1.0, '"*.Cu"'))
        n += 1
    for i in range(8):   # top row
        x = -W / 2 + 2.5 + i * (W - 5.0) / 7
        out.append(pad(str(n), "rect", x, H / 2 - 0.8, 1.0, pw, '"*.Cu"'))
        n += 1
    out += rect_line(-W / 2 - 0.4, -H / 2, -W / 2 - 0.4, H / 2, "F.SilkS")
    out += rect_line(W / 2 + 0.4, -H / 2, W / 2 + 0.4, H / 2, "F.SilkS")
    out += rect_line(-W / 2, -H / 2 - 0.4, W / 2, -H / 2 - 0.4, "F.SilkS")
    out += rect_line(-W / 2, H / 2 + 0.4, W / 2, H / 2 + 0.4, "F.SilkS")
    out += rect_line(-W / 2 - 0.65, -H / 2 - 0.65, W / 2 + 0.65, H / 2 + 0.65,
                     "F.CrtYd", 0.05)
    out += fp_text_user("GNSS ant region (keep-out)", 0, H / 2 + 2.2)
    out.append(")")
    return name, out


def gen_esp32c6():
    """ESP32-C6-WROOM-1 18 x 25.5 mm module. 19 castellated pads numbered to
    match the schematic symbol: left 1-8, bottom 9-11, right 12-19.
    Antenna keep-out at the top edge.
    """
    name = "ESP32-C6-WROOM-1"
    W, H = 18.0, 25.5
    out = fp_header(name, "ESP32-C6-WROOM-1 module 18x25.5mm (wake supervisor)",
                    "esp32 c6 wroom module ble wifi")
    out += ref_val(name, 0, -H / 2 - 2)
    n = 1
    for i in range(8):   # left column 1-8
        y = H / 2 - 5.0 - i * (H - 8.0) / 7
        out.append(pad(str(n), "rect", -W / 2 + 1.0, y, 1.8, 1.0, '"*.Cu" "*.Mask"'))
        n += 1
    for i in range(3):   # bottom row 9-11
        x = -3.0 + i * 3.0
        out.append(pad(str(n), "rect", x, -H / 2 + 1.0, 1.0, 1.8, '"*.Cu" "*.Mask"'))
        n += 1
    for i in range(8):   # right column 12-19
        y = -H / 2 + 5.0 + i * (H - 8.0) / 7
        out.append(pad(str(n), "rect", W / 2 - 1.0, y, 1.8, 1.0, '"*.Cu" "*.Mask"'))
        n += 1
    out += rect_line(-W / 2, H / 2 - 5.0, W / 2, H / 2 - 0.5, "F.Fab", 0.05)
    out += fp_text_user("ANT KEEP-OUT", 0, H / 2 - 2.7)
    out += rect_line(-W / 2 - 0.4, -H / 2 - 0.4, W / 2 + 0.4, H / 2 + 0.4,
                     "F.CrtYd", 0.05)
    out.append(")")
    return name, out


def gen_nano_sim():
    name = "NanoSIM_Push"
    pads = [
        ("1", -2.6, 1.75, 1.4, 1.6),   # VDD (C1)
        ("2", 0, 1.75, 1.4, 1.6),      # RST (C2)
        ("3", 2.6, 1.75, 1.4, 1.6),    # CLK (C3)
        ("4", -2.6, -1.75, 1.4, 1.6),  # GND (C5)
        ("6", 0, -1.75, 1.4, 1.6),     # DATA (C7)
        ("5", 2.6, -1.75, 1.4, 1.6),   # VPP (C6, nc for eSIM)
    ]
    out = fp_header(name, "nano-SIM push-push 6-pad (eSIM)", "sim nano esim")
    out += ref_val(name, 0, -5)
    for num, x, y, w, h in pads:
        out.append(pad(num, "roundrect", x, y, w, h, '"*.Cu" "*.Mask"'))
    out += rect_line(-6, -3, 6, 3, "F.CrtYd", 0.05)
    out.append(")")
    return name, out


def gen_lga12():
    name = "LGA-12_2x2mm"
    out = fp_header(name, "ST LIS2DW12 LGA-12 2x2mm", "accelerometer lga12 lis2dw12")
    out += ref_val(name, 0, -2.8)
    n = 1
    for row in [0.65, 0]:
        for i in range(4):
            x = -0.75 + i * 0.5
            out.append(pad(str(n), "roundrect", x, row, 0.3, 0.35, '"*.Cu"'))
            n += 1
    for i in range(4):
        x = 0.75 - i * 0.5
        out.append(pad(str(n), "roundrect", x, -0.65, 0.3, 0.35, '"*.Cu"'))
        n += 1
    out += rect_line(-1.25, -1.25, 1.25, 1.25, "F.CrtYd", 0.05)
    out.append(")")
    return name, out


def gen_usb_c():
    name = "USB_C_Receptacle_16P"
    pads = []
    for i, x in enumerate([-3.35, -2.25, 2.25, 3.35]):
        pads.append(("S%d" % (i + 1), x, 3.2, 1.0, 1.6))
    for i in range(6):
        pads.append((str(i + 1), -1.75 + i * 0.7, 0, 0.5, 2.6))
    out = fp_header(name, "USB-C 2.0 receptacle (service: modem fw + C6 flashing)",
                    "usb type-c 16p")
    out += ref_val(name, 0, -6)
    for num, x, y, w, h in pads:
        out.append(pad(num, "roundrect", x, y, w, h, '"*.Cu" "*.Mask"'))
    out += rect_line(-4.5, -2.5, 4.5, 4.5, "F.CrtYd", 0.05)
    out.append(")")
    return name, out


def gen_pinheader():
    name = "PinHeader_2x03_P2.54mm"
    out = fp_header(name, "2x03 through-hole pin header 2.54mm (factory programming)",
                    "pin header 2x03", attrs=("through_hole",))
    out += ref_val(name, 0, -5)
    n = 1
    for row in [1.27, -1.27]:
        for col in [-2.54, 0, 2.54]:
            out.append(pad(str(n), "circle", col, row, 1.7, 1.7,
                           '"*.Cu" "*.Mask"', drill=1.0))
            n += 1
    out += rect_line(-3.8, -2.5, 3.8, 2.5, "F.CrtYd", 0.05)
    out.append(")")
    return name, out


def gen_button():
    name = "Button_4x4mm"
    pads = [("1", -2.25, 1.0, 1.3, 1.2), ("2", 2.25, 1.0, 1.3, 1.2),
            ("3", -2.25, -1.0, 1.3, 1.2), ("4", 2.25, -1.0, 1.3, 1.2)]
    out = fp_header(name, "SMD tact switch 4x4mm (reset)", "button tact 4x4")
    out += ref_val(name, 0, -3.5)
    for num, x, y, w, h in pads:
        out.append(pad(num, "roundrect", x, y, w, h, '"*.Cu" "*.Mask"'))
    out += rect_line(-2.6, -1.9, 2.6, 1.9, "F.CrtYd", 0.05)
    out.append(")")
    return name, out


def gen_antenna():
    name = "Antenna_UMWiSE_1.6mm"
    out = fp_header(name, "GNSS patch antenna pad 1.6mm feed (under lid RF membrane)",
                    "antenna gnss patch pcb")
    out += ref_val(name, 0, -4)
    out.append(pad("1", "rect", 0, 0, 1.6, 3.0, '"*.Cu" "*.Mask"'))
    out += rect_line(-2.5, -2.5, 2.5, 2.5, "F.CrtYd", 0.05)
    out += fp_text_user("RF MEMBRANE KEEP-OUT", 0, 3.5)
    out.append(")")
    return name, out

def gen_soc_qfn():
    """SSC377Q-class camera SoC, QFN 9x9 mm, 0.4 mm edge pads (illustrative
    22/side) + 7x7 thermal pad. Pad 1 marker bottom-left.
    """
    name = "SSC377Q_QFN"
    W = 9.0
    out = fp_header(name, "SSC377Q camera SoC QFN 9x9mm 0.4mm pads (illustrative)",
                    "soc qfn camera ssc377")
    out += ref_val(name, 0, -7)
    n = 1
    edge = W / 2 - 0.4
    for i in range(22):  # left 1-22
        y = -edge + 0.6 + i * (2 * edge - 1.2) / 21
        out.append(pad(str(n), "rect", -edge, y, 0.8, 0.4, '"*.Cu"'))
        n += 1
    for i in range(22):  # bottom 23-44
        x = -edge + 0.6 + i * (2 * edge - 1.2) / 21
        out.append(pad(str(n), "rect", x, -edge, 0.4, 0.8, '"*.Cu"'))
        n += 1
    for i in range(22):  # right 45-66
        y = edge - 0.6 - i * (2 * edge - 1.2) / 21
        out.append(pad(str(n), "rect", edge, y, 0.8, 0.4, '"*.Cu"'))
        n += 1
    for i in range(22):  # top 67-88
        x = edge - 0.6 - i * (2 * edge - 1.2) / 21
        out.append(pad(str(n), "rect", x, edge, 0.4, 0.8, '"*.Cu"'))
        n += 1
    out.append(pad("89", "rect", 0, 0, 6.5, 6.5, '"*.Cu"'))  # thermal
    out += rect_line(-W / 2 - 0.4, -W / 2 - 0.4, W / 2 + 0.4, W / 2 + 0.4,
                     "F.CrtYd", 0.05)
    out += circle((-W / 2 - 0.6, -W / 2 - 0.6), (-W / 2 - 0.2, -W / 2 - 0.6),
                  "F.SilkS")
    out.append(")")
    return name, out


def gen_imx415_module():
    """IMX415 8.4 MP sensor module with lens: 22x22 mm body, lens barrel dia
    ~14 mm, 8-pad 0.5 mm FPC tail at the bottom. Lens faces the front panel
    (chassis lens port; keep-out note on F.Fab).
    """
    name = "IMX415_Module"
    W = 22.0
    out = fp_header(name, "IMX415 8.4MP sensor module + lens, 22x22mm, 8-pad FPC",
                    "sensor camera imx415 module fpc")
    out += ref_val(name, 0, -13)
    for i in range(8):
        x = -1.75 + i * 0.5
        out.append(pad(str(i + 1), "rect", x, -W / 2 - 0.8, 0.3, 1.6, '"*.Cu"'))
    out += rect_line(-W / 2, -W / 2, W / 2, W / 2, "F.SilkS")
    out += circle((0, 0), (7.0, 0), "F.SilkS")
    out += rect_line(-W / 2 - 0.4, -W / 2 - 1.6, W / 2 + 0.4, W / 2 + 0.4,
                     "F.CrtYd", 0.05)
    out += fp_text_user("LENS -> front panel port", 0, W / 2 + 2.0)
    out.append(")")
    return name, out

def gen_emmc():
    """JEDEC 153-ball eMMC BGA 11.5x13 mm. Illustrative full A1..K15 ball
    grid (0.8 mm pitch); consult the datasheet ball map at layout.
    """
    name = "eMMC_153"
    W, H = 11.5, 13.0
    rows, cols = 15, 11
    out = fp_header(name, "eMMC 153-ball BGA 11.5x13mm (illustrative ball map)",
                    "emmc bga 153 storage")
    out += ref_val(name, 0, -9)
    letters = "ABCDEFGHIJK"
    for r in range(rows):
        y = (rows - 1) * 0.4 - r * 0.8
        for c in range(cols):
            out.append(pad("%s%d" % (letters[c], r + 1), "circle",
                           (cols - 1) * 0.4 - c * 0.8, y, 0.35, 0.35, '"*.Cu"'))
    out += rect_line(-W / 2 - 0.3, -H / 2 - 0.3, W / 2 + 0.3, H / 2 + 0.3,
                     "F.CrtYd", 0.05)
    out += circle((-W / 2 - 0.5, -H / 2 - 0.5), (-W / 2 - 0.1, -H / 2 - 0.5),
                  "F.SilkS")
    out.append(")")
    return name, out


def gen_microsd():
    """microSD push-push slot ~15x14.5 mm: 8 contact pads along the top edge
    (illustrative) + 2 shell tabs. Symbol uses pads 1-6.
    """
    name = "microSD_Push"
    out = fp_header(name, "microSD push-push slot 15x14.5mm (overflow recording)",
                    "microsd slot push-push storage")
    out += ref_val(name, 0, -10)
    labels = ["1", "2", "3", "4", "5", "6", "7", "8"]
    for i, lab in enumerate(labels):
        out.append(pad(lab, "roundrect", -3.85 + i * 1.1, -6.0, 0.7, 1.6,
                       '"*.Cu" "*.Mask"'))
    for i, x in enumerate((-6.8, 6.8)):
        out.append(pad("S%d" % (i + 1), "rect", x, 3.5, 1.6, 2.4,
                       '"*.Cu" "*.Mask"'))
    out += rect_line(-7.5, -7.25, 7.5, 7.25, "F.SilkS")
    out += rect_line(-7.8, -7.55, 7.8, 7.55, "F.CrtYd", 0.05)
    out += fp_text_user("card ejection -> rear edge", 0, 9.0)
    out.append(")")
    return name, out
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

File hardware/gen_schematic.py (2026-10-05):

#!/usr/bin/env python3
"""Generate KiCad 7/10 schematics for the wapiti trail camera (wapiti).

Emitter style copied from the lugtrax hardware pipeline (see
/repos/utils/share/docs/kicad-skill.md): all symbols embedded inline
(wapiti: prefix), every wire endpoint computed from pin tips via tip()
helpers, nets that would cross symbol bodies use labels at pin tips.

Produces (from hardware/):
  wapiti.kicad_sch   - root sheet with four child sheets
  power.kicad_sch    - pack sled + AA tray + reserve cell, supercap, buck,
                       solar input with charge-interlock switch, fuel gauge
  radio.kicad_sch    - EG915U LTE Cat-1bis + GNSS, eSIM, SMA LTE antenna,
                       GNSS patch antenna, USB-C service port
  cam.kicad_sch      - SSC377Q SoC + IMX415 sensor + eMMC + microSD +
                       2in LCD + dual IR LED arrays on MOSFET switches
  mcu.kicad_sch      - ESP32-C6 co-processor + LIS2DW12 + PIR + mmWave
                       radar + status LED + USB-C + programming header

Validate with:  kicad-cli sch export svg <file> -o /tmp/out
"""

import os
import uuid


def u():
    return str(uuid.uuid4())


def fmt(v):
    s = "%.6f" % float(v)
    s = s.rstrip("0").rstrip(".")
    return s if s not in ("", "-0") else "0"


def rot_pt(x, y, rot):
    if rot == 90:
        return (-y, x)
    if rot == 180:
        return (-x, -y)
    if rot == 270:
        return (y, -x)
    return (x, y)


# ---------------------------------------------------------------------------
# Symbol library (wapiti: prefix). Pin tuples: (num, name, x, y, angle, len, type)
# where (x, y) is the CONNECTION TIP offset from the symbol origin.
# ---------------------------------------------------------------------------

def sym_resistor(sid):
    return {"id": sid, "hide_num": True, "pins": [
        ("1", "~", -2.54, 0, 0, 2.54, "passive"),
        ("2", "~", 2.54, 0, 180, 2.54, "passive")],
        "body": [("rect", (-1.016, -1.27, 1.016, 1.27))]}


def sym_capacitor(sid, polarized=False):
    pins = [("1", "+" if polarized else "~", 0, 2.54, 270, 2.54, "passive"),
            ("2", "~", 0, -2.54, 90, 2.54, "passive")]
    body = [("rect", (-1.524, -0.762, 1.524, 0.762))]
    if polarized:
        body.append(("poly", [(1.27, 0.635), (1.27, -0.635), (0.635, 0), (1.905, 0)]))
        body.append(("poly", [(0.635, -1.905), (1.905, -1.905)]))
    return {"id": sid, "hide_num": True, "pins": pins, "body": body}


def sym_diode(sid):
    return {"id": sid, "hide_num": True, "pins": [
        ("1", "A", -3.81, 0, 0, 2.54, "passive"),
        ("2", "K", 3.81, 0, 180, 2.54, "passive")],
        "body": [
            ("poly", [(-1.27, 1.27), (-1.27, -1.27), (1.27, 0), (-1.27, 1.27)]),
            ("rect", (1.27, -1.27, 1.905, 1.27))]}


def sym_tvs(sid):
    return {"id": sid, "hide_num": True, "pins": [
        ("1", "~", 0, 2.54, 270, 2.54, "passive"),
        ("2", "~", 0, -2.54, 90, 2.54, "passive")],
        "body": [
            ("rect", (-1.27, -0.762, 1.27, 0.762)),
            ("poly", [(-0.762, 0.762), (-0.762, -0.762), (-1.905, -0.762)]),
            ("poly", [(0.762, 0.762), (0.762, -0.762), (1.905, -0.762)])]}


def sym_fuse(sid):
    return {"id": sid, "hide_num": True, "pins": [
        ("1", "~", -2.54, 0, 0, 2.54, "passive"),
        ("2", "~", 2.54, 0, 180, 2.54, "passive")],
        "body": [("rect", (-0.635, -1.905, 0.635, 1.905))]}


def sym_battery(sid):
    return {"id": sid, "hide_num": True, "pins": [
        ("1", "+", 0, 3.81, 270, 2.54, "passive"),
        ("2", "-", 0, -3.81, 90, 2.54, "passive")],
        "body": [
            ("rect", (-2.54, -2.54, 2.54, 2.54)),
            ("poly", [(1.016, 1.016), (1.016, 2.794)]),
            ("poly", [(0.127, 1.905), (1.905, 1.905)]),
            ("poly", [(0.127, -1.905), (1.905, -1.905)])]}


def sym_load_switch(sid):
    """4-pin load switch: VIN(1) EN(2) VOUT(3) GND(4)."""
    return {"id": sid, "hide_num": False, "pins": [
        ("1", "VIN", -5.08, 0, 0, 2.54, "power_in"),
        ("2", "EN", -2.54, -5.08, 270, 2.54, "input"),
        ("3", "VOUT", 5.08, 0, 180, 2.54, "power_out"),
        ("4", "GND", 0, -5.08, 90, 2.54, "power_in")],
        "body": [("rect", (-2.54, -2.54, 2.54, 2.54))]}


def sym_buck(sid):
    """Buck regulator: VIN(1) EN(2) SW(3) GND(4) FB(5). SW drives an
    external inductor to V_SYS; FB senses the V_SYS divider."""
    return {"id": sid, "hide_num": False, "pins": [
        ("1", "VIN", -5.08, 2.54, 0, 2.54, "power_in"),
        ("2", "EN", -5.08, 0, 0, 2.54, "input"),
        ("3", "SW", -5.08, -2.54, 0, 2.54, "power_out"),
        ("4", "GND", 0, -5.08, 90, 2.54, "power_in"),
        ("5", "FB", 5.08, -2.54, 180, 2.54, "input")],
        "body": [("rect", (-2.54, -2.54, 2.54, 2.54))]}


def sym_inductor(sid):
    return {"id": sid, "hide_num": True, "pins": [
        ("1", "~", -2.54, 0, 0, 2.54, "passive"),
        ("2", "~", 2.54, 0, 180, 2.54, "passive")],
        "body": [
            ("poly", [(-1.27, -1.27), (-1.27, 1.27)]),
            ("poly", [(0, -1.27), (0, 1.27)]),
            ("poly", [(1.27, -1.27), (1.27, 1.27)])]}


def sym_conn2(sid):
    """Generic 2-pin connector (solar input, SMA bulkhead)."""
    return {"id": sid, "hide_num": False, "pins": [
        ("1", "1", -2.54, 0, 0, 2.54, "passive"),
        ("2", "2", 2.54, 0, 180, 2.54, "passive")],
        "body": [("rect", (-1.27, -1.905, 1.27, 1.905))]}


def sym_gauge(sid):
    """BQ27441-class fuel gauge: VDD GND SDA SCL INT BAT SRN."""
    return {"id": sid, "hide_num": False, "pins": [
        ("1", "VDD", -5.08, 7.62, 0, 2.54, "power_in"),
        ("2", "GND", -5.08, 5.08, 0, 2.54, "power_in"),
        ("3", "SDA", 5.08, 5.08, 180, 2.54, "bidirectional"),
        ("4", "SCL", 5.08, 2.54, 180, 2.54, "input"),
        ("5", "INT", 5.08, 0, 180, 2.54, "output"),
        ("6", "BAT", 5.08, -2.54, 180, 2.54, "passive"),
        ("7", "SRN", 5.08, -5.08, 180, 2.54, "passive")],
        "body": [("rect", (-2.54, -3.81, 2.54, 5.08))]}
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

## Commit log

2026-10-05 Initial commit: wapiti cellular trail camera — docs + regenerable hardware
    Product docs (project plan, test plan with 293 test IDs, competitive
    analysis, Tactacam REVEAL research) and the full hardware pipeline:
    KiCad schematics/footprints/PCB with Python generators and validate.sh,
    parametric chassis generator with STL/OBJ/PNG/SVG outputs, KiCad exports
    (PDFs, SVG, STEP, 3D renders), plus READMEs embedding the artifacts.
    Everything regenerates from scripts; generated outputs are committed
    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
    [cam.kicad_sch, mcu.kicad_sch, power.kicad_sch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]
2026-10-05 Fix GitHub rendering: ASCII diagrams for sections 3 and 8.1
    GitHub's mermaid renderer rejects parentheses even inside quoted
    flowchart labels and sequence participant aliases (parse error "got
    'PS'"). Convert the architecture diagram and heartbeat sequence diagram
    to fenced ASCII art that renders verbatim everywhere, and de-paren the
    gantt task names. ER diagram, capture flowchart and gantt keep mermaid.
    🤖 Generated with Codebuff
2026-10-05 Cellular link discipline: retries, idempotency, fleet storm protection
    Apply the cellular-retry engineering material from
    interview-questions/interview_cellular_retries_qa.md to the camera:
    new project-plan section 8.6 with per-class backoff + full jitter,
    transient-vs-permanent classification, Idempotency-Key dedup on the
    device API, outbox durability, modem circuit breaker, RSRP gating,
    fleet retry budget and staggered reconnect; risk row 12. New tests
    NET-11..18 (fake-clock backoff, replay dedup, reboot-survival, signal
    gating, breaker, storm + reconnect soaks); catalog grows to 301 IDs.
    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
2026-10-25 docs: follow the luggage-tracker rename to lugtrax
    Sibling references pointed at the old folder path and project name.
    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
2026-10-26 docs: operator-access note joins the house tailnet over https
    The headscale operator-access note now uses https://<host>:4443 plus the
    one-time trust of headscale's self-signed cert (TLS since 2026-10-26).
    Generated with Codebuff 🤖
2026-10-27 Land the wapiti server, builders and test harness (WI-101 → WI-104)
    Laravel 12 + MongoDB backend with the WebAuthn auth contract (WI-101),
    14-collection schema + migrations (WI-102), nginx TLS site on :4444 with
    builder/test one-shot images and service scripts (WI-103), and the device
    ingest API at /device/v1/* (WI-104). The catalog-authority suite
    (tests/test.py) and the infra runner (tests/regression.py) back it: 49 of
    307 IDs green. Report IDs now map test families to catalog prefixes, so
    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
